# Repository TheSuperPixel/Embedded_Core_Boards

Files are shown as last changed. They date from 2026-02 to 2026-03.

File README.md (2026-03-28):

# 高性能嵌入式核心板套件
## 简介
早在2025年3月的时候，我便想自己设计一套高性能嵌入式系统核心板，主要由MCU、LINUX、FPGA三大部分组成。经过一年左右的学习、设计、焊接和调试，终于全部完成了。目前本开源项目包含RK3588核心板、XC7A35T核心板、STM32H750核心板、全志H616核心板四款板卡。其中RK3588核心板的设计和制作极其复杂和艰难，背后有很多的故事。


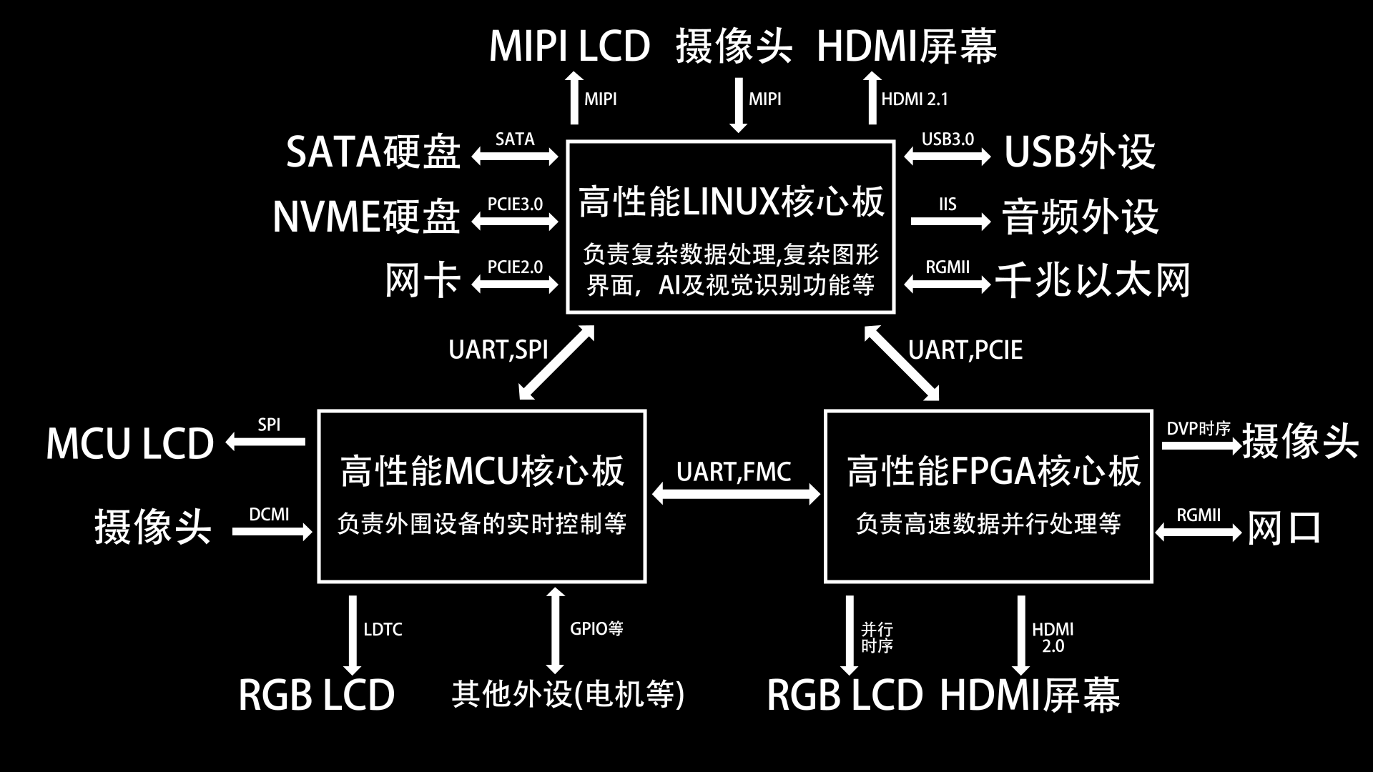
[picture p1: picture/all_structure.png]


## 演示视频
RK3588核心板：https://www.bilibili.com/video/BV1JvcFzpEEX <br>
XC7A35T核心板： https://www.bilibili.com/video/BV11gFkz1Ezn <br>
STM32H750核心板：https://www.bilibili.com/video/BV1rnFhzgESg <br>

## 使用方法
### RK3588 文件夹
RK3588核心板套件的项目资料，详情请阅读文件夹内README文档。<br>

### XC7A35T 文件夹
XC7A35T核心板套件的项目资料，详情请阅读文件夹内README文档。<br>

### STM32H750 文件夹
STM32H750核心板套件的项目资料，详情请阅读文件夹内README文档。<br>

### H616 文件夹
H616核心板套件的项目资料，详情请阅读文件夹内README文档。<br>

## 注意事项
1.请严格遵守开源协议，若需要转载分享仓库内容，请注明来源。不得擅自将本设计用于商业用途。<br>
2.本项目仅供个人研究、学习与交流。元器件、封装、原理图和PCB设计等已根据数据手册重新校验或绘制。若您认为本项目中不慎包含了侵犯您版权的内容，请及时联系，我将第一时间予以处理。
## 主要参考资料
见各核心板项目文件夹内README文档。

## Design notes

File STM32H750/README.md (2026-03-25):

# STM32H750核心板
## 简介
这是我参考反客科技的STM32H750XBH6板子绘制的STM32H750核心板+底板套件，核心板上包含STM32H750XBH6主芯片，外挂32位的16M的大小的SDRAM和32M的FLASH，其余引脚全引出。底板上有摄像头接口、LCD屏幕接口等，还有一个DAP-LINK调试器，只要使用typec线连接电脑，便可以调试程序。

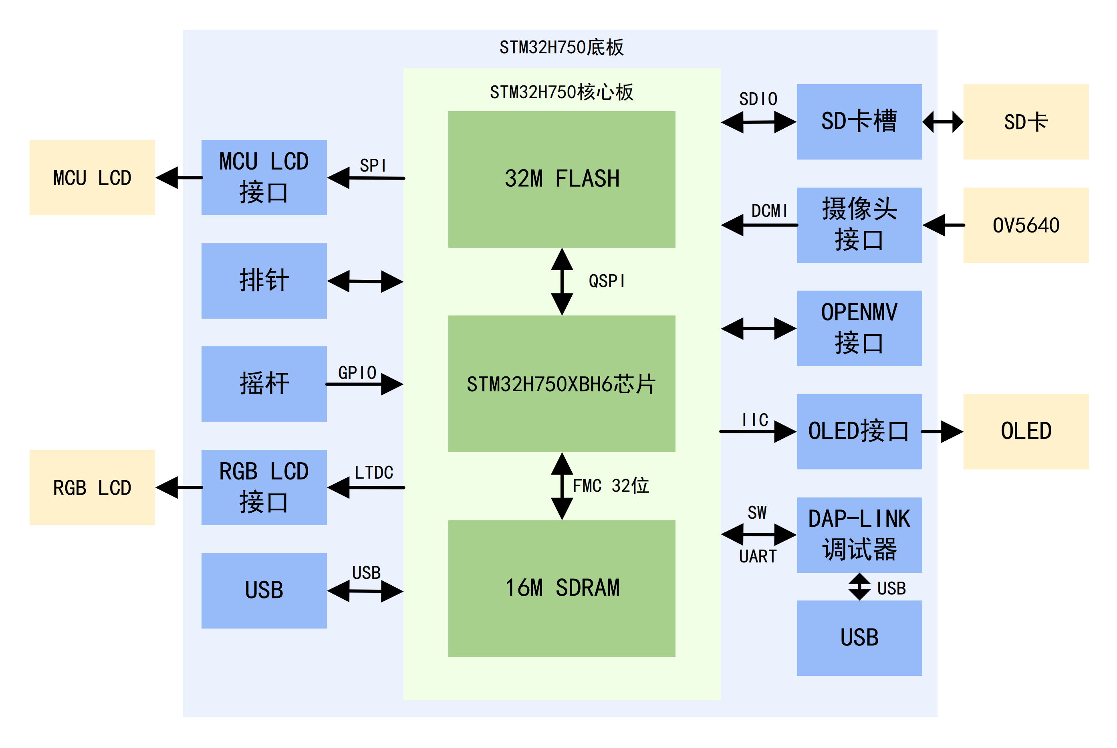
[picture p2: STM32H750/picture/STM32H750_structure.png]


## 演示视频
https://www.bilibili.com/video/BV1rnFhzgESg

## 使用方法
### STM32H750核心板v1 文件夹
第1版核心板的AD工程，已打板测试，需要在嘉立创使用JLC06161H-3313阻抗来打板。此版本的USB部分未经过优化，可能会出现USB无法连接的情况<br>
晶振"X1"应焊接25M晶振，原理图有误； 电容"C32" "C33"均为6pf，原理图有误<br>
进行DRC检查的时候会在板对板连接器固定孔处出现DRC报错，可以忽略，不影响正常电气功能
### STM32H750核心板v2 文件夹

第2版核心板的AD工程，已打板测试，需要在嘉立创使用JLC06161H-3313阻抗来打板。此版本的USB部分已经过优化，所有功能测试正常<br>
晶振"X1"应焊接25M晶振，原理图有误； 电容"C32" "C33"均为6pf，原理图有误<br>
进行DRC检查的时候会在板对板连接器固定孔处出现DRC报错，可以忽略，不影响正常电气功能

### 底板v1 文件夹
第1版底板的AD工程，已打板测试，阻抗无要求。此版本的USB部分未经过优化，可能会出现USB无法连接的情况<br>
进行DRC检查的时候会在板对板连接器固定孔处出现DRC报错，可以忽略，不影响正常电气功能

### 底板v2 文件夹
第2版底板的AD工程，已打板测试，阻抗无要求。此版本的USB部分已经过优化，所有功能测试正常<br>
进行DRC检查的时候会在板对板连接器固定孔处出现DRC报错，可以忽略，不影响正常电气功能

### 0.96寸OLED
0.96寸OLED的AD工程，已打板测试，阻抗无要求。功能正常<br>
支持IIC、SPI以及并口驱动模式，按照元器件的默认值焊接为IIC驱动模式。其中R14和R15排阻作用是选择顶部IIC排针焊盘的电气连接方向，需要选择一个焊接排阻，另一个不焊接。

### 1.69寸SPI接口彩色液晶
1.69寸SPI接口彩色液晶的AD工程，已打板测试，阻抗无要求。功能正常<br>
二极管"D1"的方向画反了，焊接的时候需要按照实际正确方向焊接

### 4.3寸触摸屏
4.3寸触摸屏的AD工程，已打板测试，阻抗无要求。功能正常<br>
驱动板支持正点原子排线线序和反客排线线序，具体位置可查看PCB丝印

### ov5640摄像头
ov5640摄像头的AD工程。已打板测试，阻抗无要求。功能正常<br>
驱动板支持正点原子排线线序和反客排线线序，具体位置可查看PCB丝印<br>
二极管"D1"的方向画反了，焊接的时候需要按照实际正确方向焊接

### 外壳
存放着外壳亚克力设计文件

### 测试例程
存放着测试例程代码，主要参考反客科技STM32H750XBH6资料和江协科技OLED程序

### 其他资料
存放着DAP-LINK固件(推荐使用串口烧录)、调试时记录的《STM32H750调试笔记》

## 主要参考资料
1.反客科技STM32H750XBH6板子 https://www.taobao.com/list/dianpu/212360197.htm<br>
2.江协科技OLED程序 https://jiangxiekeji.com/download.html<br>
3.正点原子RGB LCD 液晶屏资料 http://47.111.11.73/docs/industry/4-lcd/4.3-RGBLCD-800480.html<br>
4.正点原子OV5640资料 http://47.111.11.73/docs/industry/6-other/ov5640.html<br>
5.正点原子OLED资料 http://47.111.11.73/docs/industry/6-other/OLED.html<br>
6.CMSIS DAP LINK设计 https://oshwhub.com/Southerly/daplink-fang-zhen-qi-swd

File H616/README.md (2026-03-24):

# H616核心板
## 简介
这是我在2025年3月的时候参考柚木鉉大佬的Yuzuki Chameleon H616卡片电脑绘制的全志H616开发板，核心板上带有一个无线网卡和EMMC，底板引出了一个USB OTG接口，一个SD卡接口，三个USB host接口一个HDMI接口还有一个网口。


## 使用方法
### H616核心板 文件夹
H616核心板的AD工程，已打板测试，可正常启动，通过串口进入Linux系统。需要在嘉立创使用JLC06161H-3313阻抗来打板。<br>
测试失败的外设：目前EMMC测试失败，导致系统只能从SD卡启动<br>
未测试的外设：板载无线网卡。因为当时2025年3月时我编译驱动一直报错，所以无法测试。

### H616底板 文件夹
H616底板的AD工程，已打板测试。当时是在捷配上面打板的，并向板厂指定了HDMI主要信号线差分100欧姆的阻抗、指定了HDMI其他信号线单端50欧姆的阻抗。如果要在嘉立创打板，需要重新修改线宽。<br>
测试通过的外设：USB OTG接口、SD卡接口、2个USB HOST接口、HDMI接口<br>
测试失败的外设：其中一个USB HOST接口<br>
未测试的外设：网口<br>

### 外壳 文件夹
存放着外壳亚克力设计文件

### 其他资料
存放着调试时记录的《H616调试笔记》

## 主要参考资料
1.Yuzuki Chameleon H616卡片电脑演示视频 https://www.bilibili.com/video/BV1KB4y1z79U<br>
2.Yuzuki Chameleon H616卡片电脑固件和文档资料 https://github.com/YuzukiHD/YuzukiChameleon<br>
3.Yuzuki Chameleon H616卡片电脑硬件资料 https://oshwhub.com/gloomyghost/yuzukih616<br>
This hardware design is a derivative of Yuzuki Chameleon and is licensed under CERN Open Hardware License.

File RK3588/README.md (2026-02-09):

# RK3588核心板
## 简介
这是我参考野火鲁班猫5BTB开发板绘制的RK3588 Linux电脑板卡，核心板性能非常强，有8核高性能CPU，还有GPU，NPU等，还有8GB DDR4运行内存，64GB EMMC存储等。配套底板主要含有PCIE 3.0、HDMI 2.1接口、全功能typec、USB 3.0、SATA、MIPI接口、千兆网口、耳机、喇叭、调试串口、RTC等。


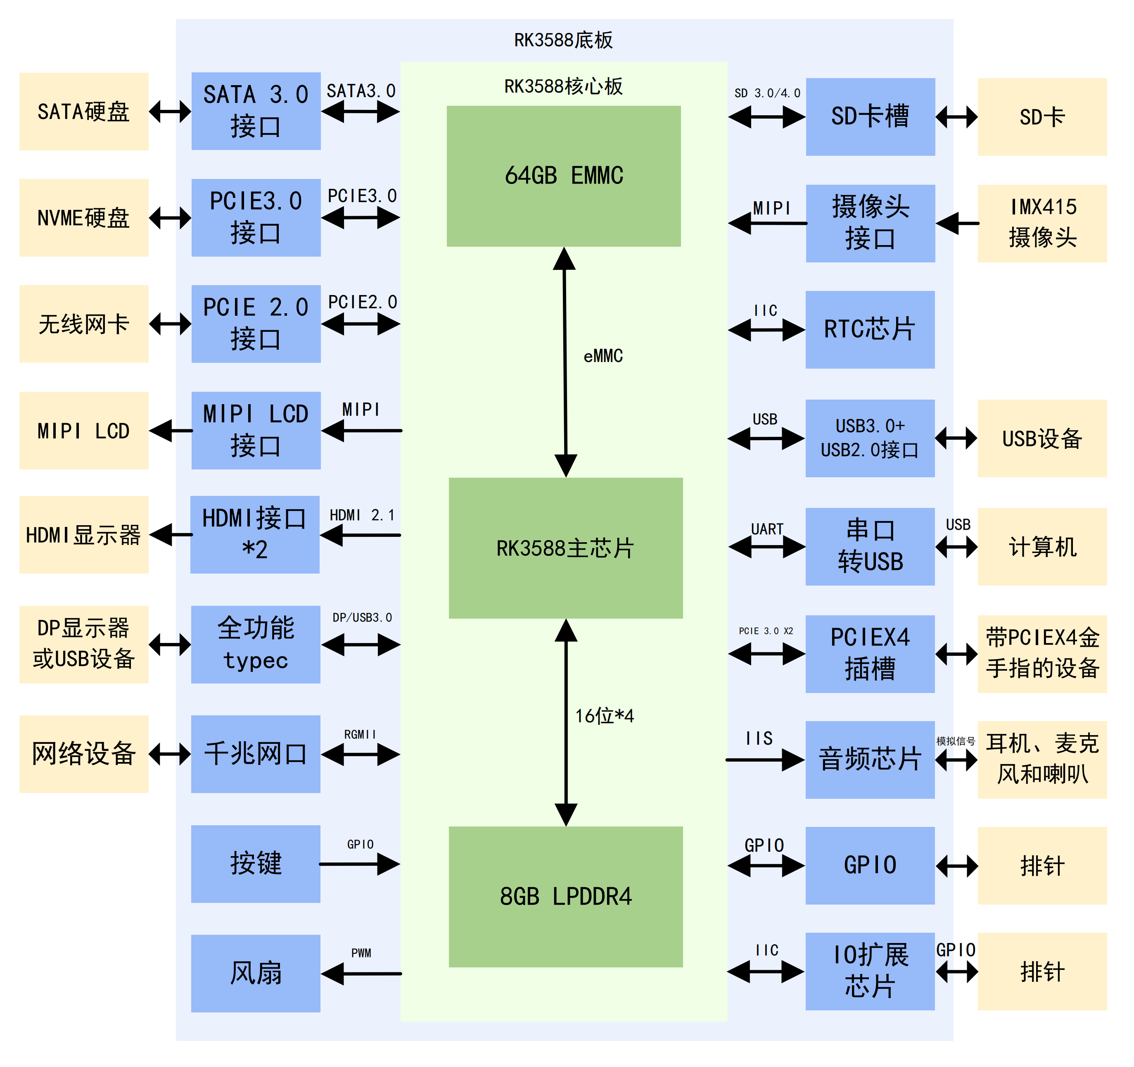
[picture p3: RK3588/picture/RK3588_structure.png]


## 演示视频
https://www.bilibili.com/video/BV1JvcFzpEEX <br>
https://www.xiaohongshu.com/discovery/item/6963a1a3000000001a0259af

## 使用方法
### RK3588核心板 文件夹
RK3588核心板的AD工程，已打板测试，可正常启动，通过串口进入Linux系统。需要在嘉立创使用JLC06161H-3313阻抗来打板。<br>

### RK3588底板 文件夹
RK3588底板的AD工程，已打板测试。需要在嘉立创使用JLC06161H-3313阻抗来打板。<br>

测试通过的接口：PCIE 3.0接口(M2 M KEY，连接NVME硬盘)、PCIE 2.0接口(M2 E KEY，连接无线网卡)、MIPI LCD接口、全功能typec接口、千兆网口、风扇、SD卡槽、摄像头接口、RTC芯片、USB3.0接口、USB2.0接口、串口转USB、音频芯片的耳机接口的扬声器、音频芯片的板载喇叭、音频芯片的板载麦克风。<br>

测试失败的接口：<br>
1.四个启动相关的按钮中，recovery按钮按下后会进入maskroom模式而不是loader模式。目前原因不明。<br>
2.HDMI TX0连接不稳定；HDMI TX1测试失败，目前推测可能是因为核心板电源完整性问题引起的。<br>

未测试的接口：SATA3.0接口、PCIEX4插槽、音频芯片的耳机接口的麦克风、与排针连接的IO扩展芯片的对应引脚和RK3588芯片的对应引脚。

### 5.5寸MIPI屏幕 文件夹
5.5寸MIPI屏幕的AD工程，已打板测试，功能正常。需要在嘉立创使用JLC04161H-3313阻抗来打板。

### IMX415摄像头 文件夹
IMX415摄像头的AD工程，已打板测试，功能正常。需要在嘉立创使用JLC04161H-3313阻抗来打板。

### 外壳 文件夹
存放着外壳亚克力设计文件

### 设备树 文件夹
存放着适配本板卡的设备树文件。<br>
设备树/rk3588-pixelcard-core.dts：单独核心板运行所需的设备树<br>
设备树/rk3588-pixelcard.dts：核心板+底板运行所需的设备树<br>

因为适配板卡系统镜像过大，所以不放在本仓库中。要获得适配板卡的系统镜像，有2个方式：<br>
方法1.将本设备树搭配鲁班猫的LubanCat_Gen_SDK使用，在SDK里面添加这个设备树并重新编译内核与系统。操作思路详见本项目里的《RK3588调试笔记》1-3。具体方法详见野火鲁班猫官网的《嵌入式Linux镜像构建与部署—基于LubanCat-RK系列板卡》。<br>
方法2.在鲁班猫成品系统上面直接替换设备树，换成本文件夹里面的设备树(我自己还没有尝试过)。具体方法详见野火鲁班猫官网的《嵌入式Linux镜像构建与部署—基于LubanCat-RK系列板卡》。<br>

### 其他资料
存放着调试时记录的《RK3588调试笔记》1-3、《RK3588电源调试》、《参考的开源项目汇总》

## 背后的故事
&emsp;&emsp;从2024年1月大二上学期，用树莓派做了很多项目后，我逐渐对树莓派的软件底层和硬件结构产生强烈的好奇，想要自制一个树莓派，不料树莓派的底层软硬件是闭源的，根本就没有办法自制。后来我通过网上搜索的方式知道，树莓派就是一个Linux开发板。在9月份电赛结束之后，我开始了漫长的嵌入式Linux的学习。<br>
&emsp;&emsp;2024年9月大三上开学的时候，我开始看韦东山的0基础驱动与应用开发视频教程，开始的时候，我学得非常吃力，发现原来是因为我的C语言知识过于薄弱造成的。等到后面补完C语言知识，如函数指针，编译优化和结构体对齐等细节之后，我继续看完了韦东山的基础视频。这时候已经是大三上学期结束，进入寒假了。寒假期间，我照着网上墨云大佬的f1c200s项目开始学习，在原本的基础上，加了一个小键盘，做了一个带全键盘的便携Linux小电脑，在这个项目中，我初步了解了嵌入式Linux的系统移植过程。<br>
&emsp;&emsp;之后2025年3月大三下的时候，我想要做更复杂的性能更强的Linux板子，并且能够流畅地运行图形化界面，甚至能够运行AI推理，于是我去网上找新的开源项目。我发现网上一个叫柚木鉉的大佬做的全志H616小电脑，它的图形化界面演示视频吸引了我，并且他的硬件资料也是完整的。可是在硬件制作完成之后，我发现软件资料较少，并且没有教程文档。很多东西都需要自己编译，我还碰到了很多报错，问网上大佬并没有得到非常详细的回答，这时候才知道我的Linux基础有非常大的欠缺，于是我决定重新开始学习嵌入式Linux。<br>
&emsp;&emsp;这时已经是大三下了，保研进入了最后的时期，绩点英语科研竞赛一样都不能落下，还要准备夏令营预推免面试的东西。但是我还是想每天抽点时间来弄一点我自己真正喜欢的东西，我开始阅读琢磨正点原子的Linux开发教程文档，从最基础的cortex-A汇编，C语言裸机，再到uboot源码，Linux内核源码的分析，根文件系统的移植等。断断续续地看了好几个月。在此期间，我被Linux底层原理和处理器底层深深地吸引了，经常看得停不下来。<br>
&emsp;&emsp;在大三下期间，我也开始了新的自制开发版的芯片选型。我看重了瑞芯微最强的RK3588芯片。这个芯片性能非常强，有8核CPU，还有高性能GPU和NPU等。选完芯片之后，我开始挑选对应的开发板来作为设计参考。首先，我选择了我熟悉的正点原子，买了它家的RK3588开发版，可是等到开发版买来之后，我就发现正点原子不提供3588核心板的原理图，连PDF都没有！慢慢地，通过了解多个商家的开发板，我发现许多商家虽然宣传他们开源了很多资料，可是他们基本上只公开软件资料，而硬件资料的公开程度非常有限。而软件资料通常是跟他们对应的硬件资料强绑定的，必须要购买它们家的板子，他们的开源资料才能得到充分的使用。在失望了很长一段时间之后，我又开始选择新的开发版，这次我选择了野火鲁班猫系列的开发板，他们的鲁班猫资料特别全，从核心板硬件原理图到SDK软件包，再到相关的教程文档都非常全。于是我选择购买了鲁班猫的板卡进行复刻。<br>
&emsp;&emsp;在2025年9月大四上学期，保研结束之后，我终于有大量时间来继续做这些事情。从保研结束到11月开始，我陆陆续续看完正点原子的Linux驱动开发、应用开发和QT开发，前前后后有3000多页，记了200多页笔记，含有30多页思维导图和几十张代码逻辑剖析图。此时已经是2025年11月，我终于能够正式的进入RK3588的设计。我找来了瑞芯微官方的硬件设计指南，开始详细的研究鲁班猫5的核心板设计，在完全理解核心板设计内容之后，我便开始了我的RK3588核心板的设计，我在保障板子可以启动Linux的前提下，在参考鲁班猫板卡基础上，修改了大量的硬件外设，使得核心板可以不依赖底板，可以单独启动，并符合嘉立创六层免费打板工艺。核心板性能非常强，有8核高性能CPU，还有GPU，NPU等，还有8GB DDR4运行内存，64GB EMMC存储等。配套底板主要含有PCIE 3.0、HDMI 2.1接口、全功能typec、USB 3.0、SATA、MIPI接口等。<br>
&emsp;&emsp;在绘制过程中，我碰到非常多的问题，我需要在官方硬件设计指南和嘉立创的六层免费打版工艺之间做出合理的权衡，来使得板卡既能运行，又符合嘉立创工艺。其中DDR布线改了三四版，耗时接近一周。核心板画了一个月之后终于画完了，后面两周的焊接调试阶段里，遇到各种各样的电源完整性，虚焊以及Linux内核配置等问题。好在后面通过抓取波形，重新焊接，更换器件和修改设备树等方法，基本解决了问题。在绘制过程中，我记录了非常详细的笔记，便于梳理排查思路，以做出正确的排查方向决策。之后，在2025年12月中旬，核心板终于能够正常的启动Linux系统了！！！<br>
&emsp;&emsp;这个工程实在是太复杂了，涉及了非常多硬件底层和软件底层方面的东西，并且这些东西在网上资料是相对较少的，基本上很难获取。更困难的是，周围同学对嵌入式Linux的理解几乎都是在应用方面，他们在基本上都是为了打比赛或做课设等目的，使用树莓派来进行开发，来快速实现功能，而没有去学习了解一些底层的东西。因此我碰到相关问题只能通过咨询网上大佬，很难得到及时详细回复。更多时候需要自己查资料问AI来解决。我终于突破了厂商的闭源资料的限制，克服了复杂的硬件设计、极其精细的焊接工艺、复杂的Linux内核驱动代码等带来的困难，做出了自己的第一套高性能核心板！！非常感谢正点原子详细的学习教程、野火的详细的资料、各位开源大佬的无私奉献和解答，给我了很多思路和灵感。<br>

## 主要参考资料
1.野火鲁班猫官网 https://doc.embedfire.com/linux/rk356x/quick_start/zh/latest/README.html#<br>
2.瑞芯微官方的《Rockchip RK3588 硬件设计指南》<br>
3.《参考的开源项目汇总》内出现的所有开源项目。由于项目过多，此处不一一列举，详情请查看对应文件。

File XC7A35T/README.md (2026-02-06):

# XC7A35T核心板
## 简介
这是我参考正点原子达芬奇开发板绘制的Xilinx XC7A35T板卡，上面有若干个按钮和LED，还有RGB LCD接口、HDMI接口、网口、SD卡槽、摄像头接口和PCIE金手指接口等外设。还自带Xilinx调试器和两路串口，通过底板自带的USB HUB芯片完成USB信号合并，只需通过一根typec线就可以同时完成供电、FPGA调试和串口收发信息。


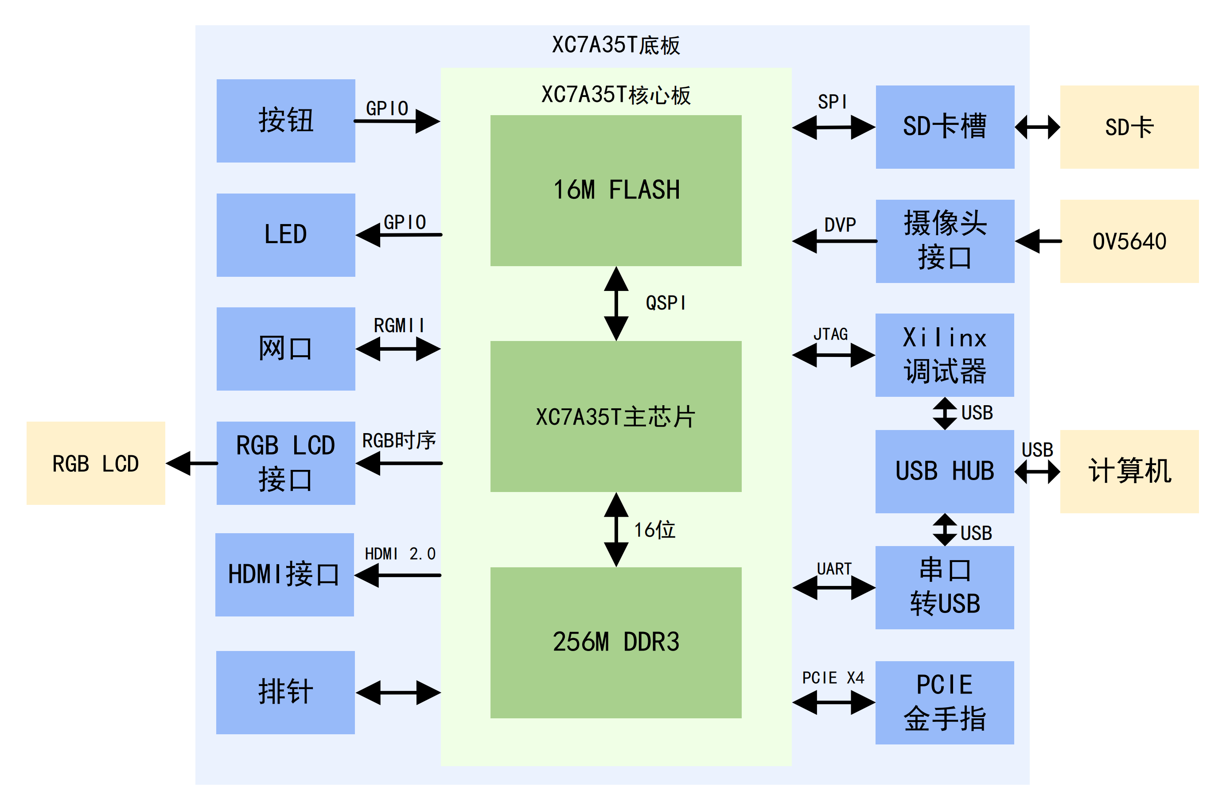
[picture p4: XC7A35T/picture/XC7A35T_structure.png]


## 演示视频
https://www.bilibili.com/video/BV11gFkz1Ezn

## 使用方法
### XC7A35T核心板 文件夹
XC7A35T核心板的AD工程，已打板测试。需要在嘉立创使用JLC06161H-3313阻抗来打板。其中器件U6在 Mechanical1 层上有异常线条，需要手动删除，否则导出Gerber文件时，会出现铜箔短路的问题，导致板子报废无法使用<br>

### XC7A35T底板v1 文件夹
XC7A35T底板v1的AD工程，已打板测试。需要在嘉立创使用JLC04161H-3313阻抗来打板。按钮、LED，RGBLCD接口、HDMI接口、SD卡槽、摄像头接口测试正常。网口测试失败，可能是网口电路布局布线不合理引起的

### XC7A35T底板v2 文件夹
XC7A35T底板v2的AD工程，此版更换了以太网PHY芯片，并优化了网口电路的布局布线，并增加PCIE金手指接口和12V电源输入接口，已打板测试。需要在嘉立创使用JLC04161H-3313阻抗来打板。按钮、LED，RGBLCD接口、HDMI接口、SD卡槽、摄像头接口测试正常。网口进行MDIO测试时，电脑仅能识别到百兆网，而且FPGA板子上用来指示网口速度的用户LED不亮，可能是网口电路布局布线不合理引起的<br>
器件D6、D7、D8在 Mechanical1 层上有异常线条，需要手动删除，否则导出Gerber文件时，会出现铜箔短路的问题，导致板子报废无法使用<br>
电解电容C61画反了，实际焊接的时候需要按照正确方向焊接

### XC7A35T底板v3 文件夹
XC7A35T底板v3的AD工程，此版进一步优化了网口电路的布局布线，已打板测试。需要在嘉立创使用JLC04161H-3313阻抗来打板。按钮、LED，RGBLCD接口、HDMI接口、SD卡槽、摄像头接口测试正常。和之前一样，网口进行MDIO测试时，电脑仅能识别到百兆网，而且FPGA板子上用来指示网口速度的用户LED不亮。目前原因不明。<br>
电解电容C61画反了，实际焊接的时候需要按照正确方向焊接

### 外壳
存放着外壳亚克力设计文件

### 测试例程
存放着测试例程代码，主要参考正点原子达芬奇FPGA资料。

### 其他资料
存放着xilinx下载器固件、调试时记录的《XC7A35T调试笔记》

### 其他
4.3寸触摸屏和ov5640摄像头的AD工程位于STM32H750开发板的资料底下，请到对应位置查找

## 主要参考资料
1.正点原子达芬奇FPGA开发板资料 http://47.111.11.73/docs/book-videos/zdyzshipin/3fpga/dfq.html<br>
2.正点原子RGB LCD 液晶屏资料 http://47.111.11.73/docs/industry/4-lcd/4.3-RGBLCD-800480.html<br>
3.正点原子OV5640资料 http://47.111.11.73/docs/industry/6-other/ov5640.html?highlight=ov5640<br>
4.给FT232芯片烧录固件作为Xilinx下载器的方法 https://blog.csdn.net/weixin_42741023/article/details/106462147

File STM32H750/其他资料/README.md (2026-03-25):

# Third-Party Source Notice (第三方代码声明)

## 来源说明
本目录下的文件来自 https://oshwhub.com/Southerly/daplink-fang-zhen-qi-swd

## 版权与协议 (Copyright & License)
* **版权归属：** 版权归原作者所有。
* **引用目的：** 本项目仅将其作为硬件验证的参考驱动使用。

## 免责声明
本项目作者 (TheSuperPixel) 不对本目录下的文件质量、稳定性或潜在侵权风险负责。

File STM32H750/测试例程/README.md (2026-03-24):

# Third-Party Source Notice (第三方代码声明)

## 来源说明
本目录下的OLED文件夹代码及工程文件（包括但不限于底层驱动、寄存器配置、初始化脚本）由 **江协科技** 提供。<br>
本目录下的其他文件夹代码及工程文件（包括但不限于底层驱动、寄存器配置、初始化脚本）由 **反客科技** 提供。

## 版权与协议
* **版权归属：** 版权归原作者所有。
* **引用目的：** 本项目仅将其作为硬件验证的参考驱动使用。

## 免责声明
本项目作者 (TheSuperPixel) 不对本目录下的代码质量、稳定性或潜在侵权风险负责。

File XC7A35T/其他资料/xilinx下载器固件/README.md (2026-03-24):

# Third-Party Source Notice (第三方代码声明)

## 来源说明
本目录下的文件来自 https://blog.csdn.net/weixin_42741023/article/details/106462147

## 版权与协议 (Copyright & License)
* **版权归属：** 版权归原作者所有。
* **引用目的：** 本项目仅将其作为硬件验证的参考驱动使用。

## 免责声明
本项目作者 (TheSuperPixel) 不对本目录下的文件质量、稳定性或潜在侵权风险负责。

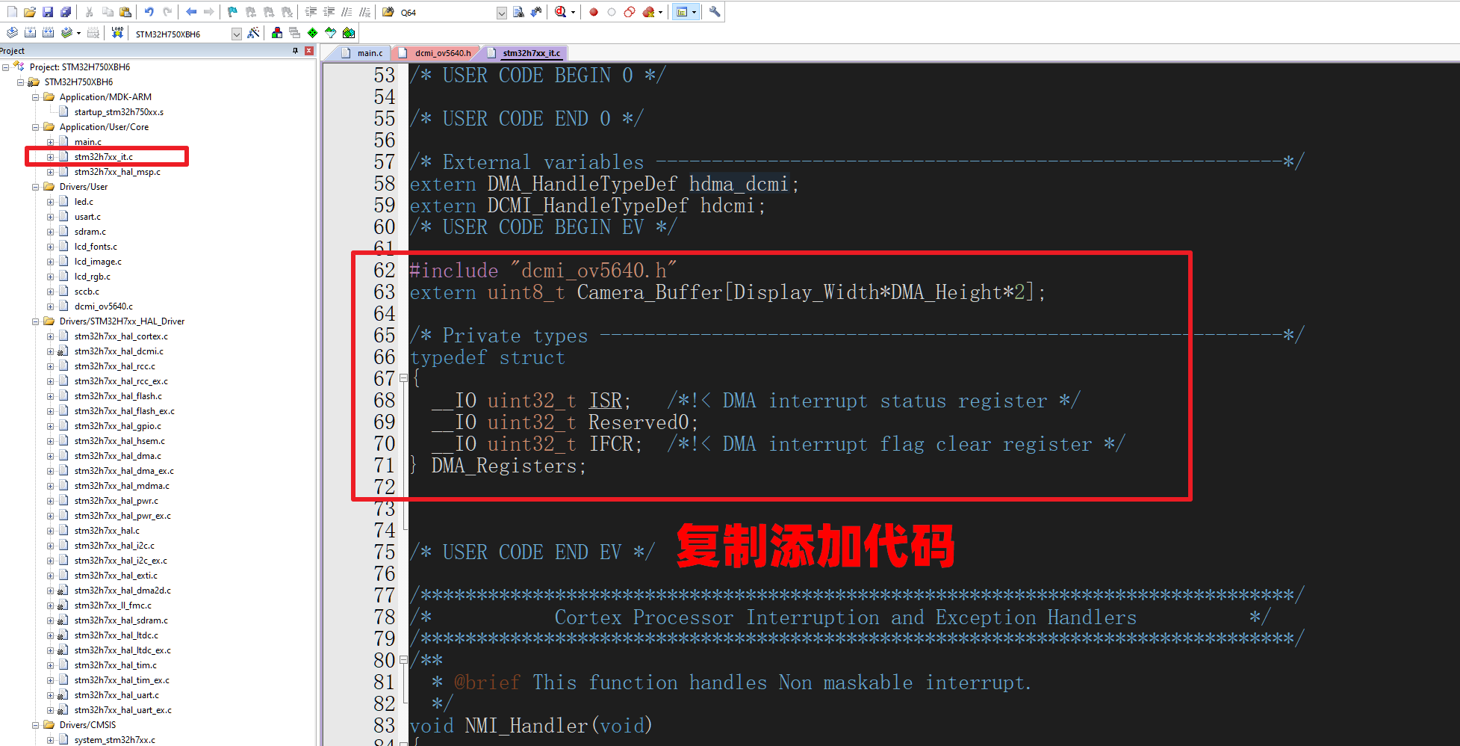
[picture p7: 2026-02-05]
STM32H750/测试例程/DCMI-摄像头OV5640驱动/图像显示到800x480分辨率的屏幕/移植注意事项2.png

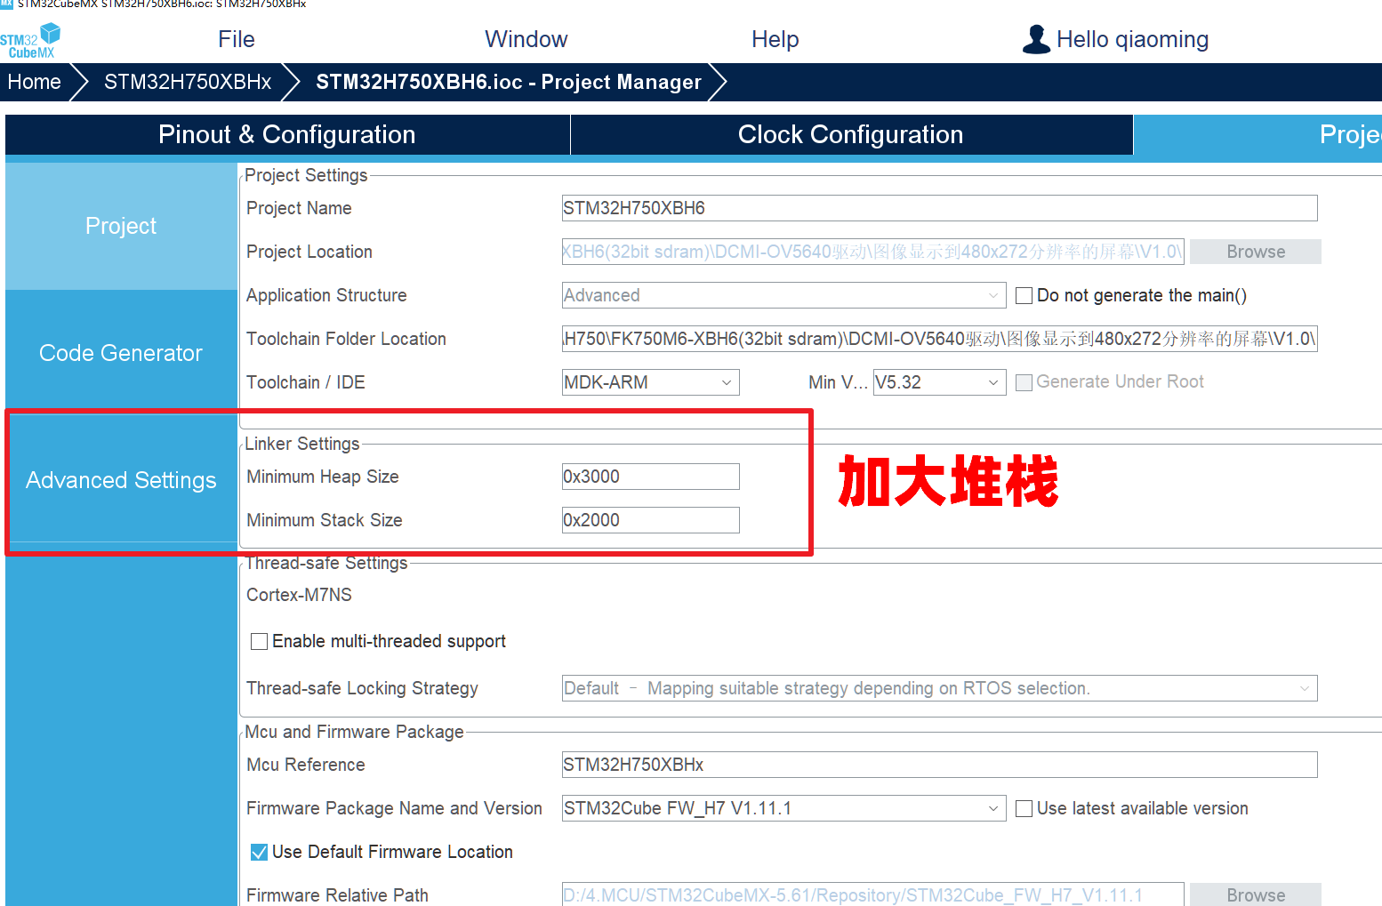
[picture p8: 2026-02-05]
STM32H750/测试例程/DCMI-摄像头OV5640驱动/图像显示到800x480分辨率的屏幕/移植注意事项1.png

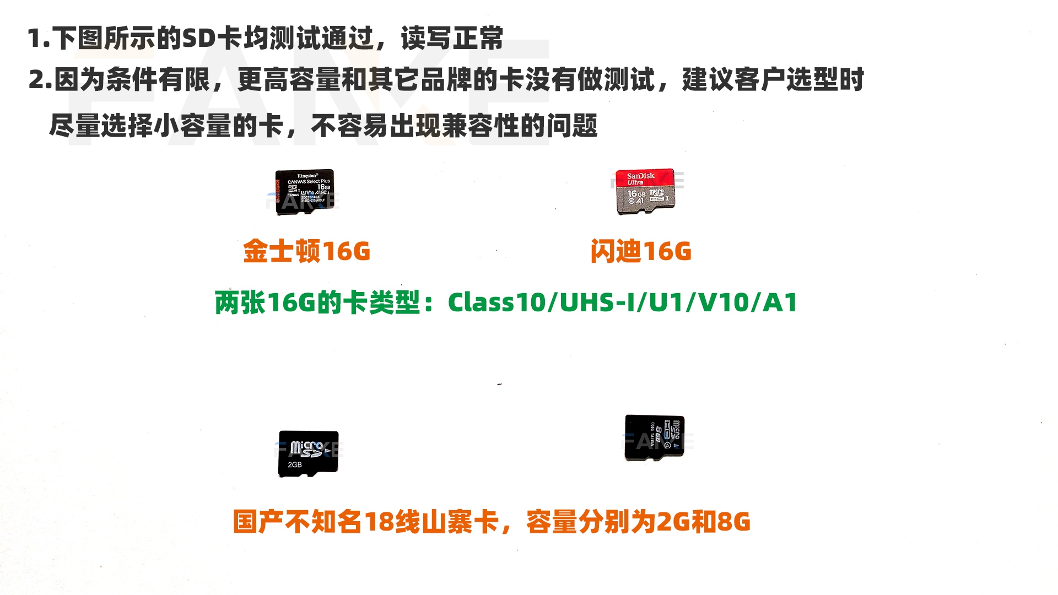
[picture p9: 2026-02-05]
STM32H750/测试例程/SDIO-基本数据读写/SD卡选型建议.jpg

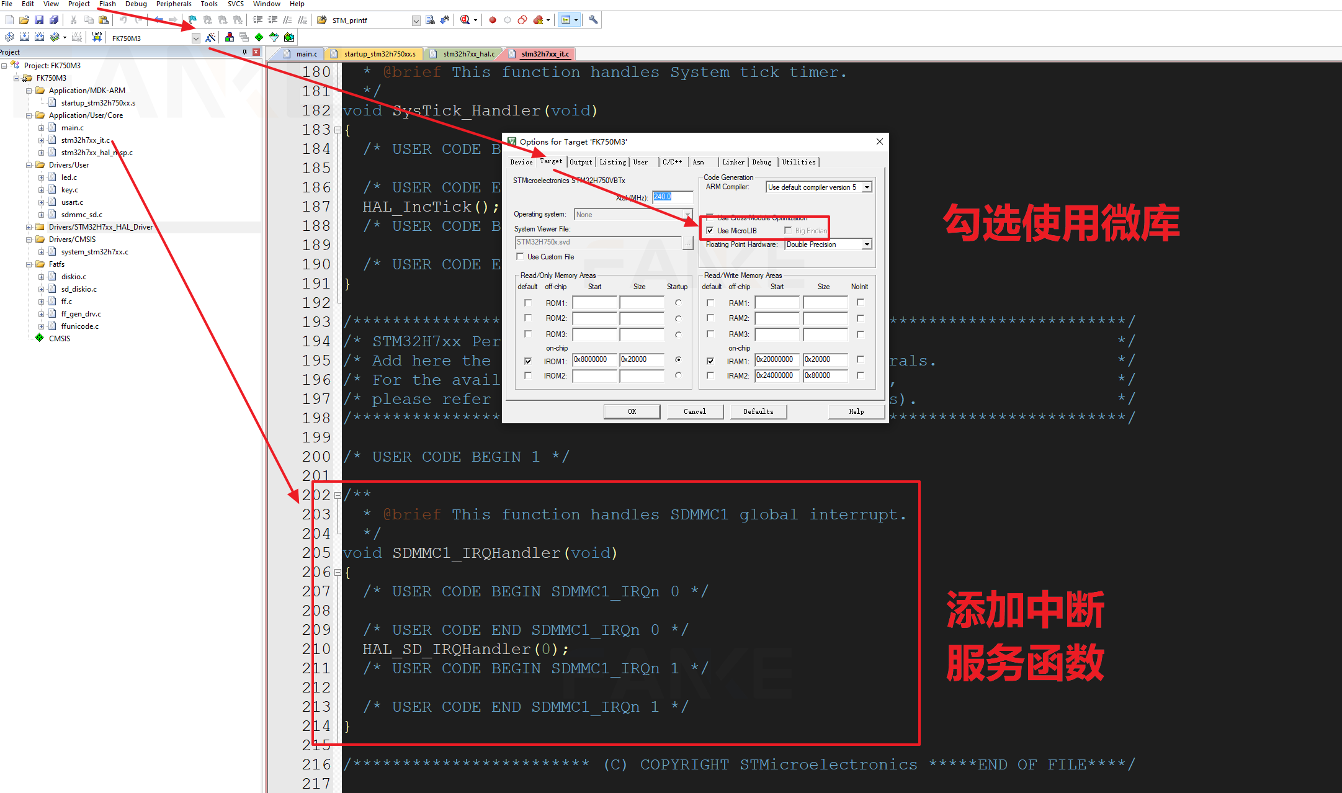
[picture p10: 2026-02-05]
STM32H750/测试例程/SDIO-基本数据读写/SD卡驱动移植注意事项.png

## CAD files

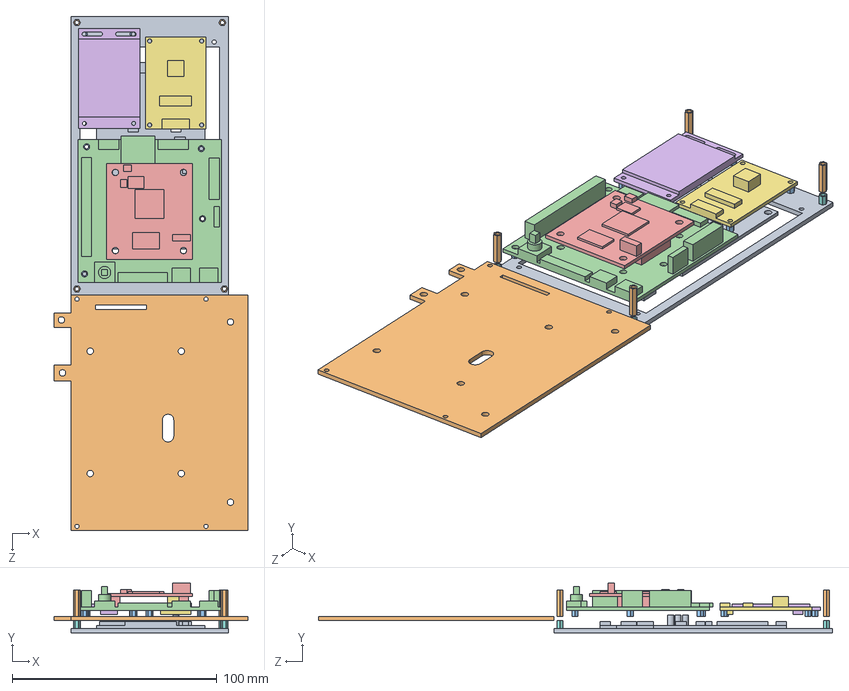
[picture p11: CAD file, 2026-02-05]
STM32H750/外壳/STM32H750板子.SLDASM
94.6 x 24.2 x 251.0 mm
中层亚克力
M2-3铜柱 x 12
底板
核心板
MCU LCD屏幕
OV5640摄像头
M2-4铜柱 x 4
底层亚克力
4.3寸RGB驱动
M2-13铜柱 x 4

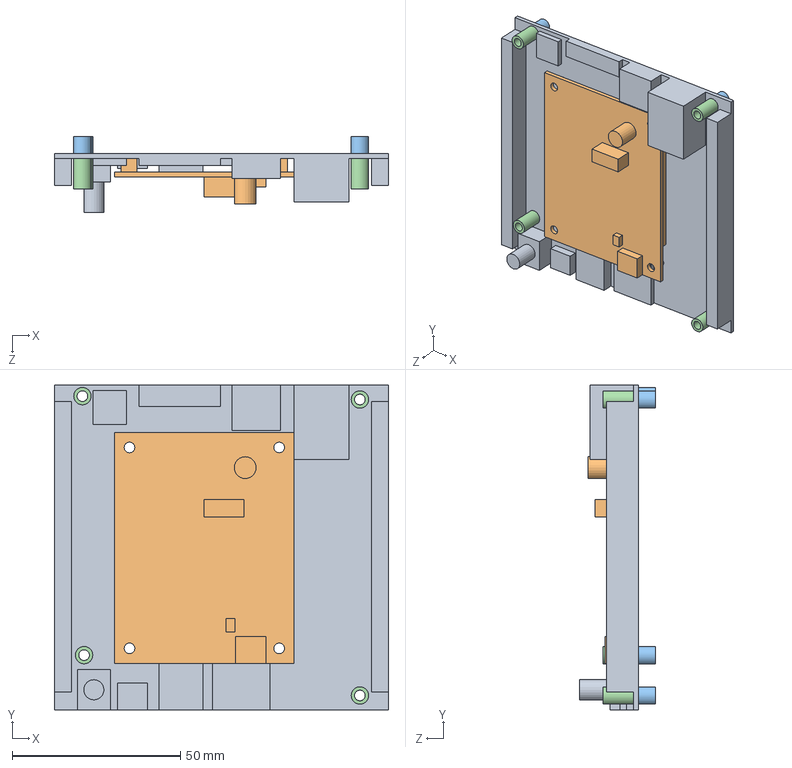
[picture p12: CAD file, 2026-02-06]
XC7A35T/外壳/全排针版本/装配体2.SLDASM
99.3 x 96.6 x 22.5 mm
底板
核心板
底部铜柱 x 4
顶部铜柱 x 4

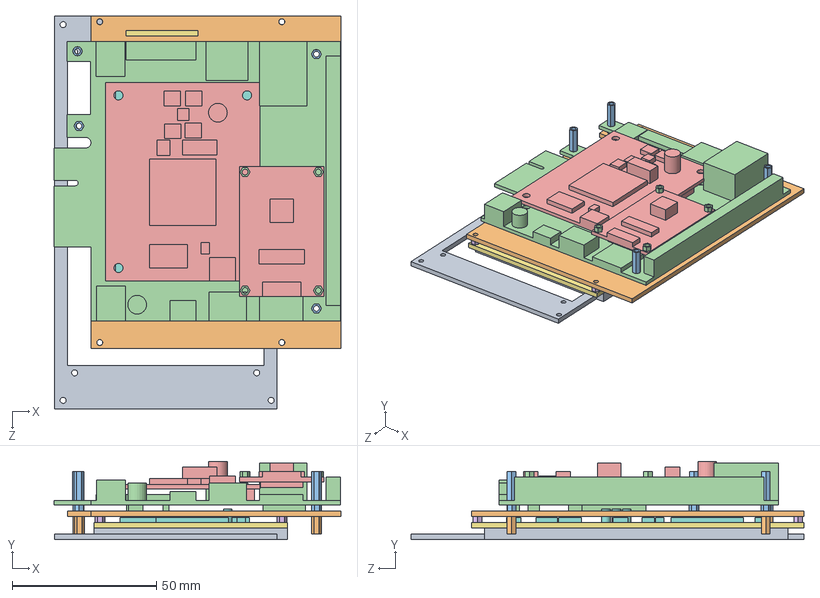
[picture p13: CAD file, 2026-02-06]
XC7A35T/外壳/PCIE版本/XC7A35T板子.SLDASM
99.3 x 27.1 x 136.0 mm
中层亚克力
M2-2铜柱_底板 x 4
底板_PCIE
核心板
M2-2铜柱_RGB屏幕 x 4
屏幕亚克力
4.3寸RGB驱动
底层亚克力
4.3寸RGB屏幕
M2-6铜柱 x 4
M2-10铜柱 x 4
M2-2铜柱_摄像头 x 4
OV5640摄像头

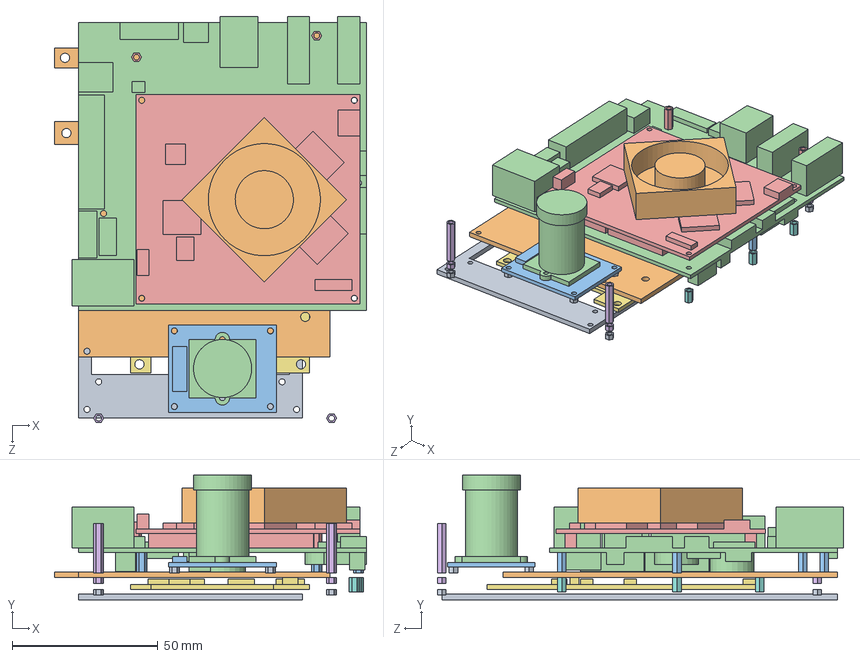
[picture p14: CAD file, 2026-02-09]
RK3588/外壳/RK3588板子.SLDASM
107.2 x 42.8 x 139.5 mm
中层亚克力
M2-7铜柱 x 4
底板
核心板
M2-2铜柱_LCD1 x 4
MIPI屏幕驱动
M2-5铜柱 x 3
M2-2铜柱_LCD2 x 8
底层亚克力
风扇
IMX415板子
镜头模组
M2-9铜柱 x 2
M2-17铜柱 x 2

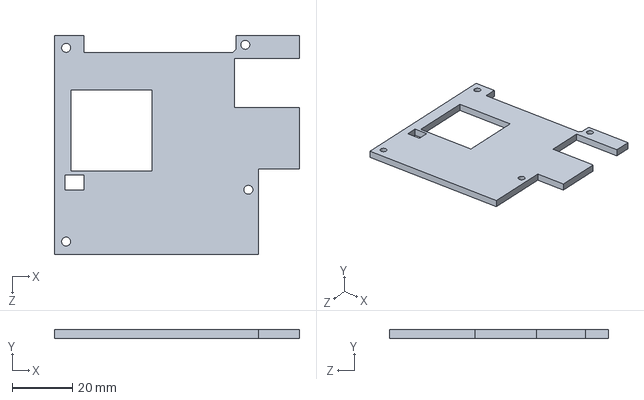
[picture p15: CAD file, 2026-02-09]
H616/外壳/顶板.SLDPRT
81.6 x 3.00 x 73.0 mm

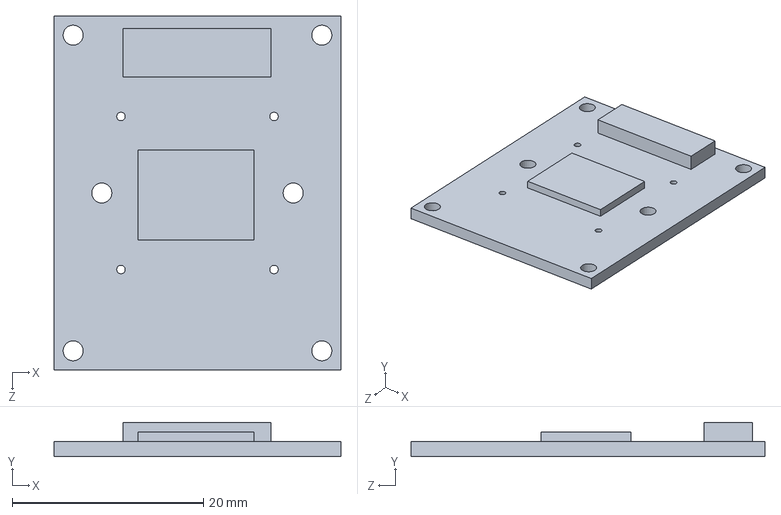
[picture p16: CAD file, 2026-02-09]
RK3588/外壳/IMX415板子.SLDPRT
30.0 x 3.60 x 37.0 mm

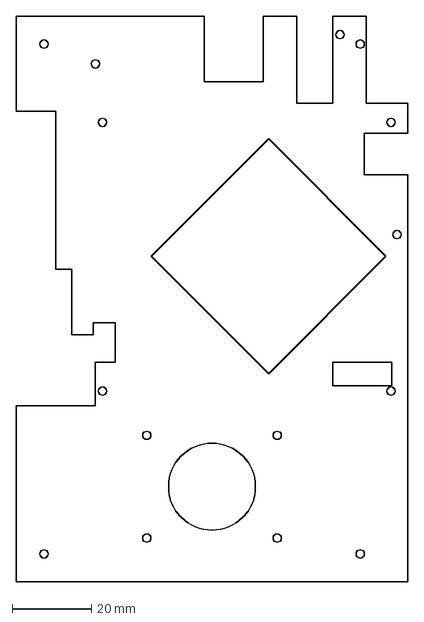
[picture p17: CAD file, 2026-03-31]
RK3588/外壳/输出图纸/顶层亚克力.DXF
99.0 x 143.0 mm

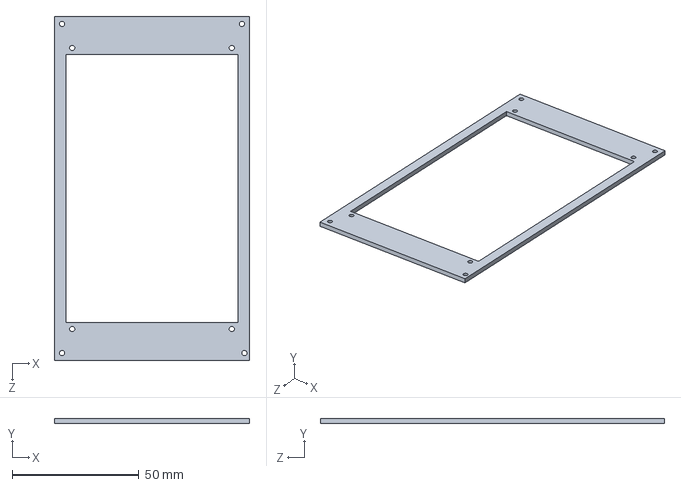
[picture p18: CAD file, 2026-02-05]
STM32H750/外壳/底层亚克力.SLDPRT
77.0 x 2.00 x 136.0 mm

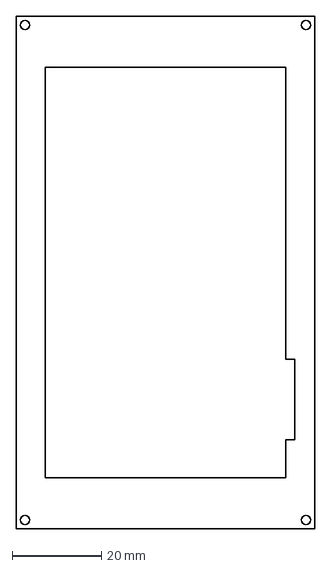
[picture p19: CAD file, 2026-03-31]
STM32H750/外壳/输出图纸/屏幕亚克力.DXF
67.0 x 115.0 mm

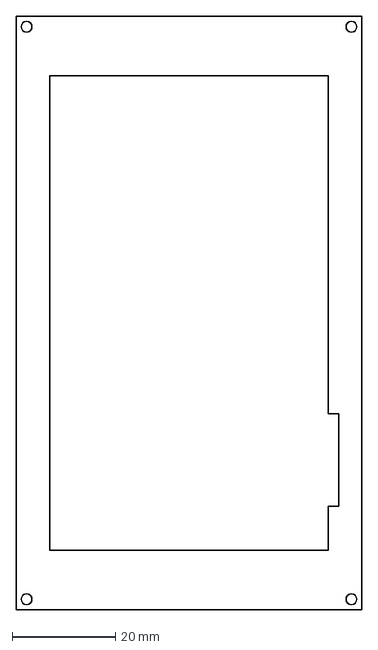
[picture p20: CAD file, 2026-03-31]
XC7A35T/外壳/PCIE版本/输出图纸/屏幕亚克力.DXF
67.0 x 115.0 mm

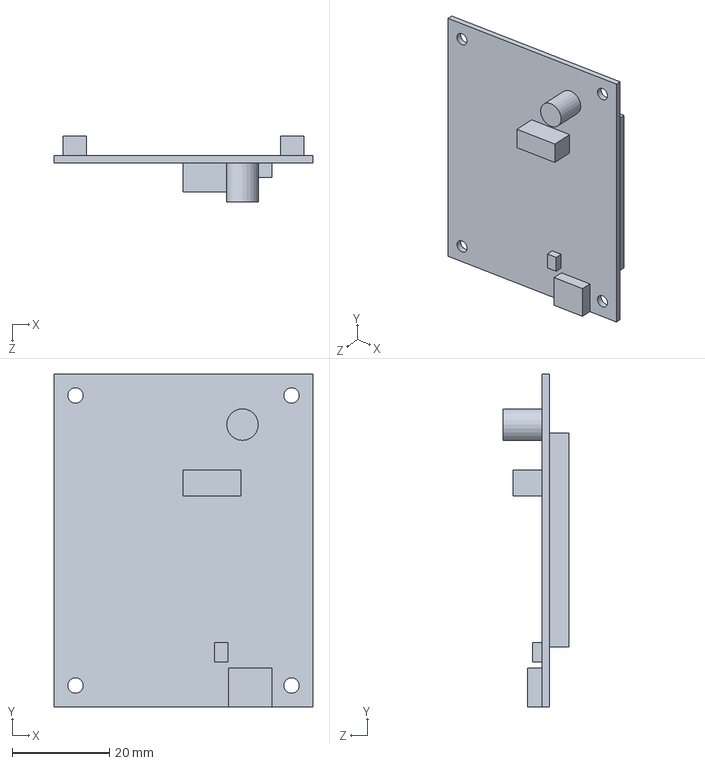
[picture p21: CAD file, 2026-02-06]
XC7A35T/外壳/全排针版本/核心板.SLDPRT
53.3 x 68.6 x 13.5 mm

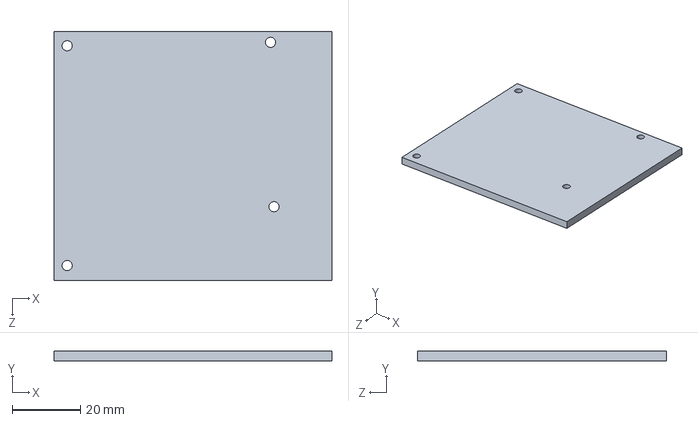
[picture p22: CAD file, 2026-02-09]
H616/外壳/底板.SLDPRT
81.6 x 3.00 x 73.0 mm

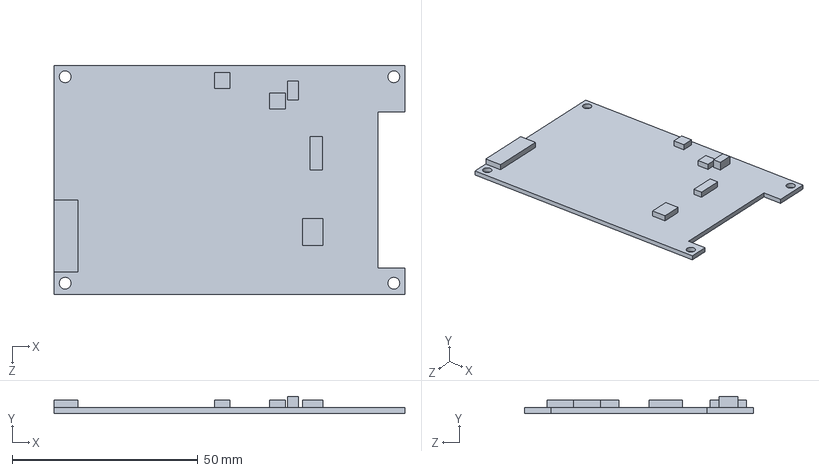
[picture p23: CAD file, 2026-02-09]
RK3588/外壳/MIPI屏幕驱动.SLDPRT
94.4 x 4.60 x 61.5 mm

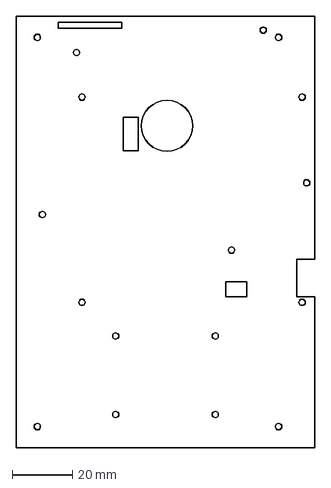
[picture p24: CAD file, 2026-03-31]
RK3588/外壳/输出图纸/中层亚克力.DXF
99.0 x 143.0 mm

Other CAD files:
XC7A35T/外壳/全排针版本/输出图纸/底部亚克力.DWG
STM32H750/外壳/底板.SLDPRT
STM32H750/外壳/输出图纸/底层亚克力.DXF
XC7A35T/外壳/PCIE版本/中层亚克力.SLDPRT
H616/外壳/底板.DXF
H616/外壳/顶板.DXF
RK3588/外壳/M2-17铜柱.SLDPRT
RK3588/外壳/M2-2铜柱_LCD1.SLDPRT
RK3588/外壳/M2-2铜柱_LCD2.SLDPRT
RK3588/外壳/M2-5铜柱.SLDPRT
RK3588/外壳/M2-7铜柱.SLDPRT
RK3588/外壳/M2-9铜柱.SLDPRT
RK3588/外壳/MIPI屏幕.SLDPRT
RK3588/外壳/MIPI屏幕亚克力.SLDPRT
RK3588/外壳/中层亚克力.SLDPRT
RK3588/外壳/底层亚克力.SLDPRT
RK3588/外壳/底板.SLDPRT
RK3588/外壳/核心板.SLDPRT
RK3588/外壳/输出图纸/MIPI屏幕亚克力.DWG
RK3588/外壳/输出图纸/MIPI屏幕亚克力.DXF
RK3588/外壳/输出图纸/中层亚克力.DWG
RK3588/外壳/输出图纸/底层亚克力.DWG
RK3588/外壳/输出图纸/底层亚克力.DXF
RK3588/外壳/输出图纸/顶层亚克力.DWG
RK3588/外壳/镜头模组.SLDPRT
RK3588/外壳/顶层亚克力.SLDPRT
RK3588/外壳/风扇.SLDPRT
STM32H750/外壳/4.3寸RGB驱动.SLDPRT
STM32H750/外壳/M2-13铜柱.SLDPRT
STM32H750/外壳/M2-3铜柱.SLDPRT
STM32H750/外壳/M2-4铜柱.SLDPRT
STM32H750/外壳/MCU LCD屏幕.SLDPRT
STM32H750/外壳/OLED屏幕.SLDPRT
STM32H750/外壳/OV5640摄像头.SLDPRT
STM32H750/外壳/中层亚克力.SLDPRT
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

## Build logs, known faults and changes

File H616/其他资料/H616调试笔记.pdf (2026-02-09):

# H616 调试笔记

## 1.使用别人的嘉立创开源工程导入 AD，发现预览异常，且导出焊接辅助工具预览时异常，

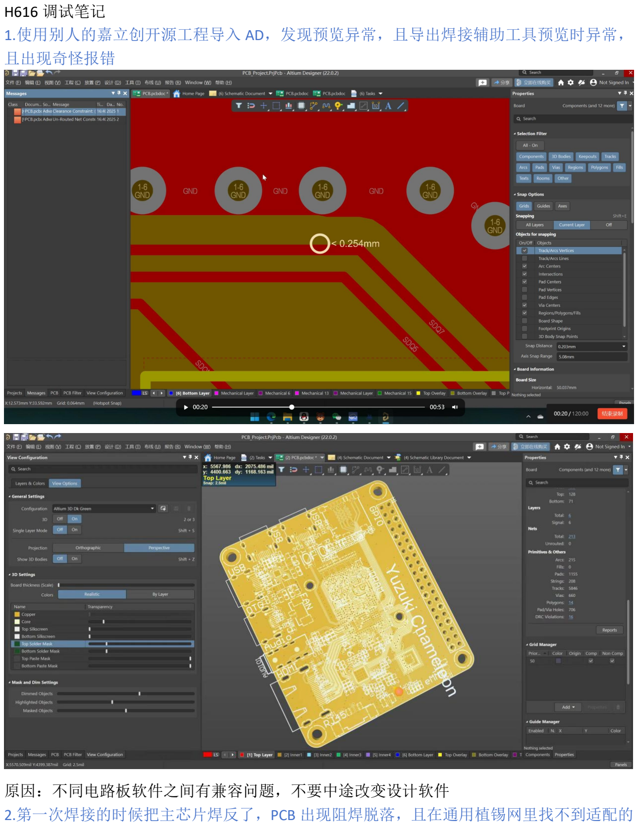
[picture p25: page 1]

## 且出现奇怪报错

## 原因：不同电路板软件之间有兼容问题，不要中途改变设计软件 2.第一次焊接的时候把主芯片焊反了，PCB 出现阻焊脱落，且在通用植锡网里找不到适配的

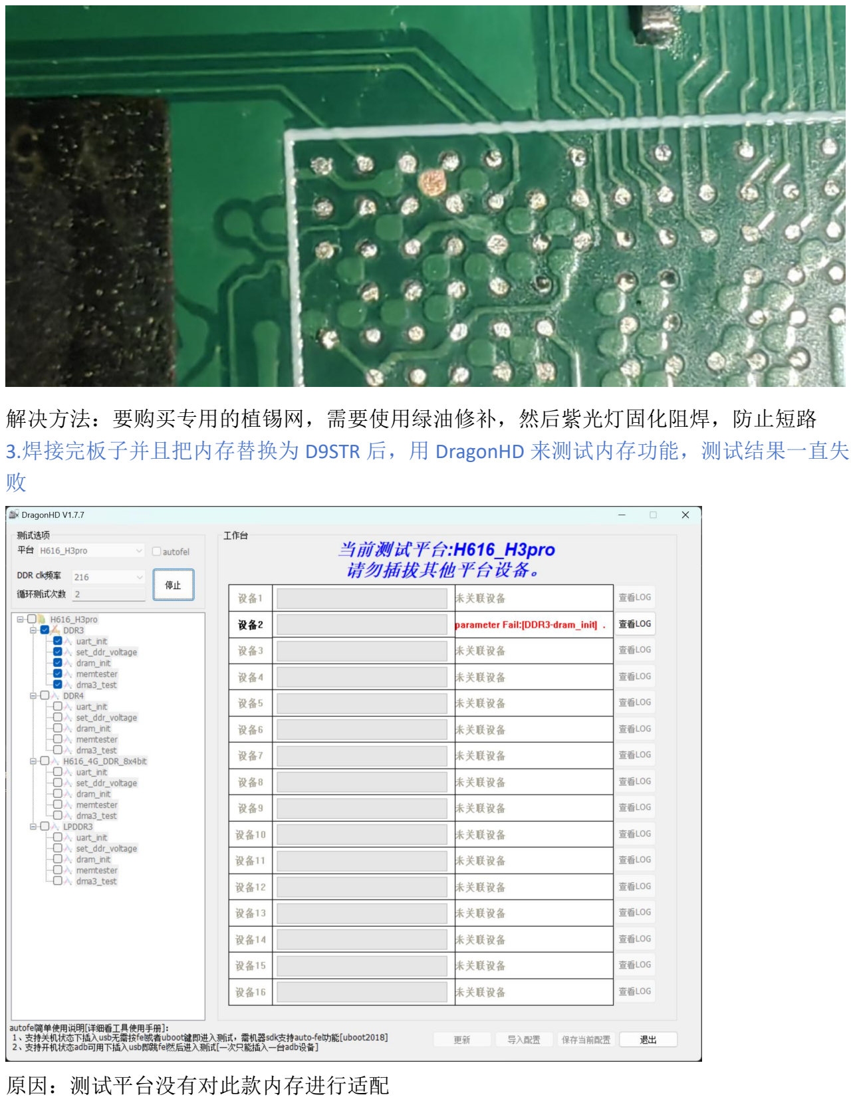
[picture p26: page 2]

## 解决方法：要购买专用的植锡网，需要使用绿油修补，然后紫光灯固化阻焊，防止短路 3.焊接完板子并且把内存替换为 D9STR 后，用 DragonHD 来测试内存功能，测试结果一直失

败

## 原因：测试平台没有对此款内存进行适配

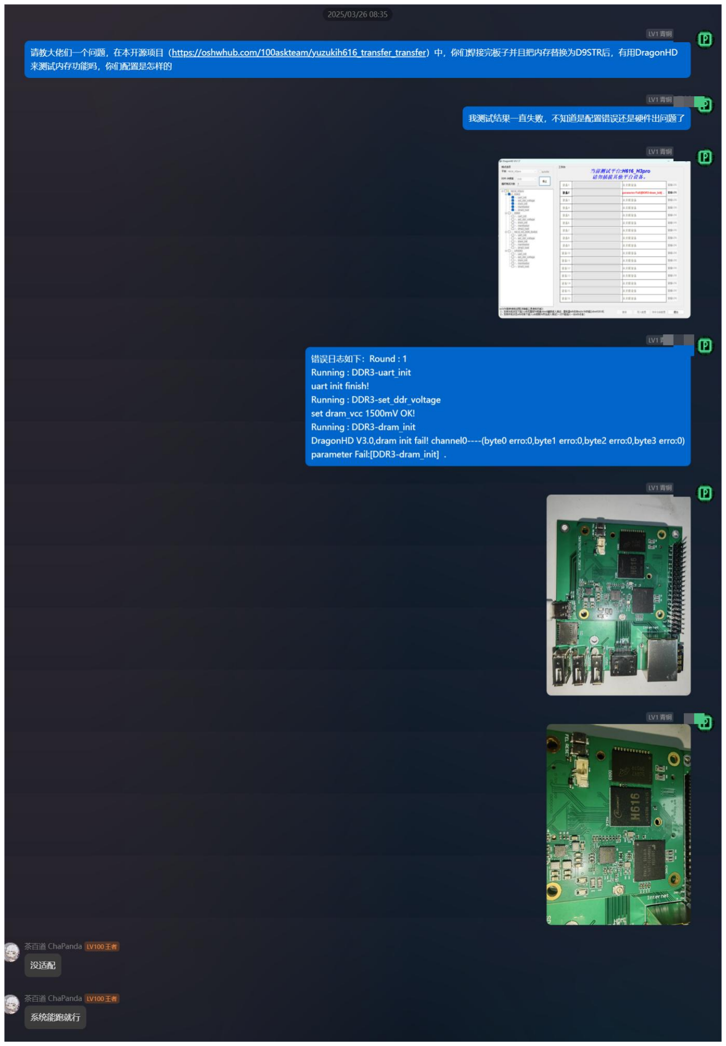
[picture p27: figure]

## 4.一直找不到合适的镜像

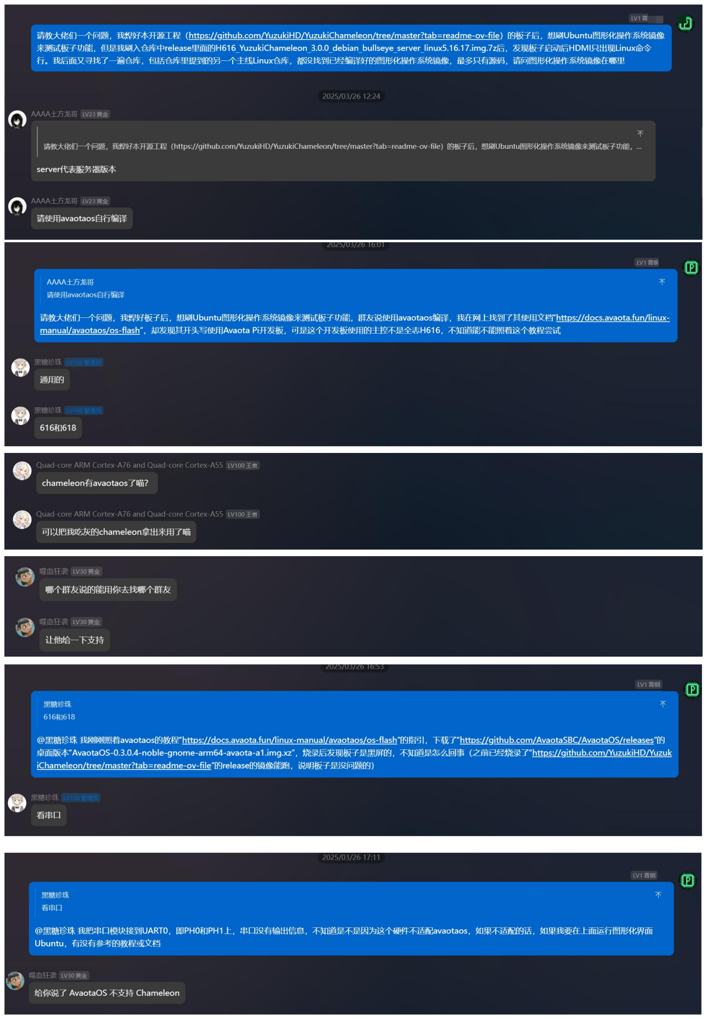
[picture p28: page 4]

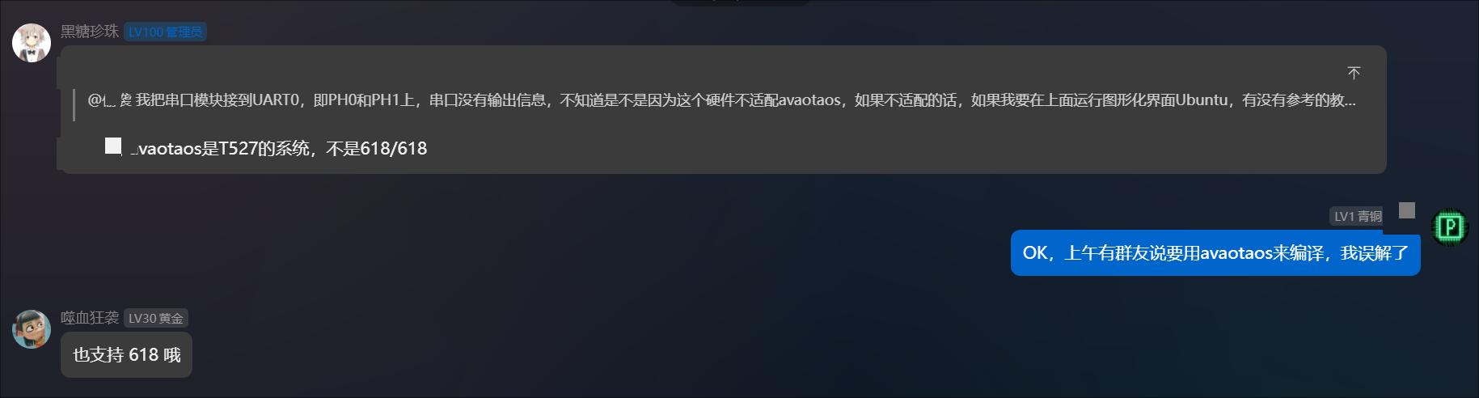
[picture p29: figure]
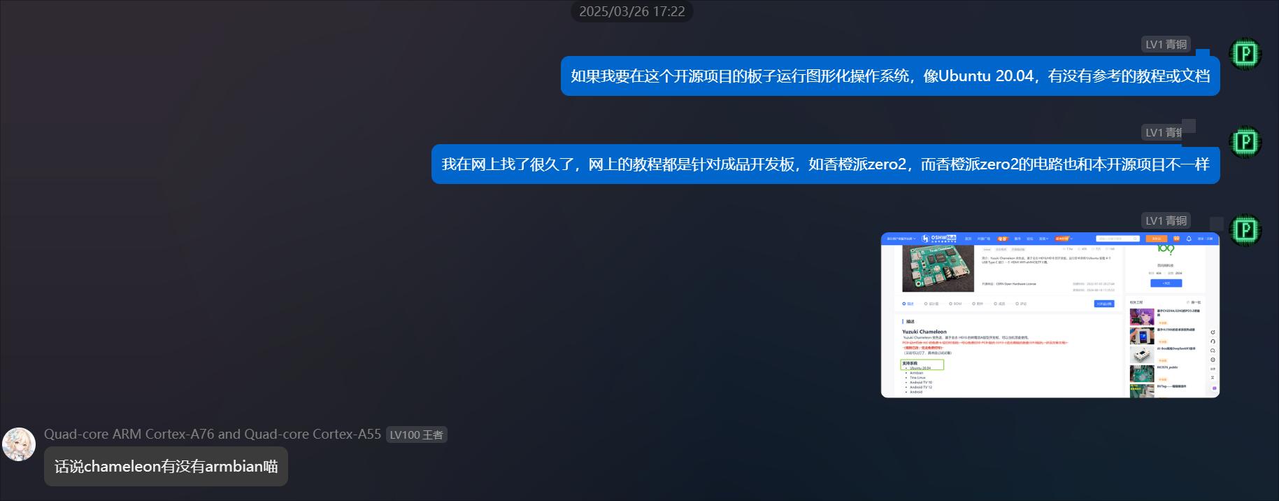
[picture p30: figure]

## 原因：这个开源工程相关资料并没有消费级开发板那么完善，最好直接复刻消费级开发板方

案

# 5. docker 镜像一直无法下载

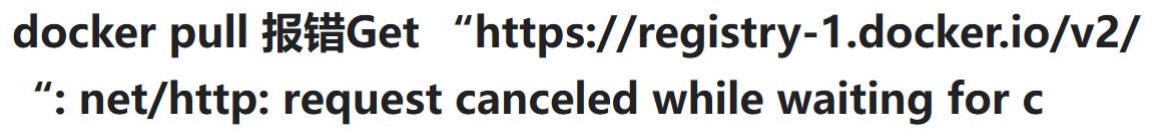
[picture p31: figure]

## 解决办法：切换网络 6.烧录 docker 编译的镜像后，黑屏 原因：emmc 和 SD 卡镜像烧录方式不一样，且编译配置不同

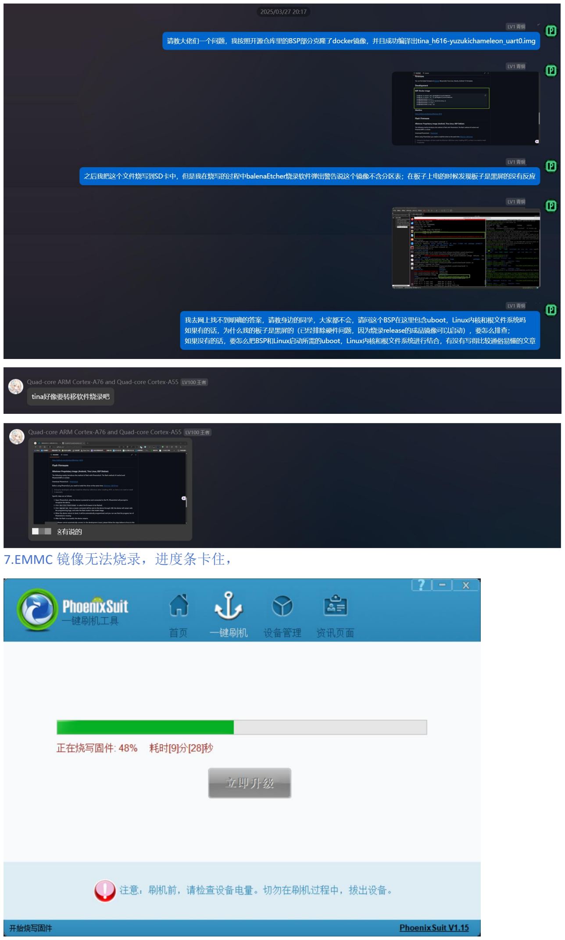
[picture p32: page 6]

## 7.EMMC 镜像无法烧录，进度条卡住，

## 错误信息：

[20335]fes begin commit:a00ebdcb84 [20338]set pll start
[20341]periph0 has been enabled [20344]set pll end
[20347]unknow PMU
[20349]unknow PMU
[20353]PMU: AXP1530
[20358]vaild para:1 select dram para0 [20361]board init ok
[20363]beign to init dram
[20366]DRAM BOOT DRIVE INFO: V0.651 [20369]the chip id is 0x5000 [20372]chip id check OK
[20394]DRAM_VCC set to 1500 mv [20400]read_calibration error [20406]read_calibration error [20412]read_calibration error [20418]read_calibration error [20423]read_calibration error [20429]read_calibration error [20435]read_calibration error [20441]read_calibration error [20447]read_calibration error [20453]read_calibration error [20456]retraining final error [20461]read_calibration error [20467]read_calibration error [20473]read_calibration error [20479]read_calibration error [20484]read_calibration error [20490]read_calibration error [20496]read_calibration error [20502]read_calibration error [20507]read_calibration error [20513]read_calibration error
[20516]retraining final error
[20522][AUTO DEBUG]16 bit,2 ranks training success!
[20533]DRAM CLK =792 MHZ
[20535]DRAM Type =3 (3:DDR3,4:DDR4,7:LPDDR3,8:LPDDR4) [20544]Actual DRAM SIZE =2048 M
[20547]DRAM SIZE =2048 MBytes, para1 = 310a, para2 = 8001001, dram_tpr13 = 6041 [20556]DRAM simple test OK. [20558]rtc standby flag is 0x0, super standby flag is 0x0
[20564]init dram ok U-Boot 2018.05 (Mar 27 2025 - 09:22:23 +0000) Allwinner Technology

[23.723]CPU: Allwinner Family
[23.726]Model: sun50iw9
I2C: ready
[23.730]DRAM: 512 MiB
[23.733]Relocation Offset is: 15ebf000 [23.768]secure enable bit: 0 [23.772]pmu_axp152_probe pmic_bus_read fail [23.776]PMU: AXP1530 [23.777]PMU: pmu_axp1530 found [23.783]dcdc1_vol = 960, onoff=1 [23.786]dcdc2_vol = 1000, onoff=1
[23.790]aldo1_vol = 1800, onoff=1
[23.793]dldo1_vol = 3300, onoff=1
[23.796]CPU=1008 MHz,PLL6=600 Mhz,AHB=200 Mhz, APB1=100Mhz MBus=400Mhz [23.802]gic: normal mode
[23.805]try fast burn key
[23.808]out of usb burn from boot: not boot mode
[23.813]flash init start
[23.815]workmode = 16,storage type = 0
try card 2
set card number 2
get card number 2
[23.823][mmc]: mmc driver ver uboot2018:2021-07-19 14:09:00 [23.829][mmc]: get sdc_type fail and use default host:tm4. [23.840][mmc]: Is not Boot mode! [23.843][mmc]: SUNXI SDMMC Controller Version:0x40502 [23.854][mmc]: ************Try SD card 2************ [23.859][mmc]: mmc 2 cmd timeout 100 status 100 [23.863][mmc]: smc 2 err, cmd 8, RTO
[23.867][mmc]: mmc 2 close bus gating and reset [23.872][mmc]: mmc 2 cmd timeout 100 status 100 [23.876][mmc]: smc 2 err, cmd 55, RTO
[23.879][mmc]: mmc 2 close bus gating and reset [23.884][mmc]: ************Try MMC card 2************ [23.926][mmc]: mmc 2 cmd timeout 100 status 100 [23.930][mmc]: smc 2 err, cmd 8, RTO
[23.933][mmc]: mmc 2 close bus gating and reset [23.938][mmc]: mmc 2 cmd timeout 100 status 100 [23.942][mmc]: smc 2 err, cmd 55, RTO [23.946][mmc]: mmc 2 close bus gating and reset [23.980][mmc]: gen_tuning_blk_bus8: total blk 10 [23.984][mmc]: gen_tuning_blk_bus4: total blk 6 [23.988][mmc]: Using 8 bit tuning now [23.993][mmc]: write_tuning_try_freq: write ok [23.998][mmc]: Pattern compare ok
[24.001][mmc]: Write tuning pattern ok
[24.005][mmc]: ================== HSSDR52_SDR25... [24.010][mmc]: skip freq 400000 [24.012][mmc]: skip freq 25000000
[24.015][mmc]: freq: 2-50000000-64-4
[24.202][mmc]: [0-40|41] [53-63|11]
[24.205][mmc]: ================== HSDDR52_DDR50... [24.210][mmc]: skip freq 400000 [24.213][mmc]: freq: 1-25000000-64-4
[24.402][mmc]: freq: 2-50000000-64-4
[24.551][mmc]: [0-34|35] [42-42|1] [46-55|10] [58-63|6]
[24.556][mmc]: [0-28|29] [30-34|5] [43-63|21]
[24.561][mmc]: DS26/SDR12: 0xffffffff 0xffffffff [24.565][mmc]: HSSDR52/SDR25: 0xff14ffff 0xffffffff [24.570][mmc]: HSDDR52/DDR50: 0xff0e11ff 0xffffffff [24.574][mmc]: HS200/SDR104: 0xffffffff 0xffffffff [24.579][mmc]: HS400: 0xffffffff 0xffffffff [24.583][mmc]: HS400: 0xffffffff 0xffffffff [24.587][mmc]: Best spd md: 2-HSDDR52/DDR50, freq: 2-50000000, Bus width: 8

[24.595]Loading Environment from SUNXI_FLASH... OK [24.599]Net: [24.601]Net Initialization Skipped [24.604]No ethernet found. Hit any key to stop autoboot: 0
sunxi work mode=0x10
run usb efex delay time 2500 weak:otg_phy_config usb init ok

set address 0x20
set address 0x20 ok
set address 0x22
set address 0x22 ok SUNXI_EFEX_ERASE_TAG erase_flag = 0x0
FEX_CMD_fes_verify_status FEX_CMD_fes_verify last err=0 the 0 mbr table is ok
the 1 mbr table is ok
the 2 mbr table is ok

the 3 mbr table is ok *************MBR DUMP***************
total mbr part 8 part[0] name | :bootloader part[0] classname :DISK part[0] addrlo | :0x8000 part[0] lenlo | :0x10000 part[0] user_type :32768 part[0] keydata :0 part[0] ro | :0 part[1] name | :env part[1] classname :DISK part[1] addrlo | :0x18000 part[1] lenlo | :0x8000 part[1] user_type :32768 part[1] keydata :0 part[1] ro | :0 part[2] name | :boot part[2] classname :DISK part[2] addrlo | :0x20000 part[2] lenlo | :0x10000 part[2] user_type :32768 part[2] keydata :0 part[2] ro | :0 part[3] name | :rootfs part[3] classname :DISK part[3] addrlo | :0x30000 part[3] lenlo | :0x893e0 part[3] user_type :32768 part[3] keydata :0 part[3] ro | :0 part[4] name | :rootfs_data part[4] classname :DISK part[4] addrlo | :0xb93e0 part[4] lenlo | :0x8000 part[4] user_type :32768 part[4] keydata :0 part[4] ro | :0 part[5] name | :misc part[5] classname :DISK part[5] addrlo | :0xc13e0 part[5] lenlo | :0x8000 part[5] user_type :32768 part[5] keydata :0 part[5] ro | :0 part[6] name | :private part[6] classname :DISK part[6] addrlo | :0xc93e0 part[6] lenlo | :0x8000 part[6] user_type :32768 part[6] keydata :0 part[6] ro | :0 part[7] name | :UDISK part[7] classname :DISK part[7] addrlo | :0xd13e0 part[7] lenlo | :0x0 part[7] user_type :33024 part[7] keydata :0 part[7] ro | :0

total part: 9 mbr 0, 8000, 8000 bootloader 1, 10000, 8000

env 2, 8000, 8000 boot 3, 10000, 8000
rootfs 4, 893e0, 8000
rootfs_data 5, 8000, 8000 misc 6, 8000, 8000 private 7, 8000, 8000 UDISK 8, 0, 8100

[58.127]erase all part start need erase flash: 0
******Has init private part exist GPT:bootloader : 12000 | 21fff GPT:env | : 22000 | 29fff GPT:boot | : 2a000 | 39fff GPT:rootfs | : 3a000 | c33df GPT:rootfs_data : c33e0 | cb3df GPT:misc | : cb3e0 | d33df GPT:private | : d33e0 | db3df GPT:UDISK | : db3e0 | 1d59fde begin to store data part 0 name bootloader keydata = 0x0 part 1 name env keydata = 0x0 part 2 name boot keydata = 0x0 part 3 name rootfs keydata = 0x0 part 4 name rootfs_data

keydata = 0x0 part 5 name misc keydata = 0x0 part 6 name private

keydata = 0x0
find keypart private
keypart read start: 0xc93e0, sectors 0x8000 keypart part private read 0xc93e0, sectors 0x8000 part 7 name UDISK keydata = 0x0 begin to erase
[58.410]erase all part start
finish erase ******Has init rewrite ******Has init write primary GPT success write Backup GPT success keypart write start: 0xc93e0, sectors 0x8000

flash exit SUNXI_EFEX_MBR_TAG mbr size = 0x10000

******Has init write primary GPT success write Backup GPT success FEX_CMD_fes_verify_status FEX_CMD_fes_verify last err=0

******Has init FEX_CMD_fes_verify_value, start 0x8000, size high 0x0:low 0x14000 FEX_CMD_fes_verify_value 0xe6f75b5c FEX_CMD_fes_verify_value, start 0x18000, size high 0x0:low 0x20000 FEX_CMD_fes_verify_value 0x166c4051 原因：尚未解决，可能是因为 EMMC 型号不对

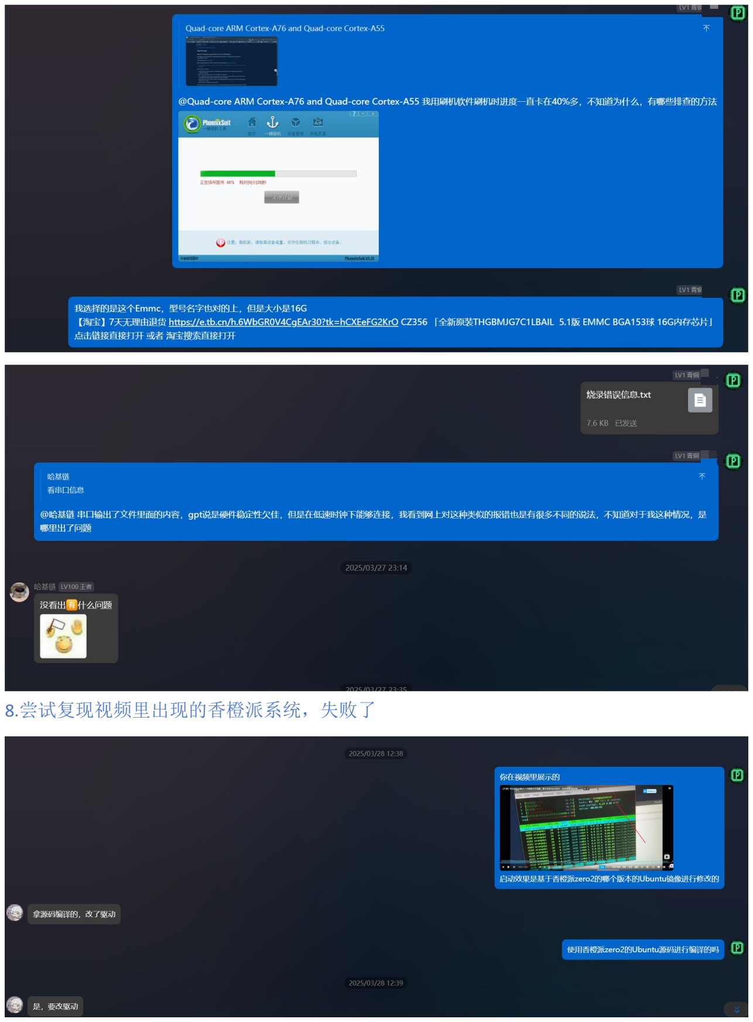
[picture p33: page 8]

## 8.尝试复现视频里出现的香橙派系统，失败了

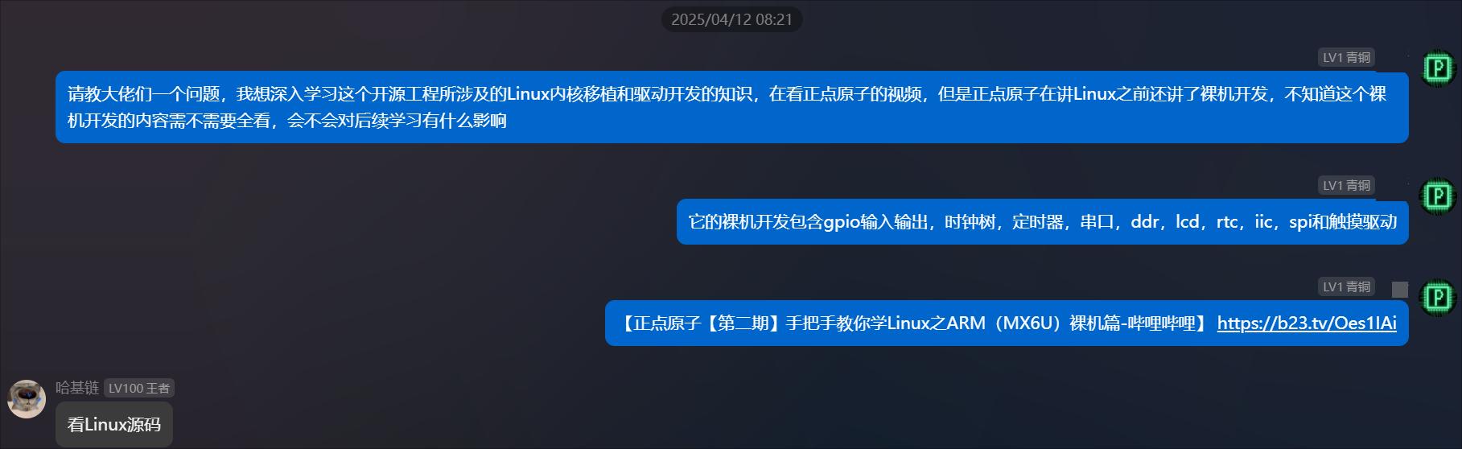
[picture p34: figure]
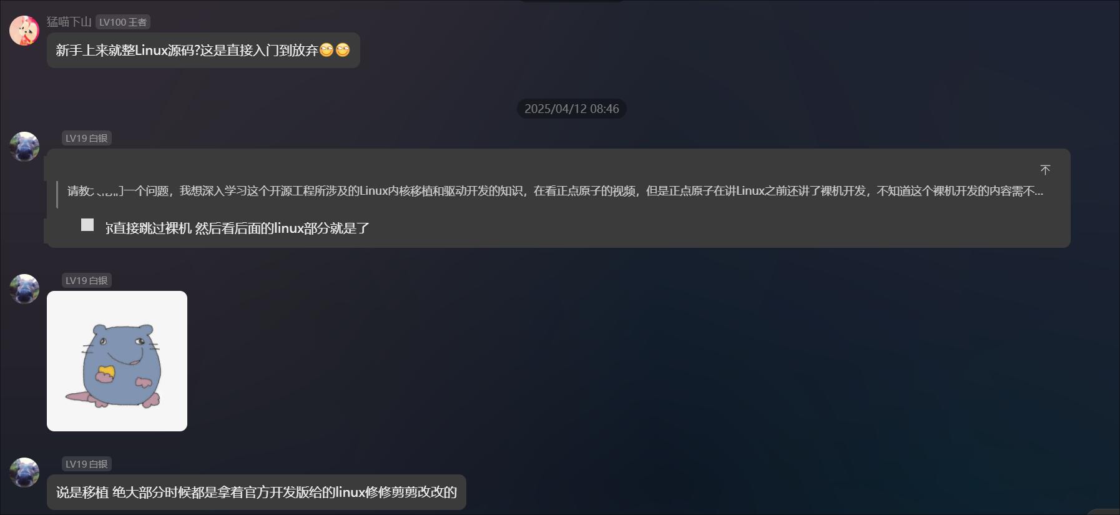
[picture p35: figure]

## 原因：还不会 Linux 内核和系统移植，和进阶驱动开发

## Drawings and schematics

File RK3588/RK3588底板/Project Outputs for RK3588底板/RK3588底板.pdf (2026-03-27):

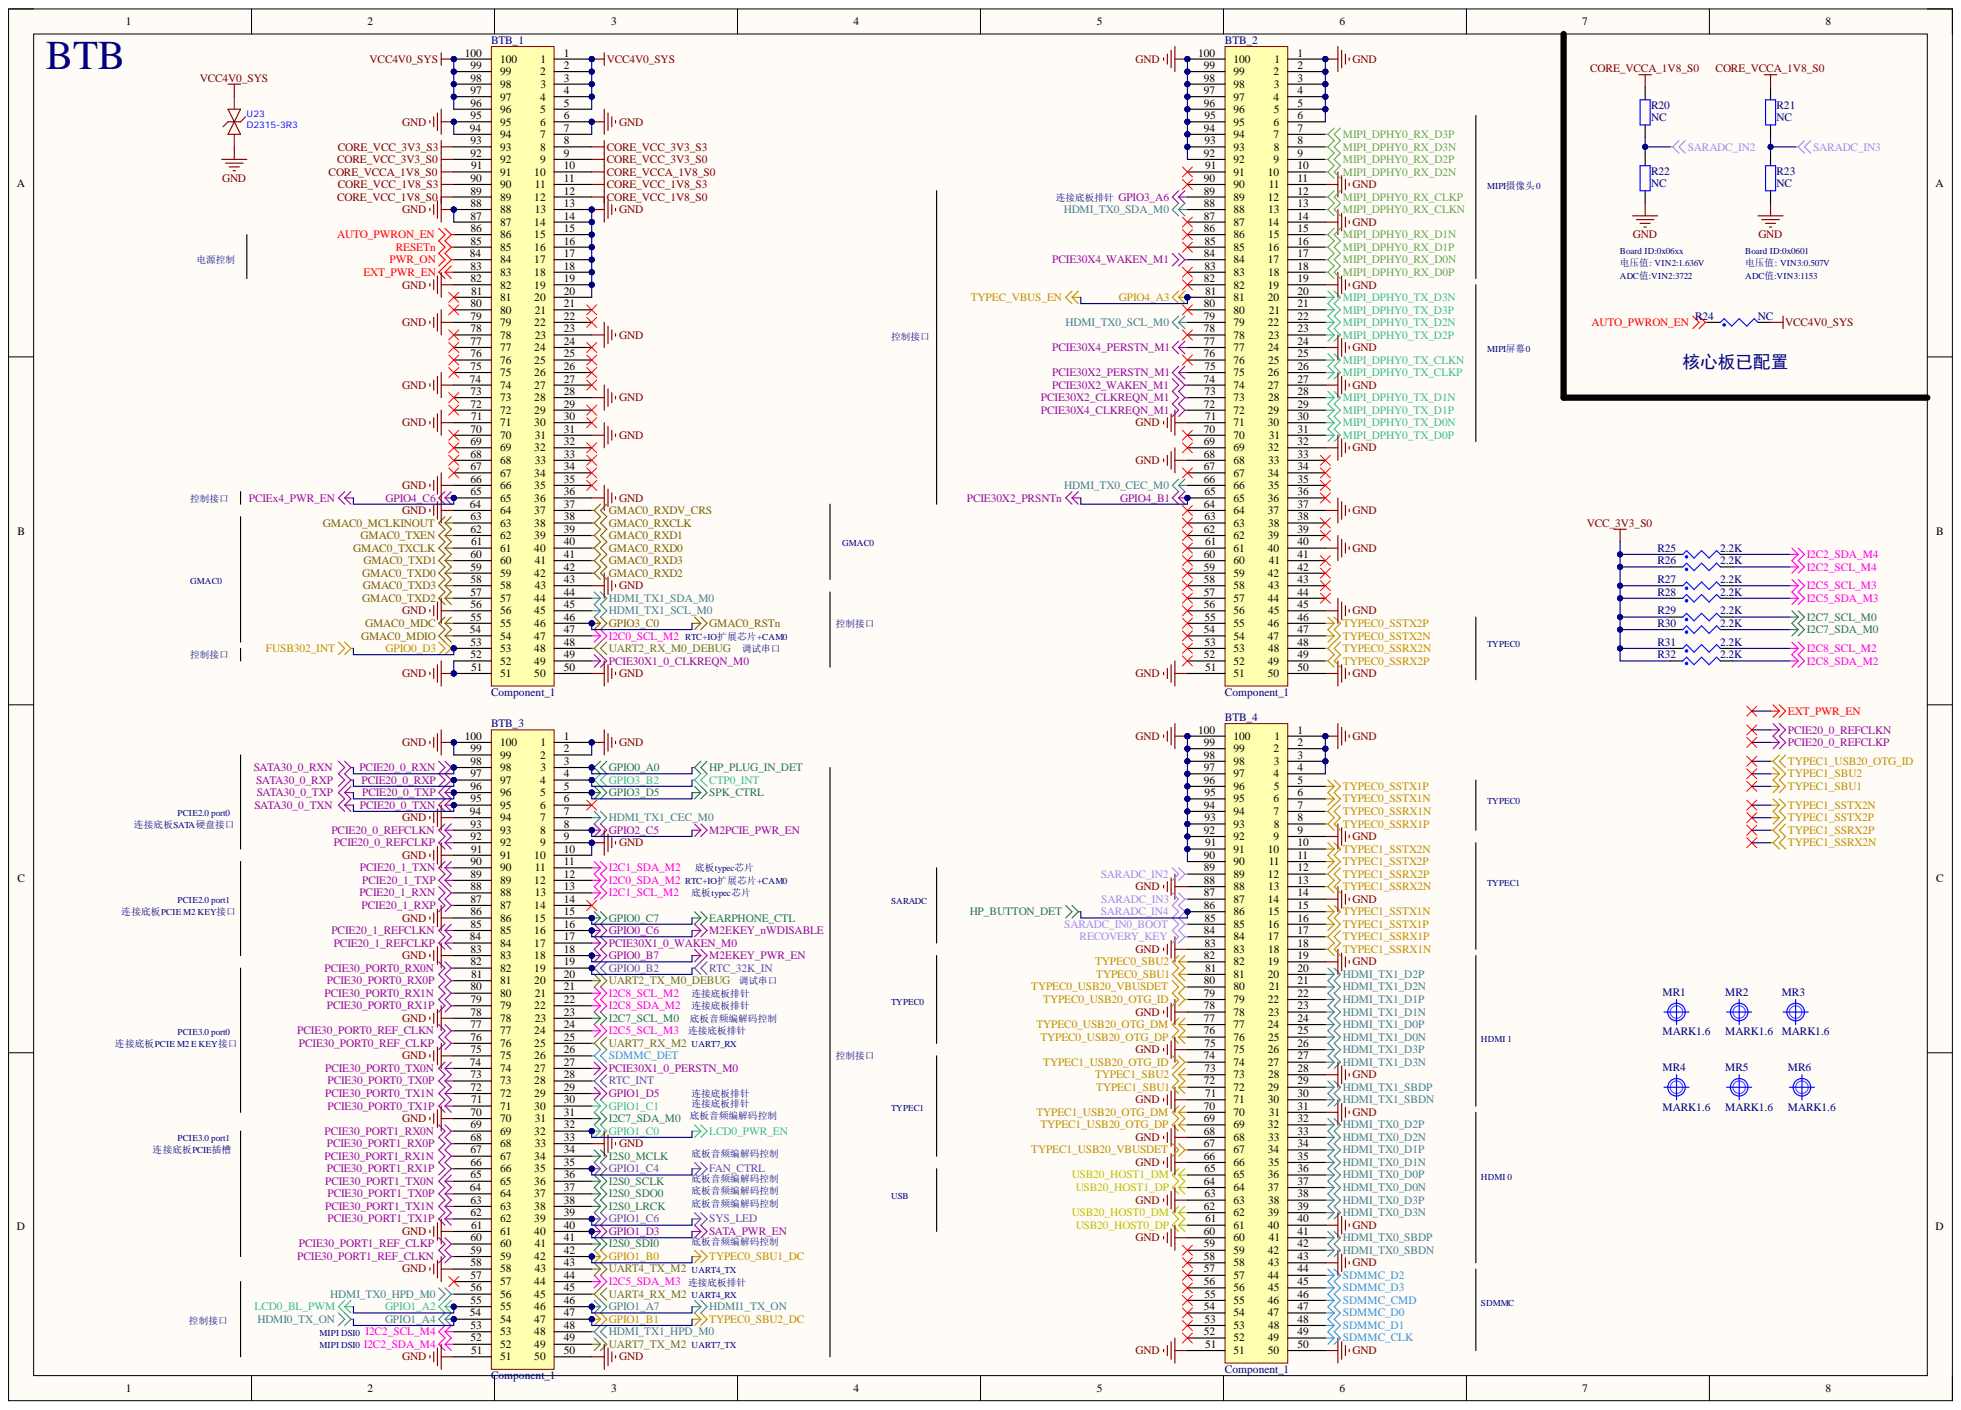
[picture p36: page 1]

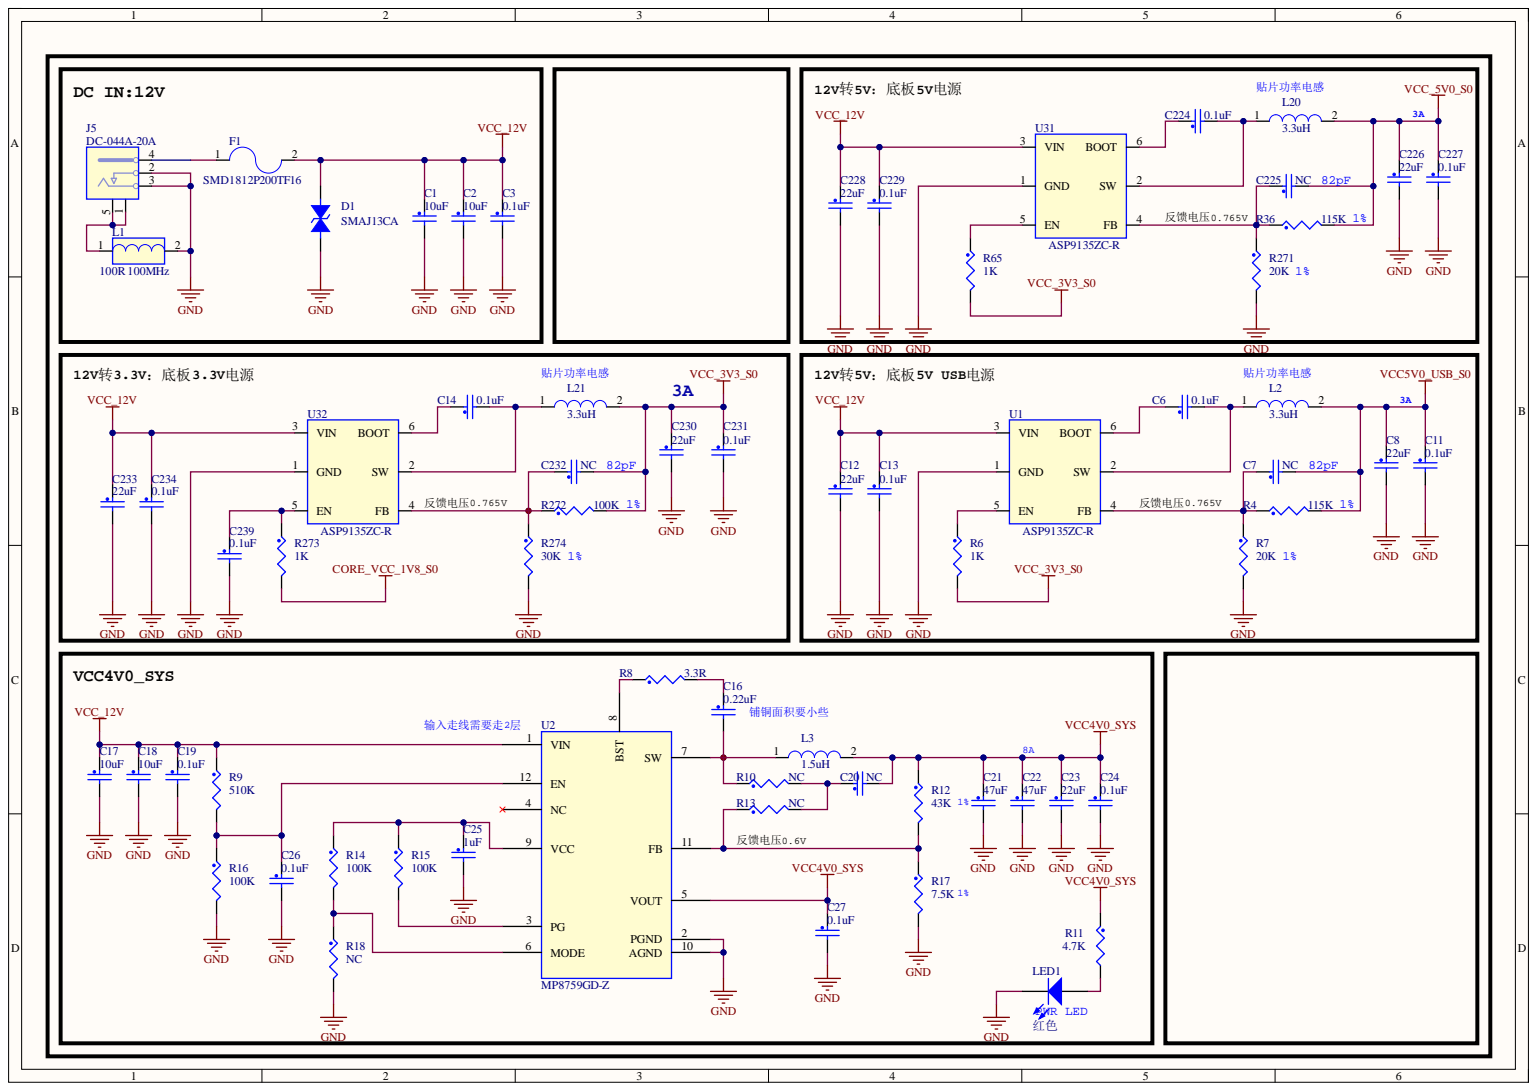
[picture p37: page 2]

2 | | C1 | C2 10uF

反馈电压0.765V R36 | 115K | 1%

C25
1uF

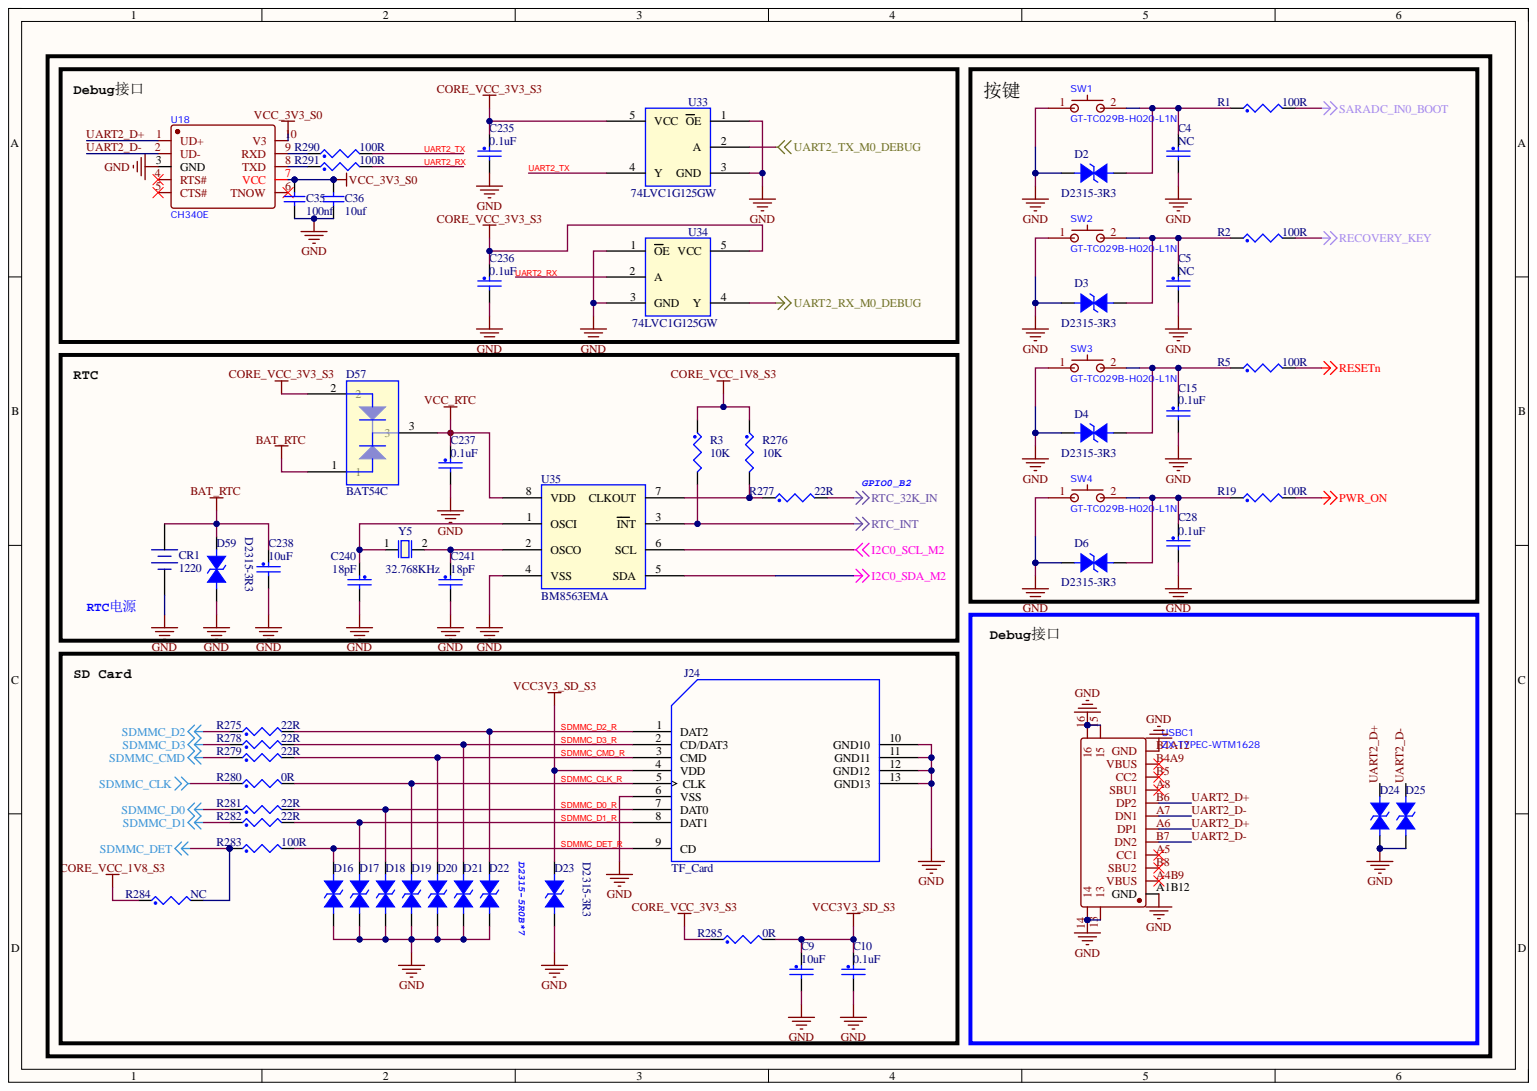
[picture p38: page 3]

UART2_RX | A 2

GND 3

SDMMC_D3_R | | CD/DAT3 2
SDMMC_CMD_R | | CMD 3

VDD 4

SDMMC_CLK_R | CLK 5

VSS 6
DAT0 7

SDMMC_D1_R | | DAT1 8

SDMMC_DET_R | | CD 9

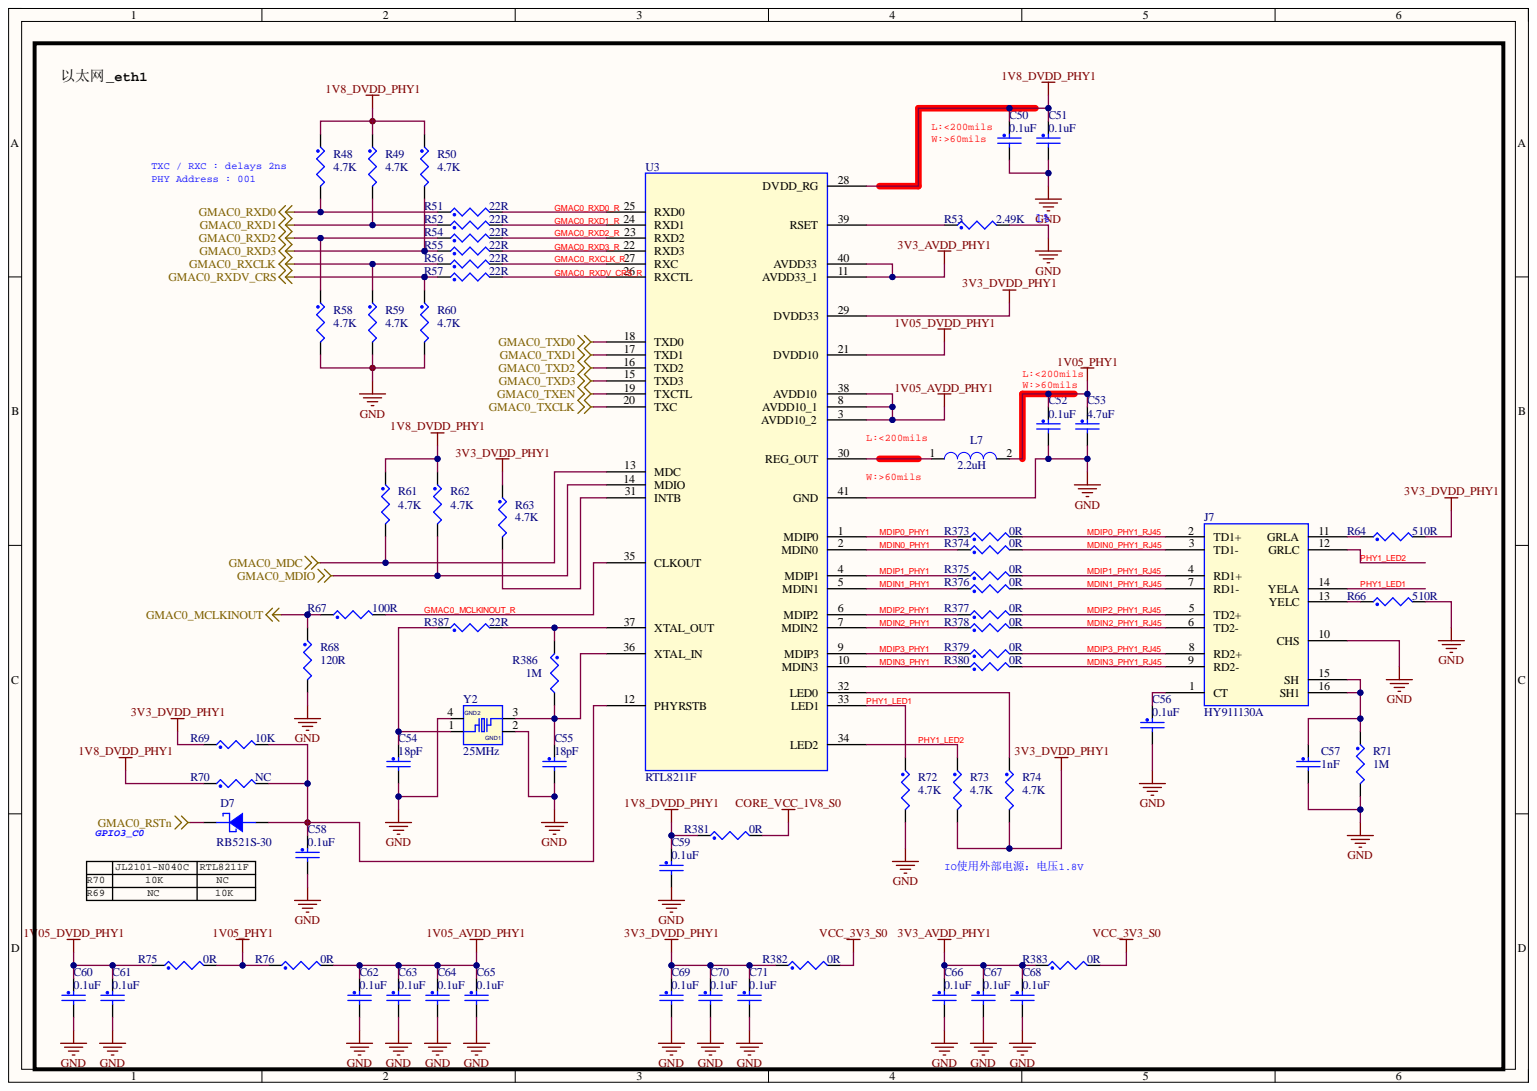
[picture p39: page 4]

MDIO 14

R61 R62 4.7K 4.7K | INTB 31

R63 4.7K | CLKOUT 35

XTAL_OUT 37

XTAL_IN 36 | MDIP3_PHY1_RJ45 | RD2+ 8

R386 1M | | PHYRSTB 12 | MDIN3_PHY1_RJ45 | RD2- 9

JL2101-N040C | RTL8211F

R70 | 10K | NC
R69 | NC | 10K

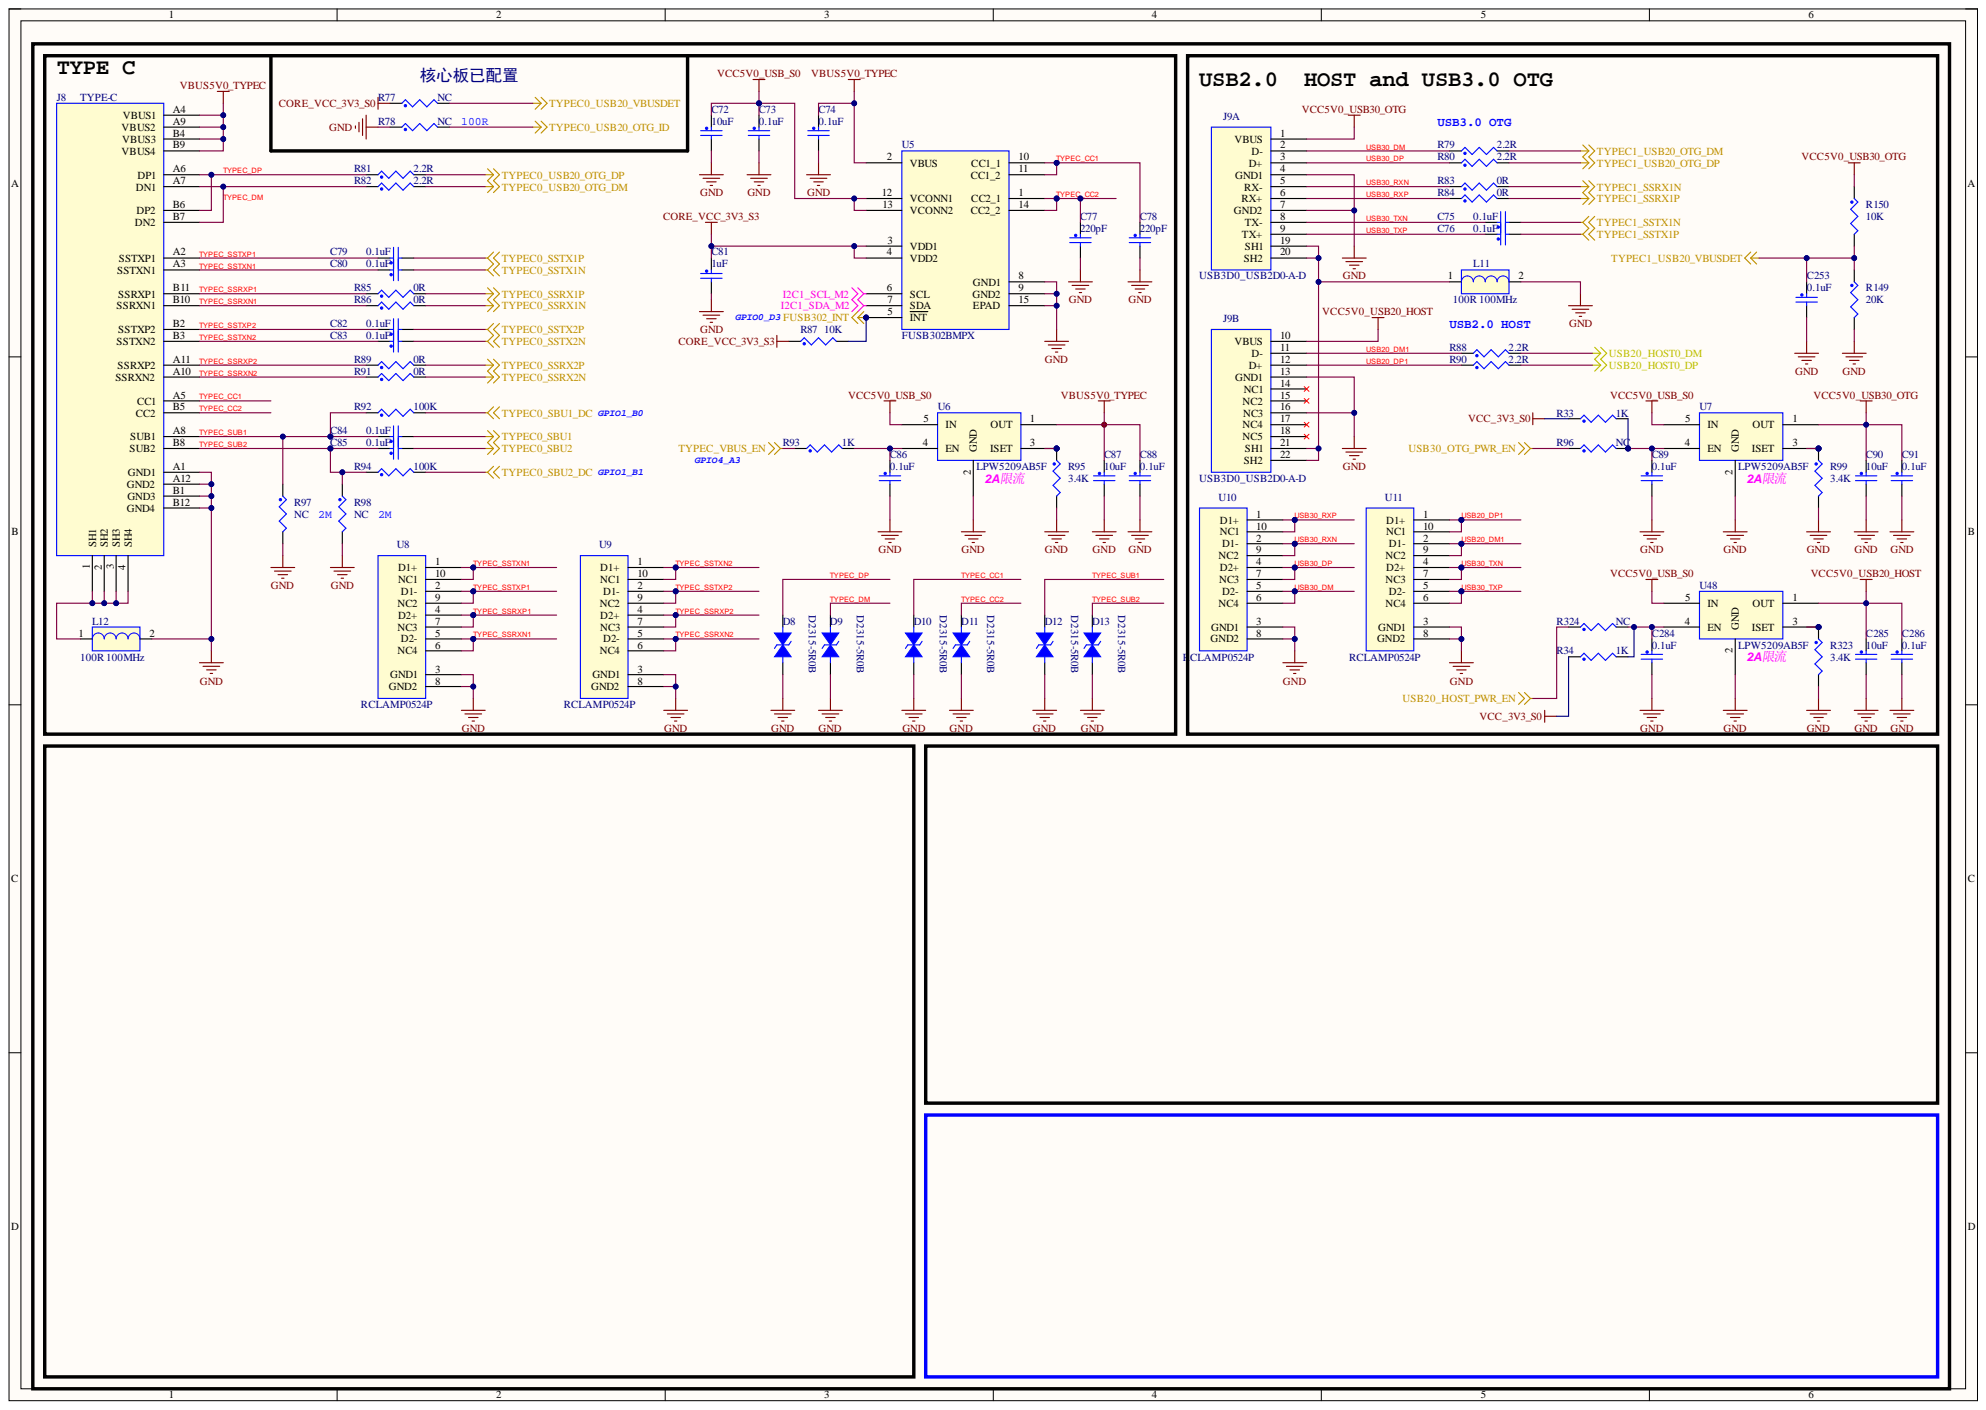
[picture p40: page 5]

C | G | ND VBU C

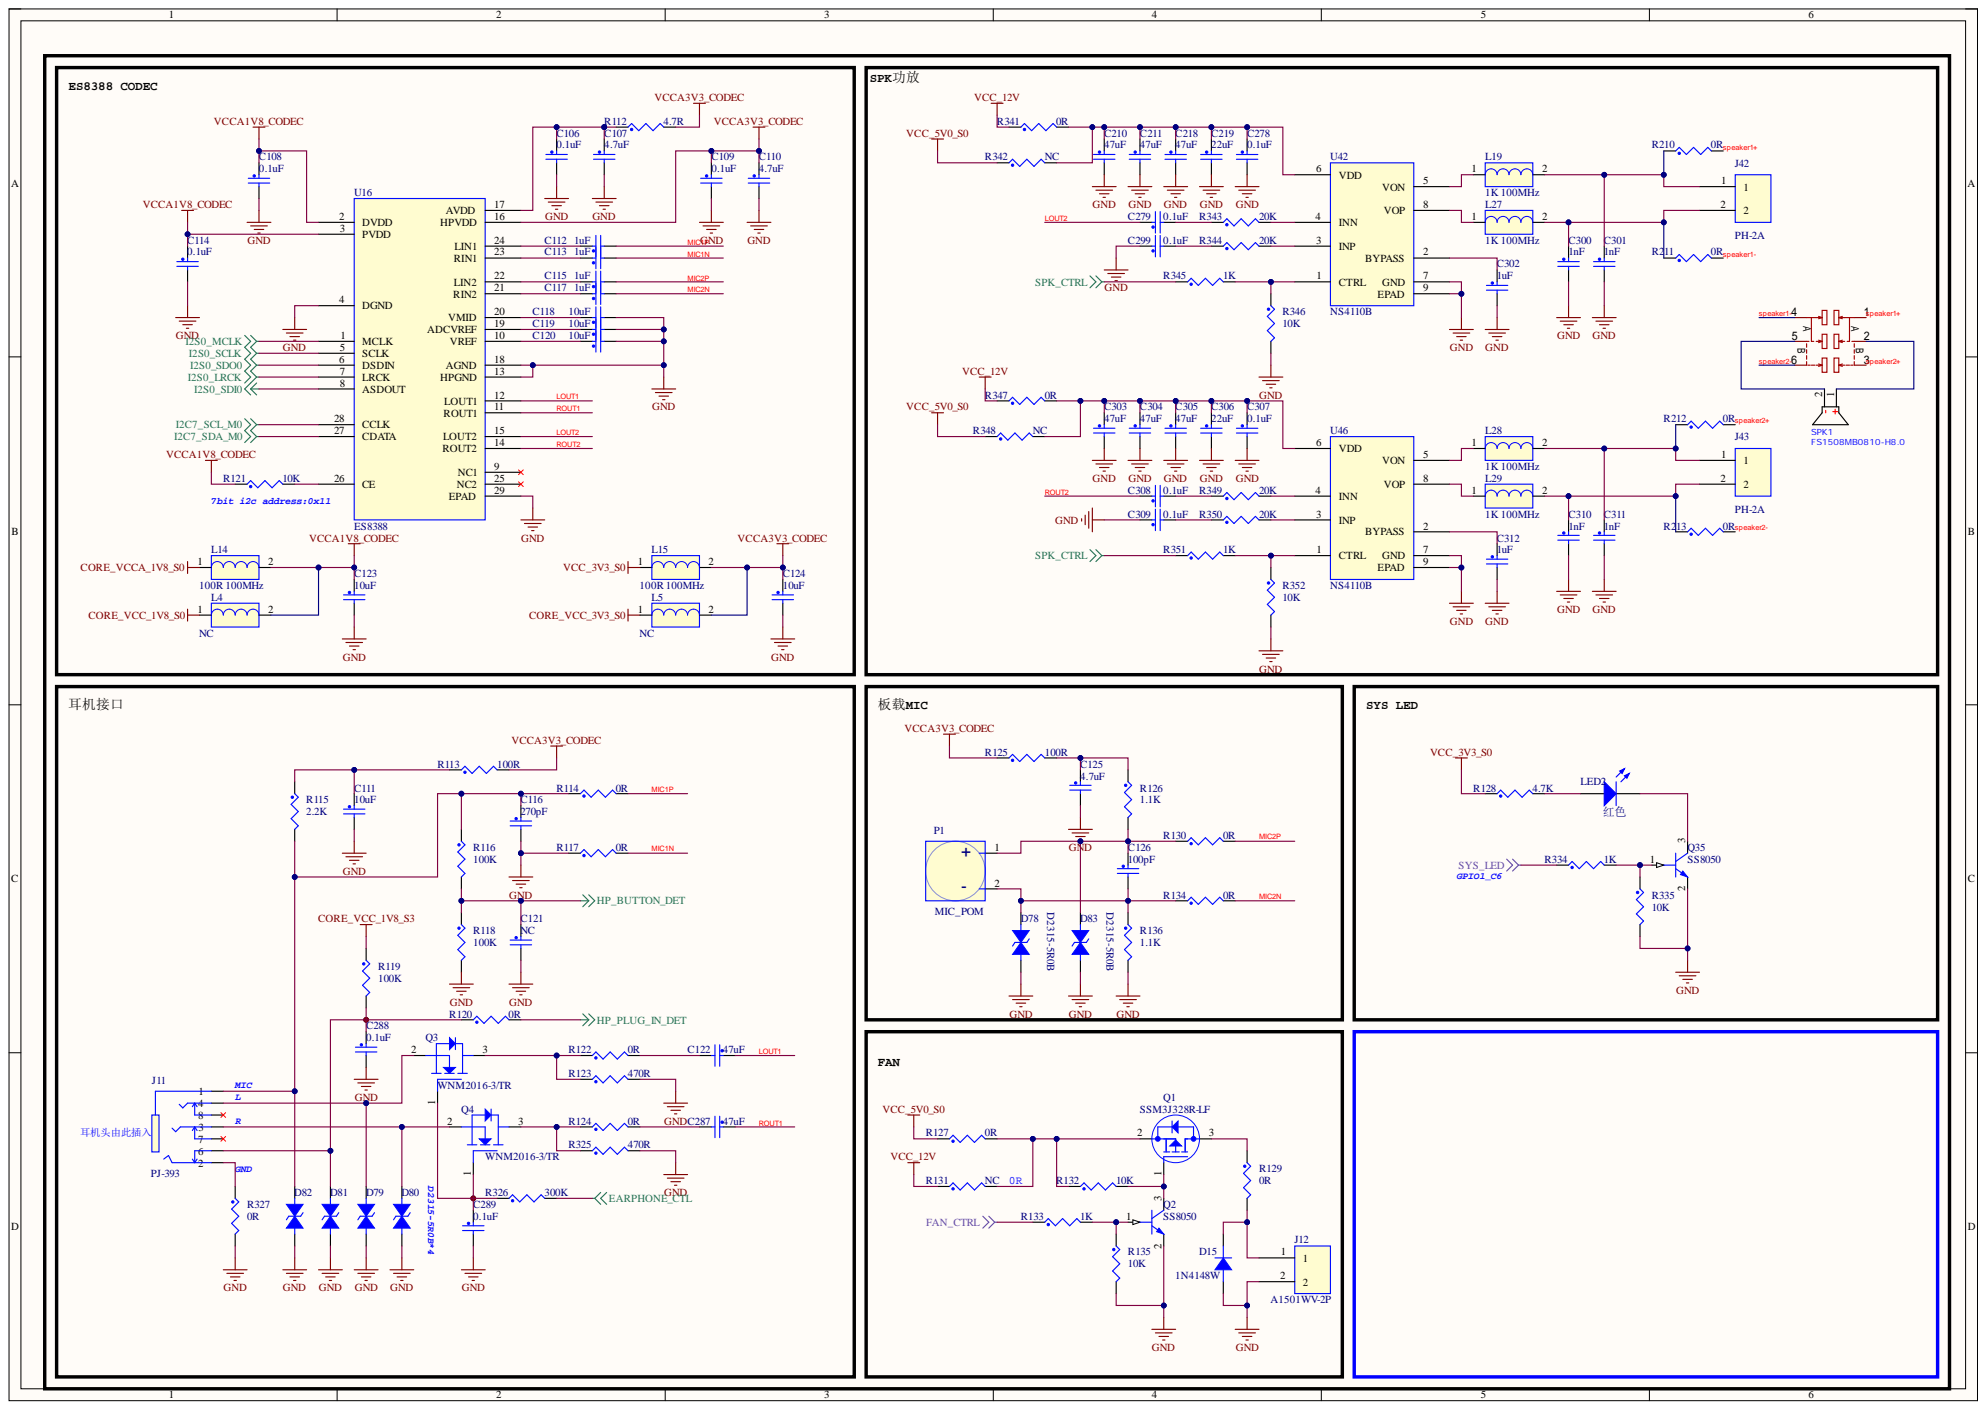
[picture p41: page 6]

INN 4 | 1 1

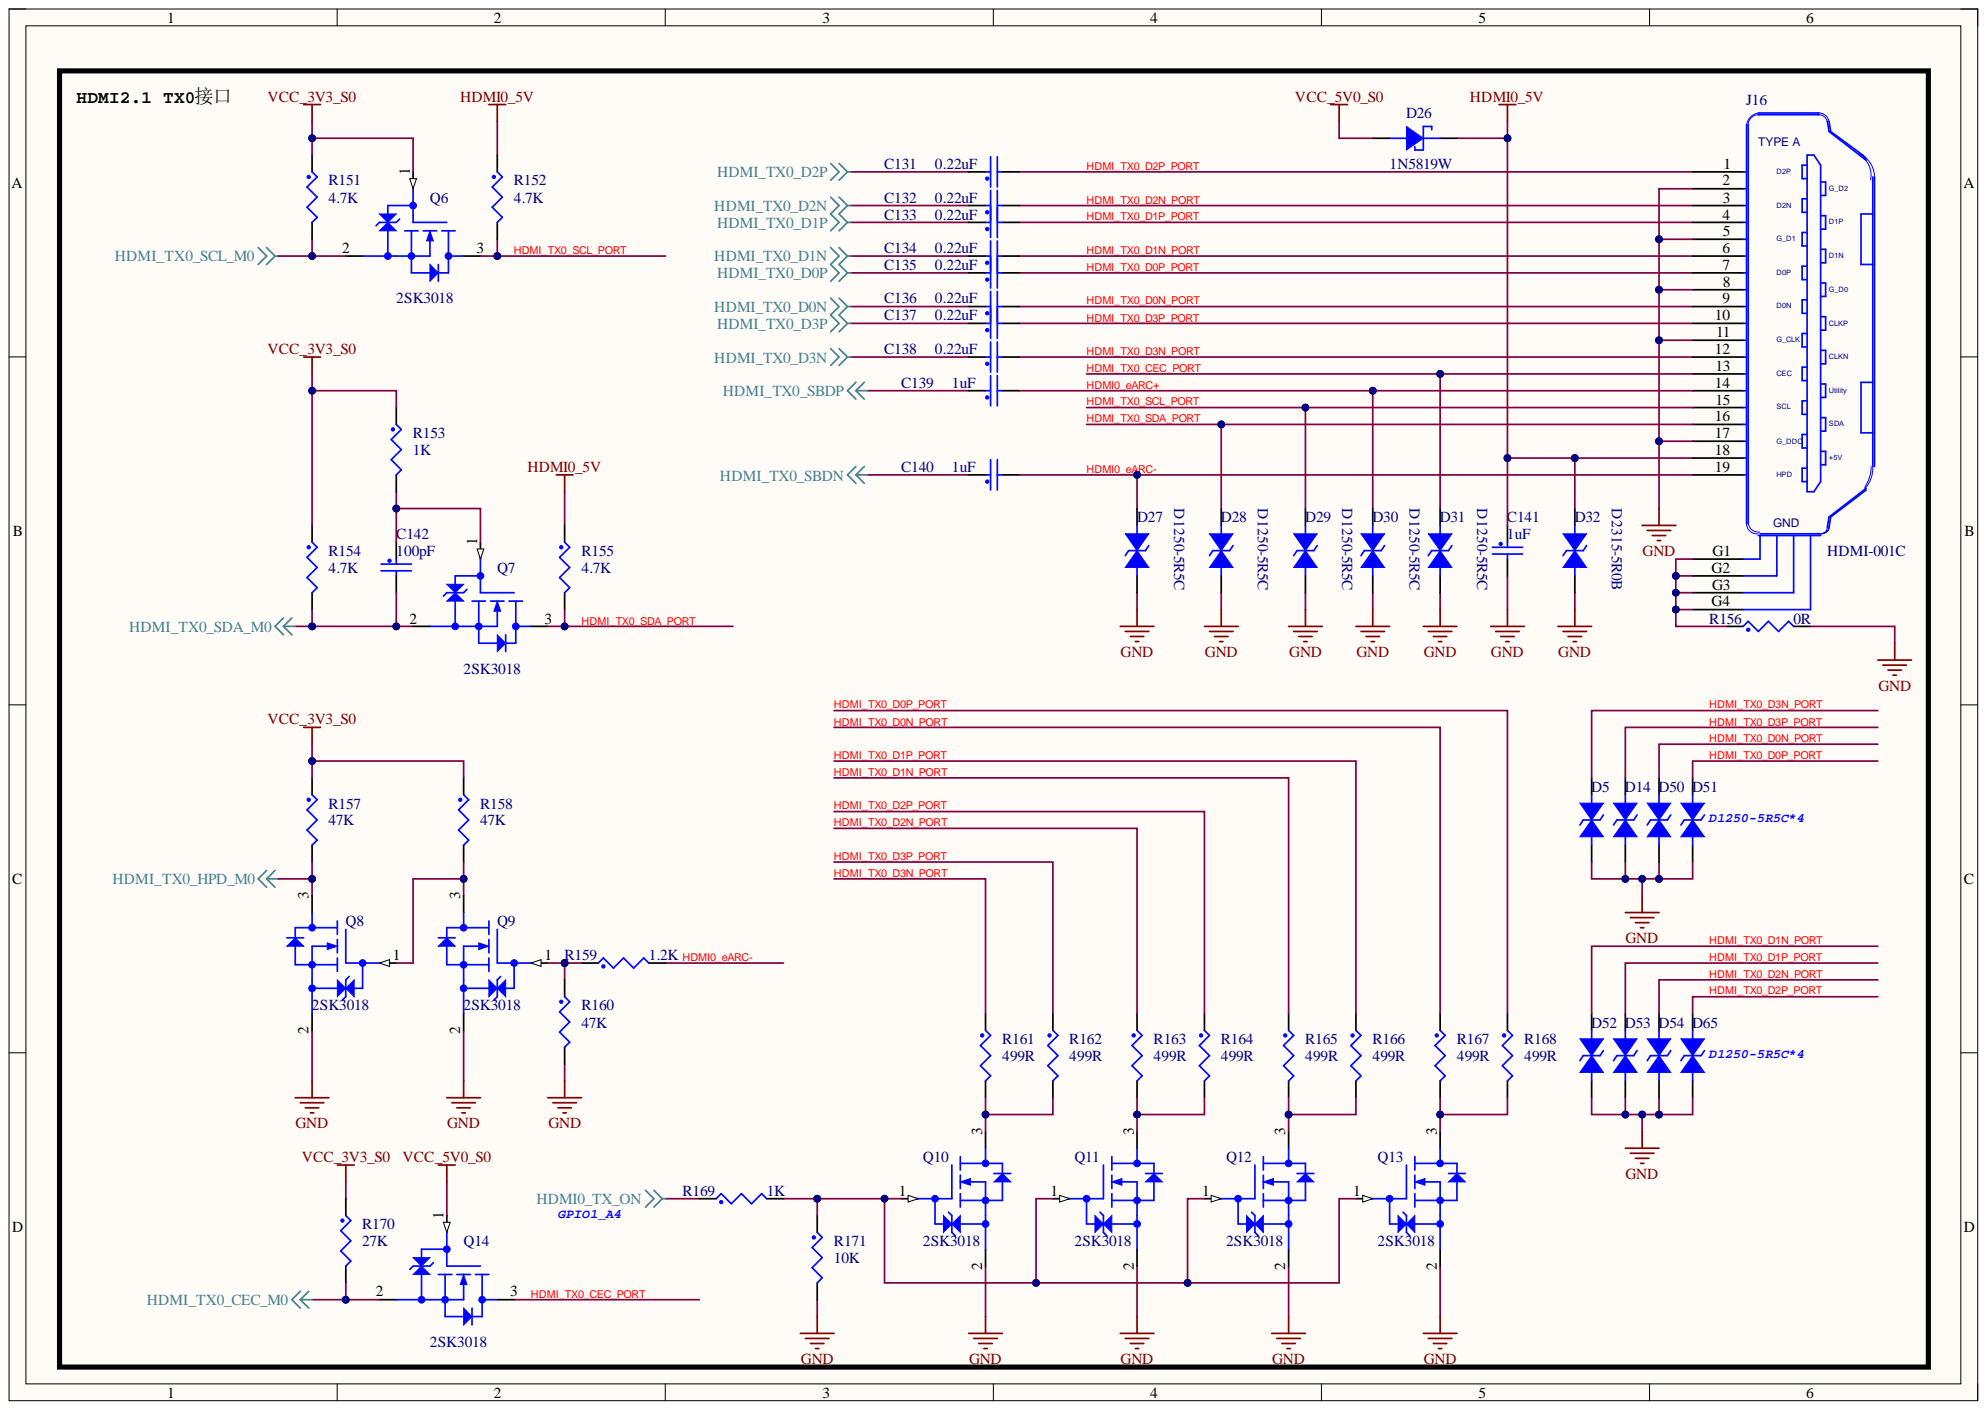
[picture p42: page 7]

HDMI_TX0_D2N_PORT | 2

HDMI_TX0_D1P_PORT | | 4
HDMI_TX0_D1N_PORT | | 5

HDMI_TX0_D0P_PORT | | 7
HDMI_TX0_D0N_PORT | | 8

HDMI_TX0_D3P_PORT | | 10
HDMI_TX0_D3N_PORT | | 11

HDMI_TX0_CEC_PORT | | 13

17
18
19

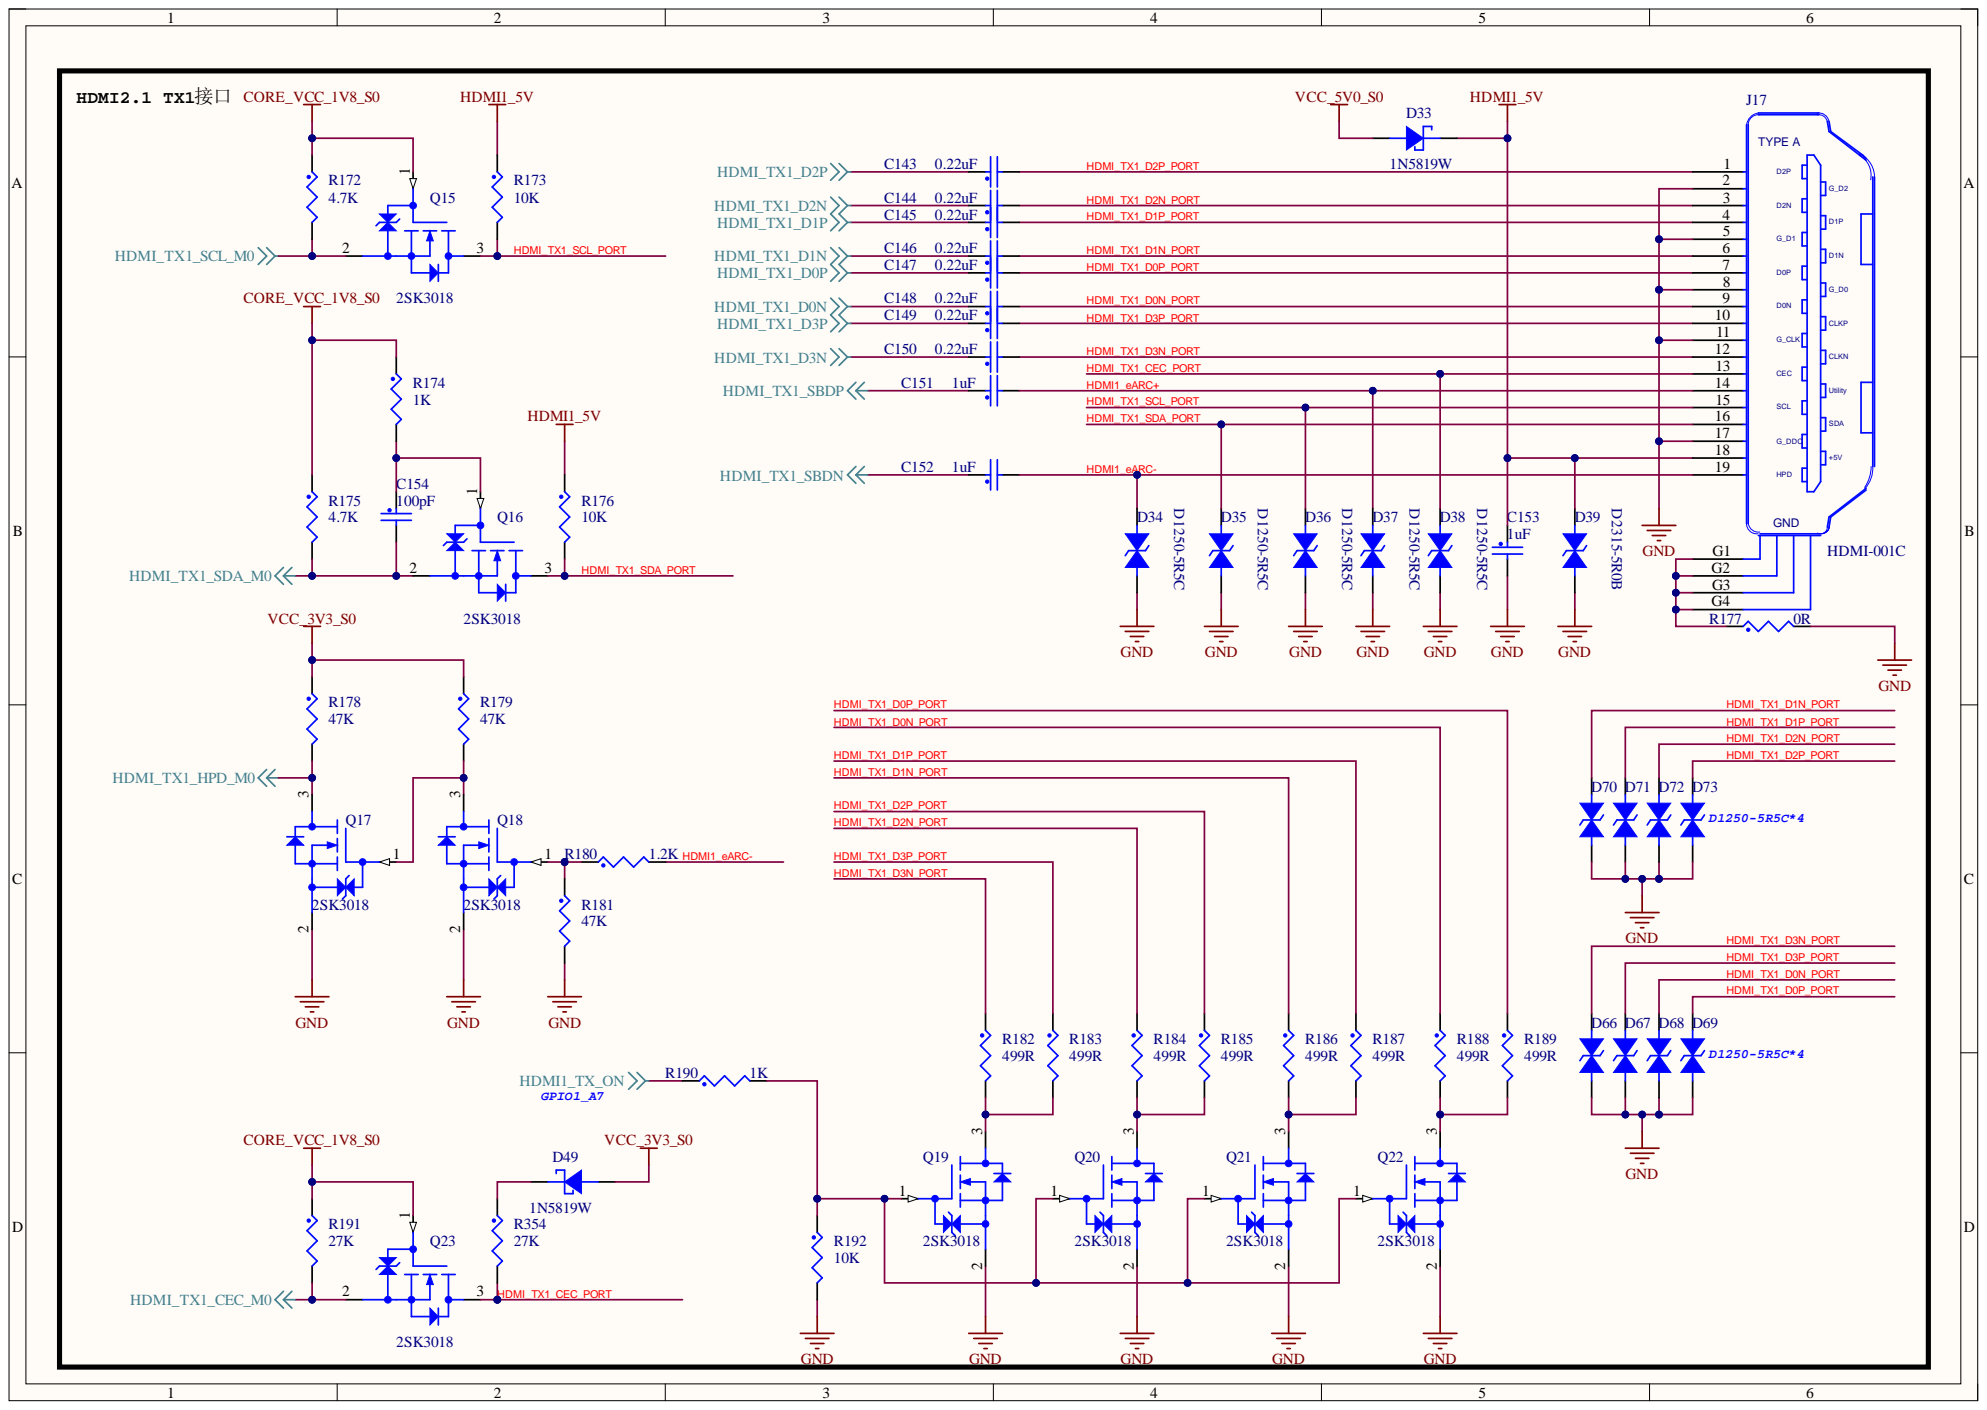
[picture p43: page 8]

HDMI_TX1_D2N_PORT | 2

HDMI_TX1_D1P_PORT | | 4
HDMI_TX1_D1N_PORT | | 5

HDMI_TX1_D0P_PORT | | 7
HDMI_TX1_D0N_PORT | | 8

HDMI_TX1_D3P_PORT | | 10
HDMI_TX1_D3N_PORT | | 11

HDMI_TX1_CEC_PORT | | 13

17
18

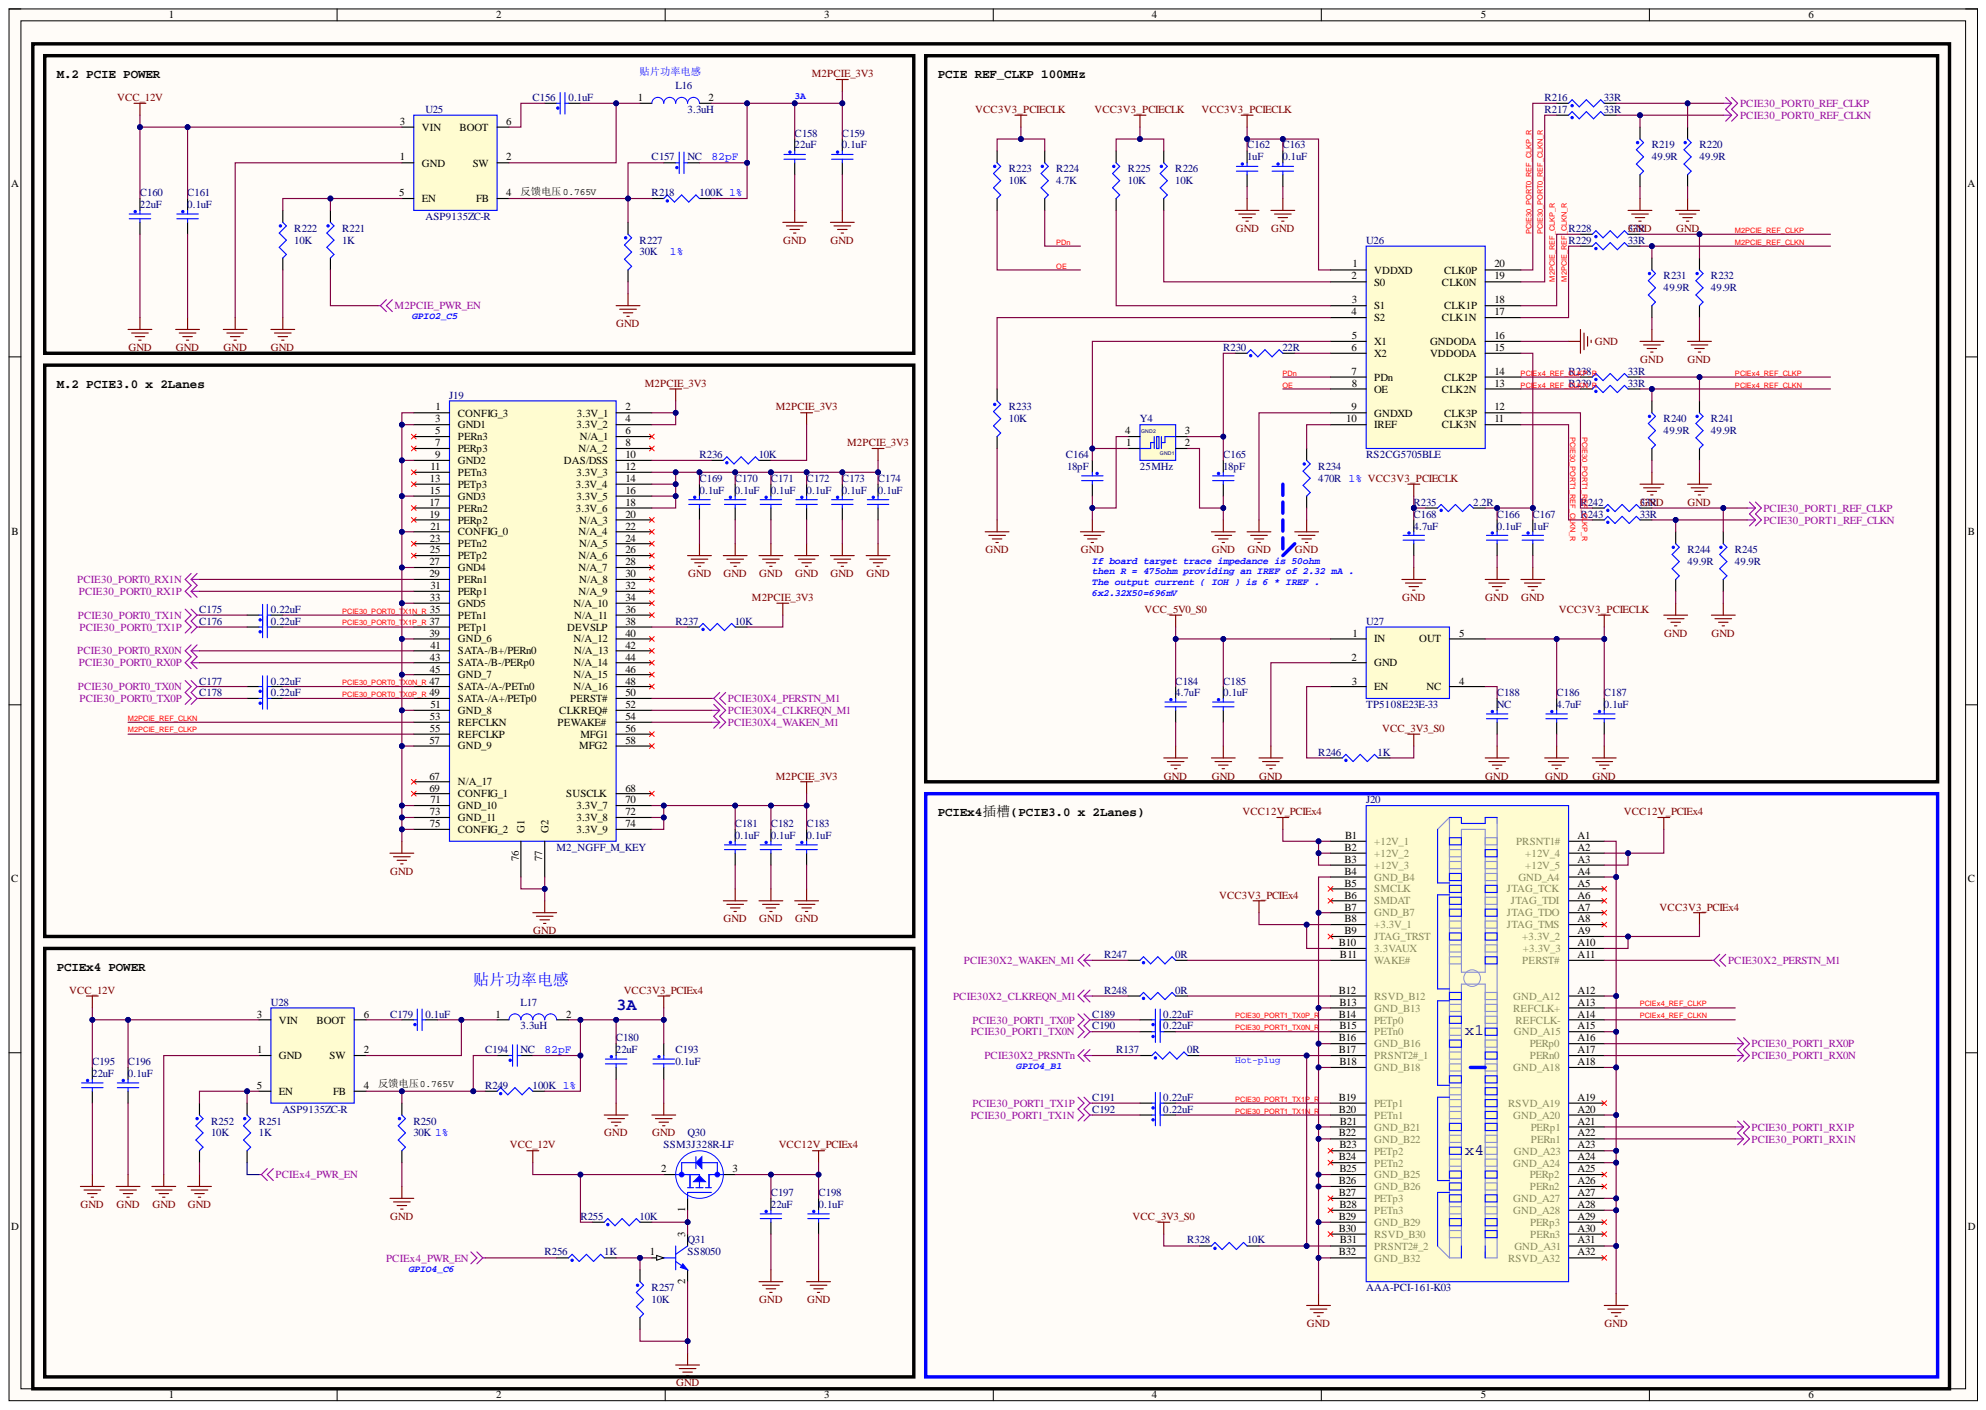
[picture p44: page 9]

0.1uF M2PCIE_3V3 | | 0.1uF

If board target trace impedance is 50ohm
then R = 475ohm providing an IREF of 2.32 mA .
The output current ( IOH ) is 6 * IREF .

GND_B4 B4

PRSNT2#_1 B17

PETp1 B19

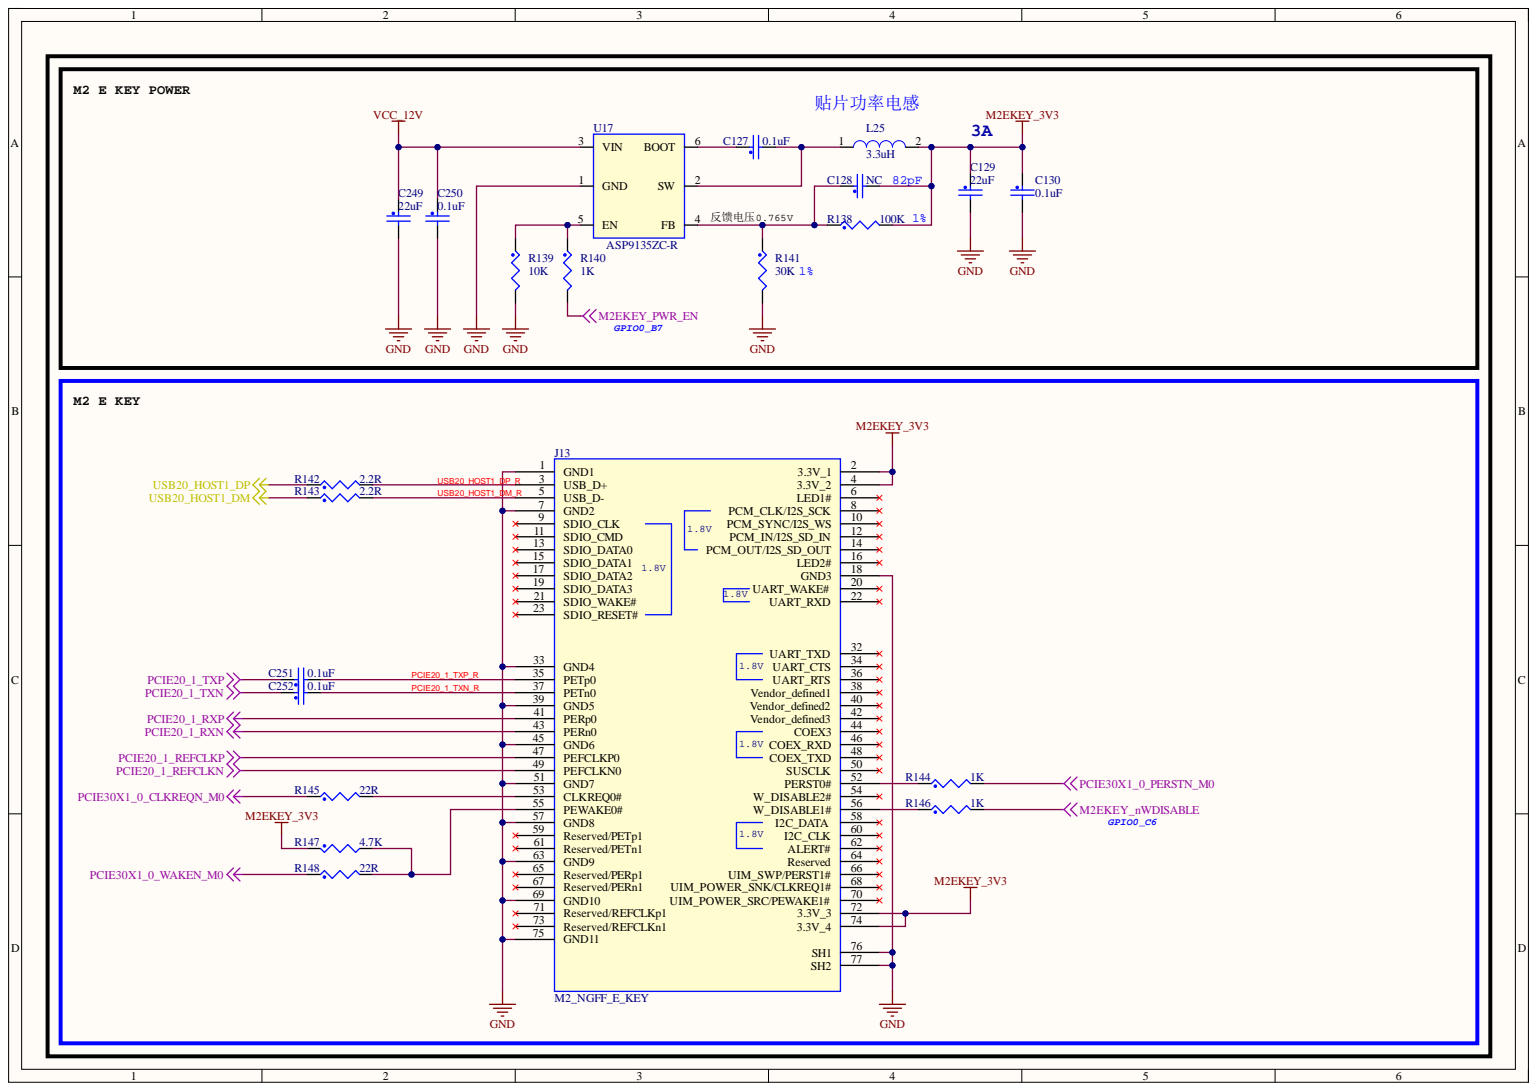
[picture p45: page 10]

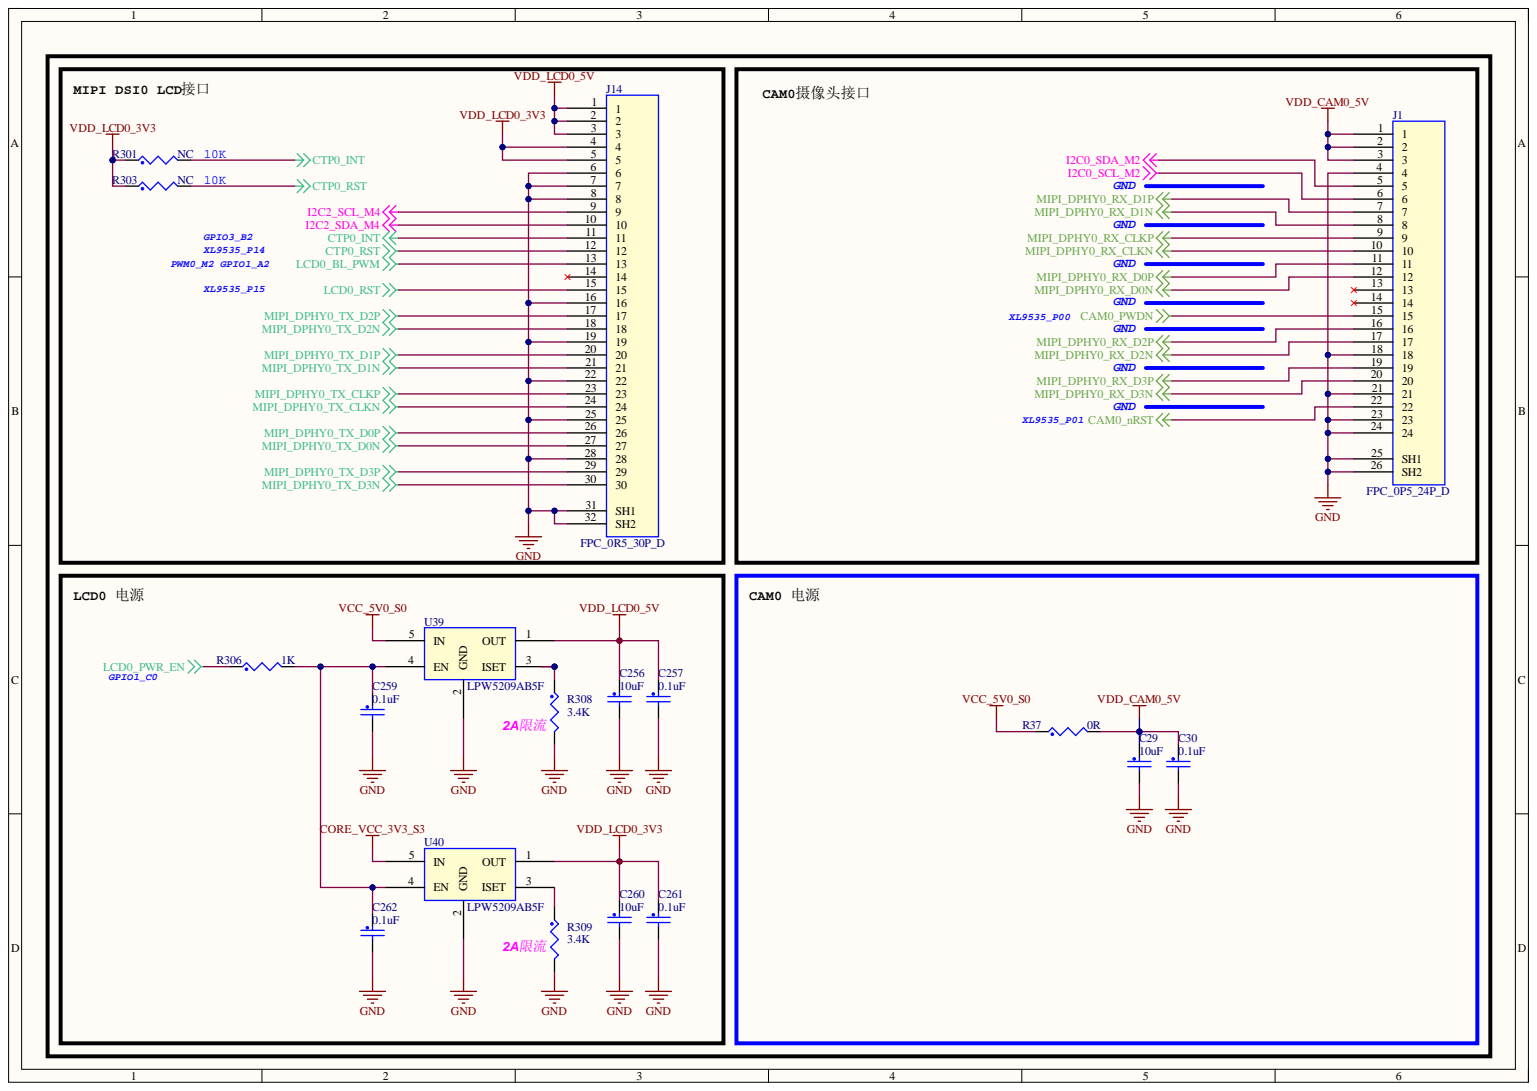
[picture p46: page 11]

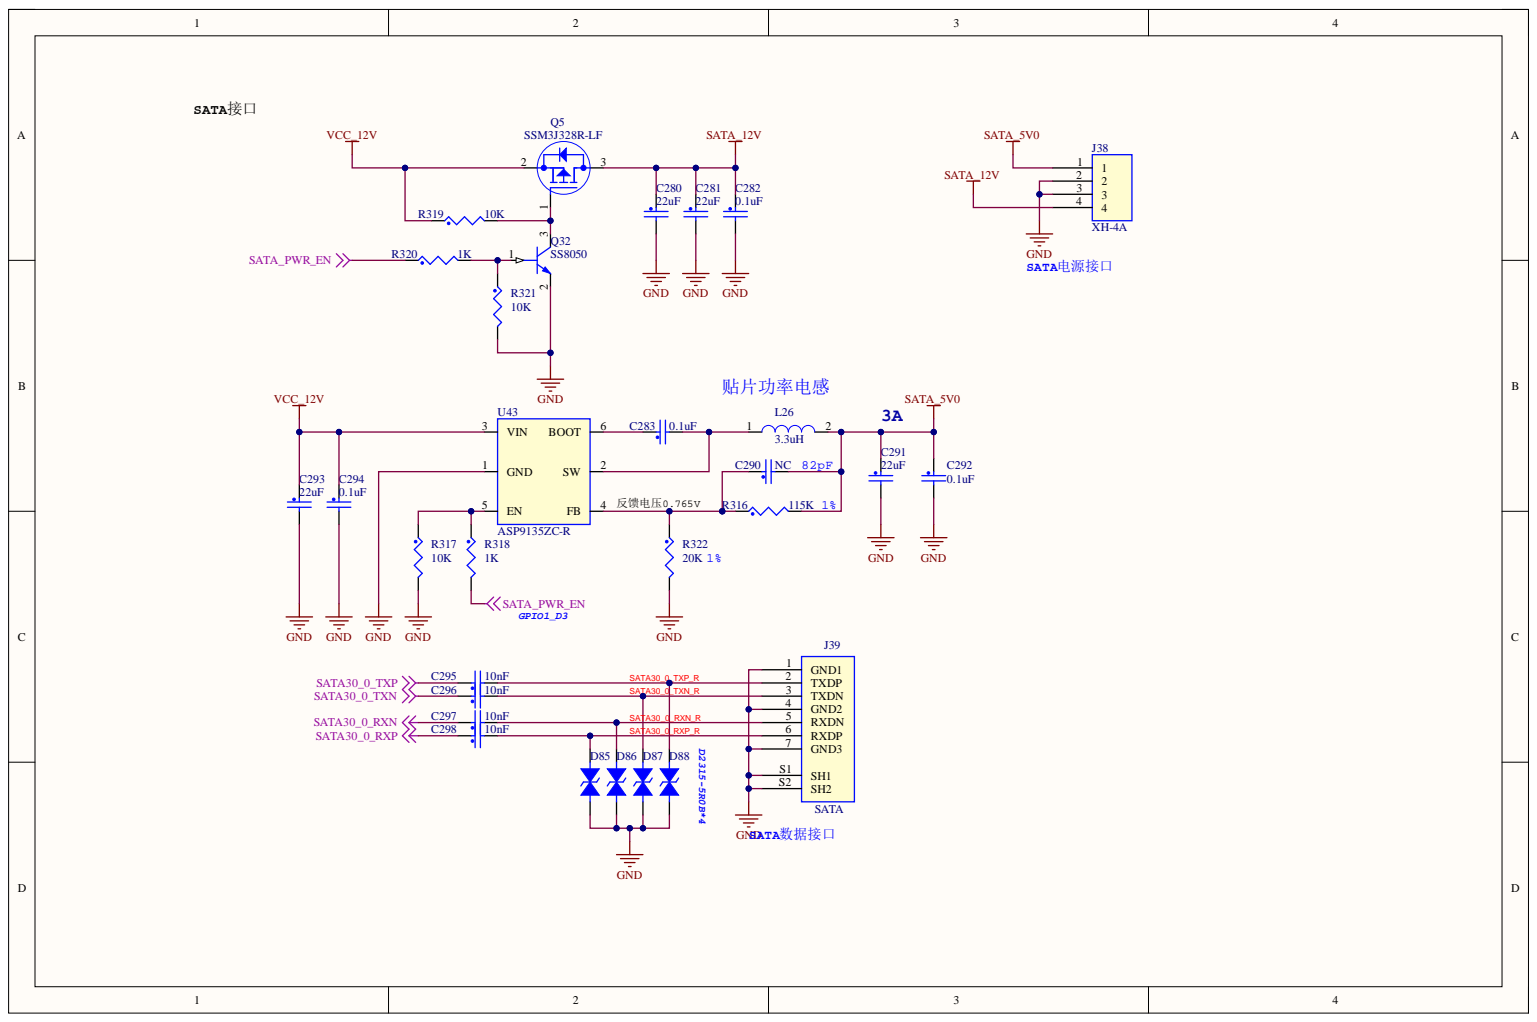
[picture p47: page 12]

TXDP 2

SATA30_0_TXN_R | TXDN 3
SATA30_0_RXN_R | | GND2 4

RXDN 5

SATA30_0_RXP_R | | RXDP 6

GND3 7


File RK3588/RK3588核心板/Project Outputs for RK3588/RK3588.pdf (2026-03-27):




AC1 4 | 6
AB1 4 | T 1 6
A A 1 4 | T 1 7
A D 1 5 | 7

AC1 5 | 7
AB1 5 | N 1 7
A A 1 5 | 7

AC1 8 | N 2 4
AC1 7 | 4
V 1 6 | 3
V 1 7 | N 2 3

K 1 9 | 3
K 2 0 | L 2 3

AB2 3 | U 2 1
A D 2 2 | T 2 2





1.Hold power of CLK during retention times.
在保持阶段期间，为CLK（时钟）保持供电
VDDQ_DDR_CK_S0
4.VDDQ_CK: power for CK, LPDDR4/4X=0.6V/LPDDR5=0.5V
VDDQ_CK：为CK（时钟）供电，LPDDR4/4X电压为0.6V

VDDQ_DDR_S0
5.VDDQ: Power for DDR IO (except for ck, cke and reset); LPDDR4/4X=0.6V/LPDDR5=0.5V
VDDQ：为DDR的输入/输出接口供电（除CK、CKE和RESET外）；LPDDR4/4X电压为0.6V



) HS/FS/LS USB2.0 of TYPEC0 (OTG/HOST/DEVICE) USB2.0 HOST0

T pin internal has a pul

) to ground,The res



X and RX port mus


MIPI V1.2/2.5Gbps MIPI DPHY CSI
















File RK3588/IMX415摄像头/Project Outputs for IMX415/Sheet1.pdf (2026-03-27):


VDDMIO P7 VDDMIO G11 VDDMIO A5 VDDMIO A4 VDDLSC P8 VDDLSC P6 VDDLSC F11 VDDLSC A6 VDDLSC A3 VDDLPL2 P4 VDDLPL1 P5 VDDLIF P3 VDDLIF C1 VDDLCN P9 VDDLCN A7 VDDHPX K8 VDDHPX K7 VDDHPX E8 VDDHPX E7 VDDHPX E6 VDDHAN K5 VDDHAN E5 VDDHAN E4





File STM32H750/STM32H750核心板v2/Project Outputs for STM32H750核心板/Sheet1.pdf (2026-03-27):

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

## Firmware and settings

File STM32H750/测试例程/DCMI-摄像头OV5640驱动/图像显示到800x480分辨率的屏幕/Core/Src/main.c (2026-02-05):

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
/* Includes ------------------------------------------------------------------*/
#include "main.h"

/* USER CODE BEGIN Includes */
#include "led.h"
#include "usart.h"
#include "sdram.h"  
#include "lcd_rgb.h"
#include "dcmi_ov5640.h"  

/* USER CODE END Includes */


DCMI_HandleTypeDef hdcmi;
DMA_HandleTypeDef hdma_dcmi;

DMA2D_HandleTypeDef hdma2d;

LTDC_HandleTypeDef hltdc;

UART_HandleTypeDef huart1;

SDRAM_HandleTypeDef hsdram1;

void SystemClock_Config(void);
static void MPU_Config(void);
static void MX_GPIO_Init(void);
static void MX_DMA_Init(void);
static void MX_DMA2D_Init(void);
static void MX_LTDC_Init(void);
static void MX_USART1_UART_Init(void);
static void MX_DCMI_Init(void);
static void MX_FMC_Init(void);
/* USER CODE BEGIN 0 */


/*
*	函 数 名: LCD_CopyBuffer
*
*	入口参数: x - 水平坐标
*			 	 y - 垂直坐标
*			 	 width  - 缓冲区的水平宽度
*				 height - 缓冲区的垂直宽度
*				 *color - 要复制的缓冲区地址
*				
*	函数功能: 在坐标 (x,y) 起始处复制缓冲区到显示区
*
*	说    明: 1. 使用DMA2D实现
*				 2. 要绘制的区域不能超过屏幕的显示区域 
*
*/

void LCD_CopyBuffer(uint16_t x, uint16_t y, uint16_t width, uint16_t height,uint16_t *color)
{

	DMA2D->CR	  &=	~(DMA2D_CR_START);				//	停止DMA2D
	DMA2D->CR		=	DMA2D_M2M;							//	存储器到存储器
	DMA2D->FGPFCCR	=	ColorMode_0;						//	设置颜色格式
   DMA2D->FGOR    =  0;										// 
	DMA2D->OOR		=	LCD_Width - width;				//	设置行偏移 	
	DMA2D->FGMAR   =  (uint32_t)color;		
	DMA2D->OMAR		=	LCD_MemoryAdd + BytesPerPixel_0*(LCD_Width * y + x);	// 地址;
	DMA2D->NLR		=	(width<<16)|(height);			//	设定长度和宽度		

	DMA2D->CR	  |=	DMA2D_CR_START;					//	启动DMA2D
	while (DMA2D->CR & DMA2D_CR_START) ;				//	等待传输完成
	
}

/* USER CODE END 0 */

/**
  * @brief  The application entry point.
  * @retval int
  */
int main(void)
{
  /* MPU Configuration--------------------------------------------------------*/
  MPU_Config();
/* Enable the CPU Cache */

  /* Enable I-Cache---------------------------------------------------------*/
  SCB_EnableICache();

  /* Enable D-Cache---------------------------------------------------------*/
  SCB_EnableDCache();

  /* MCU Configuration--------------------------------------------------------*/

  /* Reset of all peripherals, Initializes the Flash interface and the Systick. */
  HAL_Init();

  /* Configure the system clock */
  SystemClock_Config();

  /* Initialize all configured peripherals */
  MX_GPIO_Init();
  MX_DMA_Init();
  MX_DMA2D_Init();
  MX_LTDC_Init();
  MX_USART1_UART_Init();
  MX_DCMI_Init();
  MX_FMC_Init();
  /* USER CODE BEGIN 2 */
	LED_Init();					// 初始化LED引脚
	SDRAM_Initialization_Sequence(&hsdram1);	// 配置SDRAM相关时序和控制方式
	
	LCD_RGB_Init();		// 初始化屏幕
	DCMI_OV5640_Init();   			 	// DCMI以及OV5640初始化
	
	OV5640_AF_Download_Firmware();	// 写入自动对焦固件
	OV5640_AF_Trigger_Constant();		// 自动对焦 ，持续 触发，当OV5640检测到当前画面不在焦点时，会一直触发对焦
//	OV5640_AF_Trigger_Single();		//	自动对焦 ，触发 单次 
	
//	120度和160度的广角镜头默认的方向和带自动对焦的镜头不一样，用户可以根据实际去调整
//	OV5640_Set_Vertical_Flip( OV5640_Disable );		// 取消垂直翻转
//	OV5640_Set_Horizontal_Mirror( OV5640_Enable );	// 水平镜像
	
//>>>>DMA重要说明：
//
// 1.因为片外SDRAM速度慢，接收高分辨率图像带宽不够，而片内的SRAM不足以缓存一整张800*480的图像，
//   所以使用 片内SRAM 缓冲部分图像数据，然后将数据复制到片外SDRAM的方式，多次传输之后，就可以得到一张完整的图像
//
// 2.为了提高传输效率，这里使用DMA双缓冲机制，这样每传输完一次图像数据，CPU复制到SDRAM的同时，DMA会自动触发另一个缓冲传输，
//   而HAL库里，如果要使用DCMI+DMA双缓冲，需要数据量大于 65535*4=262140 字节才能使用，用户可以另写函数以实现双缓冲从而达到节省内存的目的

// 3.屏幕分辨率为800*480，也就是总共480行，每次传输行数为  DMA_Height（例程设置为96行），但是为了触发双缓冲，
//   实际DMA的数据大小设置为 96*2=192行，总数据量是 800*192*2（RGB565，一个像素占2字节） = 307200字节，满足触发双缓冲的条件
//
// 4.最后，因为DMA是按4字节处理的，所以将上面得到的数据/4，再写进DMA参数即可
//	
// 5.数据的搬运，在 stm32h7xx_it.c 文件 DMA2_Stream7_IRQHandler 函数完成
// 
	OV5640_DMA_Transmit_Continuous((uint32_t)Camera_Buffer,Display_Width*DMA_Height*2*2/4);	

	
  /* USER CODE END 2 */

  /* Infinite loop */
  /* USER CODE BEGIN WHILE */
  
		
  while (1)
  {
    /* USER CODE END WHILE */

    /* USER CODE BEGIN 3 */
		
		if (OV5640_FrameState == 1)
		{		
 
			LCD_CopyBuffer(0,0,Display_Width,Display_Height, (uint16_t *)Frame_Buffer);	// 将图像数据复制到屏幕
			LCD_DisplayString( 84 ,240,"FPS:");
			LCD_DisplayNumber( 132,240, OV5640_FPS,2) ;	// 显示帧率					

			OV5640_FrameState = 0;		// 清零标志位	
			LED1_Toggle;	
		}		
	  
  }
  /* USER CODE END 3 */
}

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
/* MPU Configuration */

void MPU_Config(void)
{
  MPU_Region_InitTypeDef MPU_InitStruct = {0};

  /* Disables the MPU */
  HAL_MPU_Disable();

  /** Initializes and configures the Region and the memory to be protected
  */
  MPU_InitStruct.Enable = MPU_REGION_ENABLE;
  MPU_InitStruct.Number = MPU_REGION_NUMBER0;
  MPU_InitStruct.BaseAddress = 0xC0000000;
  MPU_InitStruct.Size = MPU_REGION_SIZE_16MB;
  MPU_InitStruct.SubRegionDisable = 0x0;
  MPU_InitStruct.TypeExtField = MPU_TEX_LEVEL0;
  MPU_InitStruct.AccessPermission = MPU_REGION_FULL_ACCESS;
  MPU_InitStruct.DisableExec = MPU_INSTRUCTION_ACCESS_ENABLE;
  MPU_InitStruct.IsShareable = MPU_ACCESS_NOT_SHAREABLE;
  MPU_InitStruct.IsCacheable = MPU_ACCESS_CACHEABLE;
  MPU_InitStruct.IsBufferable = MPU_ACCESS_BUFFERABLE;

  HAL_MPU_ConfigRegion(&MPU_InitStruct);

  /** Initializes and configures the Region and the memory to be protected
  */
  MPU_InitStruct.Number = MPU_REGION_NUMBER1;
  MPU_InitStruct.BaseAddress = 0x24000000;
  MPU_InitStruct.Size = MPU_REGION_SIZE_512KB;
  MPU_InitStruct.IsShareable = MPU_ACCESS_SHAREABLE;

  HAL_MPU_ConfigRegion(&MPU_InitStruct);
  /* Enables the MPU */
  HAL_MPU_Enable(MPU_PRIVILEGED_DEFAULT);

}

/**
  * @brief  This function is executed in case of error occurrence.
  * @retval None
  */
void Error_Handler(void)
{
  /* USER CODE BEGIN Error_Handler_Debug */
  /* User can add his own implementation to report the HAL error return state */
  __disable_irq();
  while (1)
  {
    printf("error!\n");
    HAL_Delay(10);
  }
  /* USER CODE END Error_Handler_Debug */
}

#ifdef  USE_FULL_ASSERT
/**
  * @brief  Reports the name of the source file and the source line number
  *         where the assert_param error has occurred.
  * @param  file: pointer to the source file name
  * @param  line: assert_param error line source number
  * @retval None
  */
void assert_failed(uint8_t *file, uint32_t line)
{
  /* USER CODE BEGIN 6 */
  /* User can add his own implementation to report the file name and line number,
     ex: printf("Wrong parameters value: file %s on line %d\r\n", file, line) */
  /* USER CODE END 6 */
}
#endif /* USE_FULL_ASSERT */

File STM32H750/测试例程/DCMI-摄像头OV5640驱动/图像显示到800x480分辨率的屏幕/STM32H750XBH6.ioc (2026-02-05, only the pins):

Mcu.UserName=STM32H750XBHx
PA10.Signal=USART1_RX
PA4.Signal=DCMI_HSYNC
PA6.Signal=DCMI_PIXCLK
PA9.Signal=USART1_TX
PC0.Signal=FMC_SDNWE
PC6.Signal=DCMI_D0
PC7.Signal=DCMI_D1
PD0.Signal=FMC_D2_DA2
PD1.Signal=FMC_D3_DA3
PD10.Signal=FMC_D15_DA15
PD14.Signal=FMC_D0_DA0
PD15.Signal=FMC_D1_DA1
PD3.Signal=DCMI_D5
PD8.Signal=FMC_D13_DA13
PD9.Signal=FMC_D14_DA14
PE0.Signal=FMC_NBL0
PE1.Signal=FMC_NBL1
PE10.Signal=FMC_D7_DA7
PE11.Signal=FMC_D8_DA8
PE12.Signal=FMC_D9_DA9
PE13.Signal=FMC_D10_DA10
PE14.Signal=FMC_D11_DA11
PE15.Signal=FMC_D12_DA12
PE4.Signal=DCMI_D4
PE5.Signal=DCMI_D6
PE6.Signal=DCMI_D7
PE7.Signal=FMC_D4_DA4
PE8.Signal=FMC_D5_DA5
PE9.Signal=FMC_D6_DA6
PF0.Signal=FMC_A0
PF1.Signal=FMC_A1
PF11.Signal=FMC_SDNRAS
PF12.Signal=FMC_A6
PF13.Signal=FMC_A7
PF14.Signal=FMC_A8
PF15.Signal=FMC_A9
PF2.Signal=FMC_A2
PF3.Signal=FMC_A3
PF4.Signal=FMC_A4
PF5.Signal=FMC_A5
PG0.Signal=FMC_A10
PG1.Signal=FMC_A11
PG10.Signal=DCMI_D2
PG11.Signal=DCMI_D3
PG15.Signal=FMC_SDNCAS
PG4.Signal=FMC_A14_BA0
PG5.Signal=FMC_A15_BA1
PG8.Signal=FMC_SDCLK
PG9.Signal=DCMI_VSYNC
PH10.Signal=FMC_D18
PH11.Signal=FMC_D19
PH12.Signal=FMC_D20
PH13.Signal=FMC_D21
PH14.Signal=FMC_D22
PH15.Signal=FMC_D23
PH2.Signal=FMC_SDCKE0
PH3.Signal=FMC_SDNE0
PH8.Signal=FMC_D16
PH9.Signal=FMC_D17
PI0.Signal=FMC_D24
PI1.Signal=FMC_D25
PI10.Signal=FMC_D31
PI12.Signal=LTDC_HSYNC
PI13.Signal=LTDC_VSYNC
PI14.Signal=LTDC_CLK
PI15.Signal=LTDC_R0
PI2.Signal=FMC_D26
PI3.Signal=FMC_D27
PI4.Signal=FMC_NBL2
PI5.Signal=FMC_NBL3
PI6.Signal=FMC_D28
PI7.Signal=FMC_D29
PI9.Signal=FMC_D30
PJ0.Signal=LTDC_R1
PJ1.Signal=LTDC_R2
PJ10.Signal=LTDC_G3
PJ11.Signal=LTDC_G4
PJ12.Signal=LTDC_B0
PJ13.Signal=LTDC_B1
PJ14.Signal=LTDC_B2
PJ15.Signal=LTDC_B3
PJ2.Signal=LTDC_R3
PJ3.Signal=LTDC_R4
PJ4.Signal=LTDC_R5
PJ5.Signal=LTDC_R6
PJ6.Signal=LTDC_R7
PJ7.Signal=LTDC_G0
PJ8.Signal=LTDC_G1
PJ9.Signal=LTDC_G2
PK0.Signal=LTDC_G5
PK1.Signal=LTDC_G6
PK2.Signal=LTDC_G7
PK3.Signal=LTDC_B4
PK4.Signal=LTDC_B5
PK5.Signal=LTDC_B6
PK6.Signal=LTDC_B7
PK7.Signal=LTDC_DE

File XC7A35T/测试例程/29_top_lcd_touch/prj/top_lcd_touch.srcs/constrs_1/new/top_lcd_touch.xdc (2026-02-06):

#时序约束
create_clock -period 20.000 -name sys_clk [get_ports sys_clk]

#IO管脚约束
set_property -dict {PACKAGE_PIN R4 IOSTANDARD LVCMOS33} [get_ports sys_clk]
set_property -dict {PACKAGE_PIN U2 IOSTANDARD LVCMOS33} [get_ports sys_rst_n]

#--------------------------------RGB LCD------------------------------------------
#底板RGB LCD
set_property -dict {PACKAGE_PIN G13 IOSTANDARD LVCMOS33} [get_ports {lcd_rgb[0]}]
set_property -dict {PACKAGE_PIN H13 IOSTANDARD LVCMOS33} [get_ports {lcd_rgb[1]}]
set_property -dict {PACKAGE_PIN G15 IOSTANDARD LVCMOS33} [get_ports {lcd_rgb[2]}]
set_property -dict {PACKAGE_PIN H15 IOSTANDARD LVCMOS33} [get_ports {lcd_rgb[3]}]
set_property -dict {PACKAGE_PIN G16 IOSTANDARD LVCMOS33} [get_ports {lcd_rgb[4]}]
set_property -dict {PACKAGE_PIN G17 IOSTANDARD LVCMOS33} [get_ports {lcd_rgb[5]}]
set_property -dict {PACKAGE_PIN H17 IOSTANDARD LVCMOS33} [get_ports {lcd_rgb[6]}]
set_property -dict {PACKAGE_PIN J16 IOSTANDARD LVCMOS33} [get_ports {lcd_rgb[7]}]

set_property -dict {PACKAGE_PIN J17 IOSTANDARD LVCMOS33} [get_ports {lcd_rgb[8]}]
set_property -dict {PACKAGE_PIN K16 IOSTANDARD LVCMOS33} [get_ports {lcd_rgb[9]}]
set_property -dict {PACKAGE_PIN K17 IOSTANDARD LVCMOS33} [get_ports {lcd_rgb[10]}]
set_property -dict {PACKAGE_PIN L16 IOSTANDARD LVCMOS33} [get_ports {lcd_rgb[11]}]
set_property -dict {PACKAGE_PIN M21 IOSTANDARD LVCMOS33} [get_ports {lcd_rgb[12]}]
set_property -dict {PACKAGE_PIN H22 IOSTANDARD LVCMOS33} [get_ports {lcd_rgb[13]}]
set_property -dict {PACKAGE_PIN J21 IOSTANDARD LVCMOS33} [get_ports {lcd_rgb[14]}]
set_property -dict {PACKAGE_PIN J22 IOSTANDARD LVCMOS33} [get_ports {lcd_rgb[15]}]

set_property -dict {PACKAGE_PIN K21 IOSTANDARD LVCMOS33} [get_ports {lcd_rgb[16]}]
set_property -dict {PACKAGE_PIN K22 IOSTANDARD LVCMOS33} [get_ports {lcd_rgb[17]}]
set_property -dict {PACKAGE_PIN L20 IOSTANDARD LVCMOS33} [get_ports {lcd_rgb[18]}]
set_property -dict {PACKAGE_PIN L19 IOSTANDARD LVCMOS33} [get_ports {lcd_rgb[19]}]
set_property -dict {PACKAGE_PIN K19 IOSTANDARD LVCMOS33} [get_ports {lcd_rgb[20]}]
set_property -dict {PACKAGE_PIN K18 IOSTANDARD LVCMOS33} [get_ports {lcd_rgb[21]}]
set_property -dict {PACKAGE_PIN J20 IOSTANDARD LVCMOS33} [get_ports {lcd_rgb[22]}]
set_property -dict {PACKAGE_PIN J19 IOSTANDARD LVCMOS33} [get_ports {lcd_rgb[23]}]

set_property -dict {PACKAGE_PIN M15 IOSTANDARD LVCMOS33} [get_ports lcd_hs]
set_property -dict {PACKAGE_PIN H20 IOSTANDARD LVCMOS33} [get_ports lcd_vs]
set_property -dict {PACKAGE_PIN H19 IOSTANDARD LVCMOS33} [get_ports lcd_de]
set_property -dict {PACKAGE_PIN H18 IOSTANDARD LVCMOS33} [get_ports lcd_bl]
set_property -dict {PACKAGE_PIN M16 IOSTANDARD LVCMOS33} [get_ports lcd_clk]
set_property -dict {PACKAGE_PIN J15 IOSTANDARD LVCMOS33} [get_ports lcd_rst_n]

#LCD TOUCH
set_property -dict {PACKAGE_PIN L14 IOSTANDARD LVCMOS33} [get_ports touch_scl]
set_property -dict {PACKAGE_PIN G18 IOSTANDARD LVCMOS33} [get_ports touch_sda]
set_property -dict {PACKAGE_PIN K14 IOSTANDARD LVCMOS33} [get_ports touch_int]
set_property -dict {PACKAGE_PIN G20 IOSTANDARD LVCMOS33} [get_ports touch_rst_n]

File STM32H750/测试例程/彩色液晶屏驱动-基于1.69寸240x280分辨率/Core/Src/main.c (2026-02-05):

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
/* Includes ------------------------------------------------------------------*/
#include "main.h"

/* USER CODE BEGIN Includes */
#include "led.h"
#include "usart.h"
#include "lcd_spi_169.h"
/* USER CODE END Includes */


SPI_HandleTypeDef hspi6;

UART_HandleTypeDef huart1;

void SystemClock_Config(void);
static void MX_GPIO_Init(void);
static void MX_USART1_UART_Init(void);
static void MX_SPI6_Init(void);
/* USER CODE BEGIN 0 */



/*************************************************************************************************
*	函 数 名:	LCD_Test_Clear
*
*	函数功能:	清屏测试
*************************************************************************************************/
void LCD_Test_Clear(void)
{
	uint8_t	i = 0;			// 计数变量
	
	LCD_SetDirection(Direction_V);		
	LCD_SetTextFont(&CH_Font24);			// 设置2424中文字体,ASCII字体对应为2412
	LCD_SetColor(LCD_BLACK);				// 设置画笔颜色

	for(i=0;i<8;i++)
	{
		switch (i)		// 切换背景色
		{
			case 0: LCD_SetBackColor(LIGHT_RED); 		break;	
			case 1: LCD_SetBackColor(LIGHT_GREEN); 	break;				
			case 2: LCD_SetBackColor(LIGHT_BLUE); 		break;
			case 3: LCD_SetBackColor(LIGHT_YELLOW); 	break;
			case 4: LCD_SetBackColor(LIGHT_CYAN);		break;
			case 5: LCD_SetBackColor(LIGHT_GREY); 		break;
			case 6: LCD_SetBackColor(LIGHT_MAGENTA); 	break;
			case 7: LCD_SetBackColor(LCD_WHITE); 		break;			
			default:	break;			
		}
		LCD_Clear();		// 清屏
		LCD_DisplayText(13, 70,"STM32H7 刷屏测试");
		LCD_DisplayText(13,106,"屏幕分辨率:240*280");
		LCD_DisplayText(13,142,"控制器:ST7789");	
		HAL_Delay(1000);	// 延时
	}
}


/*************************************************************************************************
*	函 数 名:	LCD_Test_Text
*
*	函数功能:	文本显示测试
*
*	说    明:	显示文本，包括各种字体大小的中文和ASCII字符 
*************************************************************************************************/
void LCD_Test_Text(void)
{
	LCD_SetBackColor(LCD_BLACK); 			//	设置背景色
	LCD_Clear(); 								// 清屏
	
	LCD_SetColor(LCD_WHITE);
	LCD_SetAsciiFont(&ASCII_Font32); LCD_DisplayString(0, 20,"!#$'()*+,-.0123"); 						    		
	LCD_SetAsciiFont(&ASCII_Font24); LCD_DisplayString(0, 52,"!#$'()*+,-.012345678"); 				   
	LCD_SetAsciiFont(&ASCII_Font20); LCD_DisplayString(0, 76,"!#$'()*+,-.0123456789:;<");      	
	LCD_SetAsciiFont(&ASCII_Font16); LCD_DisplayString(0, 96,"!#$'()*+,-.0123456789:;<=>?@AB"); 	
	LCD_SetAsciiFont(&ASCII_Font12); LCD_DisplayString(0,112,"!#$'()*+,-.0123456789:;<=>?@ABCDEFGHIJKL"); 	
																																		
	LCD_SetColor(LCD_CYAN);                                                                             
	LCD_SetAsciiFont(&ASCII_Font12); LCD_DisplayString(0,124,"!#&'()*+,-.0123456789:;<=>?@ABCDEFGHIJKL"); 	
	LCD_SetAsciiFont(&ASCII_Font16); LCD_DisplayString(0,136,"!#&'()*+,-.0123456789:;<=>?@AB"); 	
	LCD_SetAsciiFont(&ASCII_Font20); LCD_DisplayString(0,152,"!#&'()*+,-.0123456789:;<");		  	
	LCD_SetAsciiFont(&ASCII_Font24); LCD_DisplayString(0,172,"!#&'()*+,-.012345678"); 				  	
	LCD_SetAsciiFont(&ASCII_Font32); LCD_DisplayString(0,196,"!#&'()*+,-.0123"); 							  		

	LCD_SetTextFont(&CH_Font24);			// 设置2424中文字体,ASCII字体对应为2412
	LCD_SetColor(LCD_YELLOW);				// 设置画笔，黄色
	LCD_DisplayText(0, 236,"ASCII字符集");

	HAL_Delay(2000);	// 延时等待
	LCD_Clear(); 								// 清屏

	LCD_SetTextFont(&CH_Font12);			// 设置1212中文字体,ASCII字体对应为1206
	LCD_SetColor(0X8AC6D1);					// 设置画笔
	LCD_DisplayText(14, 30,"1212:反客科技");	
	
	LCD_SetTextFont(&CH_Font16);			// 设置1616中文字体,ASCII字体对应为1608
	LCD_SetColor(0XC5E1A5);					// 设置画笔
	LCD_DisplayText(14, 50,"1616:反客科技");		
	
	LCD_SetTextFont(&CH_Font20);			// 设置2020中文字体,ASCII字体对应为2010
	LCD_SetColor(0XFFB549);					// 设置画笔
	LCD_DisplayText(14, 80,"2020:反客科技");		

	LCD_SetTextFont(&CH_Font24);			// 设置2424中文字体,ASCII字体对应为2412
	LCD_SetColor(0XFF585D);					// 设置画笔
	LCD_DisplayText(14,110,"2424:反客科技");		

	LCD_SetTextFont(&CH_Font32);			// 设置3232中文字体,ASCII字体对应为3216
	LCD_SetColor(0xFFB6B9);					// 设置画笔
	LCD_DisplayText(14,150,"3232:反客科技");		

	LCD_SetTextFont(&CH_Font24);			// 设置2424中文字体,ASCII字体对应为2412
	LCD_SetColor(LCD_WHITE);
 	LCD_DisplayText(14,200,"中文显示");	  

	HAL_Delay(2000);	// 延时等待
}
/************************************************************************************************
*	函 数 名:	LCD_Test_Variable
*
*	函数功能:	变量显示，包括整数和小数
*************************************************************************************************/
void LCD_Test_Variable (void)
{
	uint16_t i;					// 计数变量
	int32_t	a = 0;			// 定义整数变量，用于测试
	int32_t	b = 0;			// 定义整数变量，用于测试
	int32_t	c = 0;			// 定义整数变量，用于测试

	double p = 3.1415926;	// 定义浮点数变量，用于测试
	double f = -1234.1234;	// 定义浮点数变量，用于测试
	
	LCD_SetBackColor(LCD_BLACK); 			//	设置背景色
	LCD_Clear(); 								// 清屏
	
   LCD_SetTextFont(&CH_Font24);     
	LCD_SetColor(LIGHT_CYAN);					// 设置画笔，蓝绿色		
	LCD_DisplayText(0,30,"正数:");				
	LCD_DisplayText(0,60,"负数:");					
				
	LCD_SetColor(LIGHT_YELLOW);				// 设置画笔，亮黄色		
	LCD_DisplayText(0,100,"填充空格:");	
	LCD_DisplayText(0,130,"填充0:");	
	
	LCD_SetColor(LIGHT_RED);					// 设置画笔	，亮红色		
	LCD_DisplayText(0,170,"正小数:");	
	LCD_DisplayText(0,200,"负小数:");		
	
	for(i=0;i<100;i++)
   {
		LCD_SetColor(LIGHT_CYAN);								// 设置画笔	，蓝绿色	
		LCD_ShowNumMode(Fill_Space);							// 多余位填充空格
		LCD_DisplayNumber( 80,30, b+i*10, 4) ;				// 显示变量			
		LCD_DisplayNumber( 80,60, c-i*10, 4) ;				// 显示变量			
		
		LCD_SetColor(LIGHT_YELLOW);								// 设置画笔，亮黄色	

		LCD_ShowNumMode(Fill_Space);								// 多余位填充 空格
		LCD_DisplayNumber( 130,100, a+i*150, 8) ;				// 显示变量		

		LCD_ShowNumMode(Fill_Zero);								// 多余位填充0      
		LCD_DisplayNumber( 130,130, b+i*150, 8) ;				// 显示变量			
		
		LCD_SetColor(LIGHT_RED);									// 设置画笔，亮红色			
		LCD_ShowNumMode(Fill_Space);								// 多余位填充空格		
		LCD_DisplayDecimals( 100,170, p+i*0.1,  6,3);		// 显示小数	
		LCD_DisplayDecimals( 100,200, f+i*0.01, 11,4);		// 显示小数		
		
		HAL_Delay(15);				
   }
	HAL_Delay(2500);		
}
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

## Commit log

2026-02-05 add STM32H750
    [0.96_OLED_screen.PrjPcb, 1.69_SPI_screen.PrjPcb, 4.3_RGB_LCD.PrjPcb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]
2026-02-05 modify STM32H750 Debugging Notes
2026-02-06 add XC7A35T and change the README of STM32H750
    [4.3寸RGB屏幕.SLDPRT, 4.3寸RGB驱动.SLDPRT, M2-10铜柱.SLDPRT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]
2026-02-09 add RK3588 and H616 and README
    [1.BTB.SchDoc, 1.PMIC_1.SchDoc, 10.PCIE2.SchDoc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]
2026-03-27 clear cache and information
    [0.96_OLED_screen.PrjPcb, 0.PCB1.PcbDoc, 1.69_SPI_screen.PrjPcb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]
2026-03-27 generate clean schlib and pcblib,link schdoc with pcblib
    [0.96_OLED_screen.PrjPcb, 0.96_OLED_screen.SCHLIB, 0.PCB1.PcbLib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]
2026-03-27 link schdoc with schlib
    [1.BTB.SchDoc, 1.PMIC_1.SchDoc, 10.PCIE2.SchDoc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]
2026-03-27 update all components link
    [0.96_OLED_screen.PrjPcb, 0.PCB1.PcbDoc, 1.69_SPI_screen.PrjPcb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]
2026-03-31 clear information
    [0.96_OLED_screen.PrjPcb, 1.69_SPI_screen.PrjPcb, 4.3_RGB_LCD.PrjPcb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]

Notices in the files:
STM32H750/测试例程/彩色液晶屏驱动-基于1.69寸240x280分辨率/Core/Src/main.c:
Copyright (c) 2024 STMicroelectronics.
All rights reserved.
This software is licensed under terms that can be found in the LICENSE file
